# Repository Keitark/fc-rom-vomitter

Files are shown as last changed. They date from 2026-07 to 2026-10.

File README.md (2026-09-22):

# FC ROM Vomitter

[日本語](README_JA.md) · [Schematic PDF](docs/nescart-fc-schematic.pdf) · [Manufacturing release](manufacturing/rev-a-fc/)








**Upload an NROM homebrew ROM from a phone, load it into SRAM, and run it on a Japanese Famicom.** No EPROM programmer, cartridge swapping, or battery-backed memory.

The native 60-pin Famicom Rev A-FC is the primary design. A frozen 72-pin NES-001 predecessor is preserved under [`experimental/nes/`](experimental/nes/) for comparison and further development; it is not part of the FC manufacturing release. A separately isolated [ESP32-S3 two-bank Mapper-3 experiment](experimental/mapper3-esp32/) records the post-release bodge wiring, firmware, tests, and limited bench evidence without changing the stable NROM release.

## Actual board views

| Component / parts side | Artwork side |
|---|---|
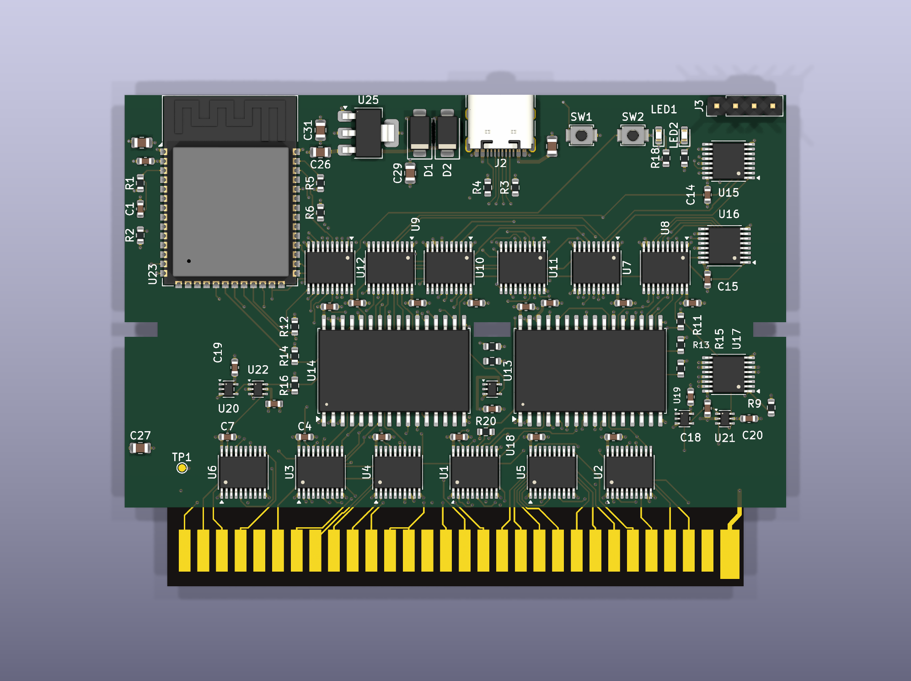
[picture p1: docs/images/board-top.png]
Actual KiCad component-side render of Rev A-FC
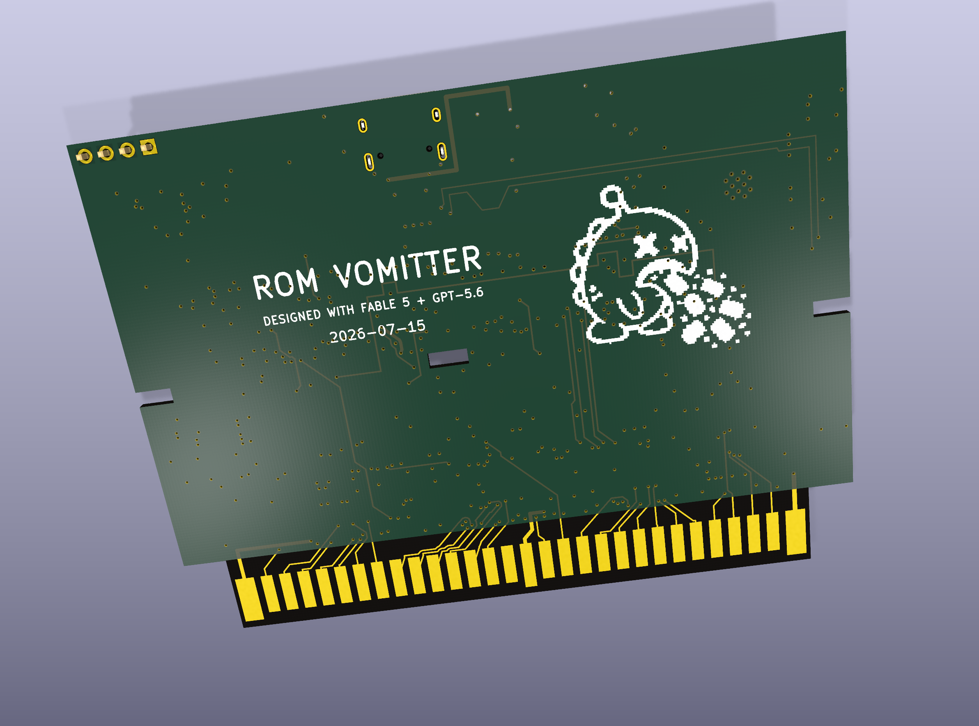
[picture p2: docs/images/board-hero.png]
Actual KiCad artwork-side render of Rev A-FC
|  |  |

> [!WARNING]
> Rev A-FC has a fabrication-complete design and build-tested firmware, but the assembled hardware has not completed bench validation. Do not insert an untested board into a Famicom. The 10 mm taller PCB also needs a custom shell; original cartridge-shell compatibility is not claimed.

## What it does

1. The ESP32-S3 creates a Wi-Fi access point and browser upload page.
2. An uploaded mapper-0 `.nes` image is CRC-checked and committed to one of two flash slots.
3. At power-up, the ESP32 isolates the console bus, copies PRG and CHR data into SRAM, and verifies every byte.
4. The bus changes to RUN ownership and the blue LED becomes solid.
5. Press the **Famicom console's red RESET button** to start the game.

For bench and unattended workflows, the firmware also supports [USB-C direct
upload and optional HTTPS cloud polling](docs/rom-delivery.md). All delivery
modes use the same validated atomic flash and SRAM-loading path.

Unlike the front-loader NES, the Famicom has no CIC lockout circuit. The cartridge therefore cannot automatically hold and release console reset; the explicit RESET press is part of the Rev A-FC user flow.

```mermaid
flowchart LR
    phone["Phone / laptop"] -->|"Wi-Fi upload"| esp["ESP32-S3"]
    esp --> flash["Two atomic flash slots"]
    flash -->|"CRC-verified copy"| sram["PRG + CHR SRAM"]
    esp -->|"LOAD / RUN ownership"| buffers["74LVC bus isolation"]
    sram --> buffers --> edge["60-pin Famicom edge"]
    edge --> console["Famicom CPU + PPU"]
    reset["Press console RESET"] -.-> console
```

## Hardware at a glance

| Area | Rev A-FC |
|---|---|
| Console | Japanese Famicom 60-pin cartridge slot |
| Supported image | iNES mapper 0 / NROM, 16 or 32 KiB PRG, 8 KiB CHR |
| Loader | ESP32-S3-WROOM-1-N8, SoftAP + browser upload |
| Game storage | Two atomic slots in ESP32 flash |
| Console memory | Two CY62128 128K × 8 SRAMs |
| Bus safety | 74LVC245 isolation with fail-safe LOAD/RUN defaults |
| PCB | 6 layers, 90.0 × 66.8 mm envelope, 1.2 mm, 60 gold fingers |
| Audio | Famicom sound loop through fitted 0 Ω R20 |
| Power/debug | Console 5 V plus USB-C bench power and native USB flashing |

The board keeps the standard-width tongue, connector datum, notches, centre slot, and 1.2 mm mating thickness. Only the edge opposite the fingers is extended by 10 mm for routing space.

## Project status

| Gate | Status | Evidence |
|---|---|---|
| Schematic ERC | **PASS** — 0 errors, 8 reviewed warnings | [`erc.json`](manufacturing/rev-a-fc/evidence/erc.json) |
| PCB connectivity | **PASS** — 0 raw opens | [`drc-classified.json`](manufacturing/rev-a-fc/evidence/drc-classified.json) |
| Classified DRC | **PASS** — 0 real errors | [`drc-classified.json`](manufacturing/rev-a-fc/evidence/drc-classified.json) |
| Layout policy | **PASS** — 0 failures | [`layout-check.txt`](manufacturing/rev-a-fc/evidence/layout-check.txt) |
| CPL registration | **PASS** — 79 fitted references, 0 unresolved | [`cpl-audit.txt`](manufacturing/rev-a-fc/evidence/cpl-audit.txt) |
| Firmware host tests/build | **PASS in preparation; continuously checked by CI** | [workflow](.github/workflows/validate.yml) |
| Electrical/mechanical bench validation | **PENDING** | [bring-up checklist](docs/bring-up.md) |

“0 opens” is not treated as completion by itself. The release also requires classified DRC, power continuity, reference-plane checks, silkscreen review, CPL registration, and visual inspection.

## Quick start for developers

### Firmware

Install [PlatformIO](https://platformio.org/), then:

```powershell
cd firmware
pio run -e esp32-s3
```

Host-test the iNES parser, CRC, and atomic-slot selection:

```powershell
cmake -S host_tests -B host_tests/build
cmake --build host_tests/build --config Release
ctest --test-dir host_tests/build -C Release --output-on-failure
```

The default development access-point password is `vomit-roms`. Change it through menuconfig before using the cartridge in a shared or public environment.

### Hardware

Open [`hardware/nescart-fc.kicad_pro`](hardware/nescart-fc.kicad_pro) in KiCad 10. The checked-in PCB is the exact revision used to create the public manufacturing package.

The schematic is generator-backed:

```powershell
python hardware/tools/gen_sch.py
```

Edit the netlist tables in `gen_sch.py`; do not hand-edit generated connectivity in the `.kicad_sch` files. See [hardware/README.md](hardware/README.md) before regenerating anything.

## Manufacturing release

[`manufacturing/rev-a-fc/`](manufacturing/rev-a-fc/) contains:

- revision-locked Gerber + drill ZIP;
- engineering and JLCPCB-format BOM/CPL files;
- CPL registration audit and assembly drawing;
- DRC/ERC/layout/silkscreen evidence;
- top and bottom manufacturing views and paste-stencil preview;
- a SHA-256 manifest checked in CI.

These files are published for review and reproducibility, **not as a recommendation to order an unvalidated board unchanged**. Read [manufacturing notes](docs/manufacturing.md) and the [bench bring-up gate](docs/bring-up.md) first.

## Experimental NES variant

[`experimental/nes/`](experimental/nes/) preserves the earlier 72-pin front-loader NES-001 design. It uses an ATtiny CIC clone to hold the console in reset while the ESP32 loads SRAM, which is materially different from the manual-reset FC flow. The snapshot passed its recorded schematic and PCB checks, but its assembly-placement gate and hardware validation are incomplete, so it is intentionally **not fabrication-ready**.

## Experimental Mapper 3 modification

[`experimental/mapper3-esp32/`](experimental/mapper3-esp32/) documents an
ESP32-S3-only, two-bank CNROM modification applied to one assembled Rev A-FC
board. It adds no new processor: a core-1 IRAM polling loop observes CPU D0 and
the existing decoded control signals, then drives CHR SRAM A13 through GPIO36.

Host tests, the ESP32 build, Mapper-0 regression, and one two-bank Mapper-3
target passed their recorded checks. Electrical margin, worst-case timing,
long-run Wi-Fi stress, and multi-board repeatability remain `USER_REVIEW`.
This is a reproducible experiment, not a revised manufacturing release.

## Repository map

```text
hardware/                 KiCad 10 release source, libraries, models and core generators
firmware/                 ESP-IDF / PlatformIO loader firmware and host tests
manufacturing/rev-a-fc/   sanitized Gerber, BOM, CPL, evidence and hashes
experimental/nes/          frozen 72-pin NES-001 design snapshot (not released)
experimental/mapper3-esp32/ post-release two-bank CNROM bodge and firmware
docs/                     architecture, bring-up, manufacturing and licensing notes
scripts/                  repository and release-integrity checks
```

## Documentation

- [Architecture and safety invariants](docs/architecture.md)
- [First-board bring-up](docs/bring-up.md)
- [Browser, USB-C and cloud ROM delivery](docs/rom-delivery.md)
- [Manufacturing and release interpretation](docs/manufacturing.md)
- [FC60 pin map](hardware/docs/pinout-fc.md)
- [Layout and electrical guidance](hardware/docs/layout-electrical-guidance.md)
- [Licensing and attribution](docs/licensing.md)
- [Japanese README / 日本語](README_JA.md)
- [Experimental ESP32-S3 Mapper 3 modification](experimental/mapper3-esp32/)

## License and credits

This is a dual-licensed repository. Software and original general documentation are MIT. KiCad hardware design files, manufacturing artifacts, and designated visual/model assets are CC BY-SA 4.0; see [the exact scope and attributions](docs/licensing.md).

Connector behavior and dimensional research reference the community-maintained [NESdev Wiki](https://www.nesdev.org/wiki/Cartridge_connector) and the [NES/Famicom cartridge dimensions project](https://github.com/Gumball2415/NES-Famicom-Cartridge-Dimensions). The SRAM STEP model is from KiCad Packages3D and retains its upstream license and exception.

Famicom and Nintendo are trademarks of Nintendo. This independent project is not affiliated with or endorsed by Nintendo. Use homebrew software you have the right to run.

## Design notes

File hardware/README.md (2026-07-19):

# Hardware source

`nescart-fc.kicad_pro` is the KiCad 10 entry point. The checked-in PCB and
schematic match the SHA-256 values recorded in
`../manufacturing/rev-a-fc/release-manifest.json`.

## Sources of truth

- Electrical connectivity: `tools/gen_sch.py` and its generated hierarchical sheets.
- FC60 edge geometry: `tools/fc_geometry.py` and `tools/gen_edge_footprint.py`.
- Released routing/placement: `nescart-fc.kicad_pcb` (revision-locked snapshot).
- Fabrication constraints: `docs/DESIGN-CONSTRAINTS.md`.
- Part and placement mapping: `docs/sourcing-lock.csv` and `docs/cpl-overrides.csv`.

Do not hand-edit generated schematic connectivity. Regenerate it from the
tables in `gen_sch.py`, then compare the resulting pin/net map and run ERC.

## Required release gates

1. ERC has zero errors; expected warnings must be reviewed.
2. Raw unconnected items are zero.
3. Classified DRC has zero real errors and zero power disconnects.
4. `layout_check.py` reports `0 FAIL`.
5. Both sides are rendered and visually inspected.
6. Every fitted CPL reference is reconciled and visually checked after vendor import.
7. Gerber, drill, BOM, CPL and evidence files come from the same PCB revision.

KiCad's bundled Python is required for scripts importing `pcbnew`.

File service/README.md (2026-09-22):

# Cloudflare exhibition service

This Worker implements the planned anonymous ROM queue in
[`docs/expo-cloud-service.md`](../docs/expo-cloud-service.md). It stores queue
metadata in D1 and validated iNES payloads in a private R2 bucket. No ROM is
included in this repository or its tests; the integration test synthesizes a
minimal byte-pattern fixture.

## Visitor page

The public page is **Famicom Game Drop**. It defaults to Japanese, has an
English switch and explains the three-step upload flow. It translates upload
errors and job states while keeping
the existing `/api/public/jobs` protocol. A status URL can be saved and
reopened; the token stays in the URL fragment.

Visitor form uploads appear in the public gallery by default. The uploader
can instead check **Keep this game private**; raw API uploads remain private.
An optional comment is displayed only for public games. Names are visible to
staff only unless the uploader separately opts to publish one. The gallery
does not expose ROM download URLs. Existing one-hour expiry is unchanged.

The page explicitly says that physical cartridge pickup is unverified. A
successful upload proves validation and queue admission, not that the game
has changed on a physical Famicom.

## Operator-controlled dispatch

Open `/operator` and enter the operator token. The page is Japanese-first with
an English switch. The token is submitted once and never saved in browser
storage. A 12-hour, HttpOnly, same-site session cookie keeps this browser signed
in across reloads; use **Sign out** on a shared machine. A valid visitor upload
remains queued but **unreleased**. The operator presses **Send next game** to
release exactly one waiting item. A second item cannot be released while one
is queued for the cartridge, claimed, downloading, or deferred. The cartridge
polls `/api/device/v2/next` and claims only released work. Staff may pause the
queue or cancel a waiting item. A powered-on console may be interrupted only
when the cartridge advertises that its locally tested configuration permits
it; staff must then press the Famicom RESET button after the new image is
verified. This last step is not yet physically validated.

The operator can also withdraw a public-gallery listing without cancelling
the source ROM submission or already queued plays. Names and comments in the
operator queue require the operator token and are cleared when the source job
expires or is cancelled.

## Local verification

```powershell
cd service
npm install
npm run check
npm test
```

The integration test starts `wrangler dev` with local D1/R2 emulation and
exercises upload, validation, duplicate rejection, HMAC authentication, replay
rejection, operator release, duplicate-release prevention, powered-console
policy, job lease, private download, idempotent result, public status,
default-public/private upload options, name privacy, gallery withdrawal, and
operator pause/resume, one-time browser login, session expiry/revocation, and
same-origin checks for cookie-authenticated actions.

## Local interactive service

Create an ignored `service/.dev.vars`:

```dotenv
DEVICE_HMAC_SECRET=replace-with-at-least-32-random-characters
OPERATOR_TOKEN=replace-with-a-separate-random-token
RATE_LIMIT_SALT=replace-with-a-third-random-value
```

Then run:

```powershell
npm run db:local
npm run dev
```

Open `http://127.0.0.1:8787`. Do not use real credentials or copyrighted ROM
images in repository tests.

## Staging deployment

Provision one D1 database and one private R2 bucket, put the D1 identifier in
`wrangler.toml`, apply all migrations remotely, set all three secrets with
`wrangler secret put`, then deploy. The `workers.dev` hostname is the staging
endpoint; attaching a custom domain is a separate, reviewed step.

After deployment, verify the real D1/R2/HMAC path using a generated mapper-0
fixture. Supply secrets only through the process environment; the script does
not print them or use a copyrighted ROM:

```powershell
$env:SERVICE_URL = "https://your-staging-worker.workers.dev"
$env:DEVICE_HMAC_SECRET = "..."
$env:OPERATOR_TOKEN = "..."
npm run test:remote
```

The device signs every request using the canonical string defined in
`src/auth.ts`. Secrets are per-device deployment configuration and must not be
compiled into public firmware artifacts.

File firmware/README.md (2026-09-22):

# ROM Vomitter FC firmware

ESP-IDF firmware for the released `hardware-fc` ESP32-S3-WROOM-1-N8 board.
The new exhibition queue client builds, but remains **hardware-unvalidated**:
building it does not mean it has been flashed to, or tested on, the cartridge.

## Current verification status

- **PASS:** host tests for iNES normalization, CRC32, and atomic slot selection.
- **PASS:** ESP32-S3-N8 target build with PlatformIO and ESP-IDF 5.5.0.
- **PENDING HARDWARE:** native-USB flashing, GPIO timing/polarity, SRAM walking-bit
  tests, current/thermal measurements, Wi-Fi operation, and Famicom boot.

A successful build proves that the firmware compiles and fits. It does not prove
the released PCB's electrical behavior, so the first-board gate below remains
mandatory.

## Implemented preparation

- Released FC GPIO map from `hardware-fc/tools/gen_sch.py`.
- Safe LOAD/RUN sequencing with MCU and console data buffers disabled before
  ownership changes.
- Strict mapper-0 iNES validation: 16/32 KiB PRG, 8 KiB CHR, horizontal or
  vertical mirroring, optional trainer stripping, NROM-128 PRG mirroring.
- Two 64 KiB flash slots. Payload is written and CRC-verified before the commit
  metadata is written, so power loss cannot erase the previous valid image.
- PRG and CHR SRAM write plus byte-for-byte readback verification.
- Wi-Fi SoftAP and browser upload page at `http://192.168.4.1`.
- FC-specific UX: solid blue means READY; then press the **console's red RESET
  button**. Slow blink means no image; fast blink means transfer/load.
- Conservative 11 dBm Wi-Fi TX cap until rail and regulator measurements exist.
- Optional exhibition mode: signed polling of the Cloudflare queue. A visitor
  upload waits until an operator presses **Send next game**; the cartridge then
  fetches one released ROM, independently verifies its bytes and hashes, and
  uses the same flash/SRAM installation path. The original fixed-URL pull mode
  remains selectable.

The default SoftAP password is `vomit-roms`; change it in menuconfig for any
public or shared deployment.

## Exhibition queue configuration (not yet tested on hardware)

In `menuconfig`, enable cloud pull and its **operator-dispatched queue** mode.
Set the venue Wi-Fi SSID/password, the service origin (for example,
`https://fc-rom-vomitter-expo-staging.keitark.workers.dev`), a unique device ID,
and a 32–256 character device HMAC secret matching the Worker's private secret.
Enable **allow console reload** only for a supervised bench test after proving
bus isolation and reset behavior with an oscilloscope. When enabled, an
operator dispatch can interrupt a powered-on game; after READY, press the
Famicom's RESET button. Otherwise the cartridge waits for a safe power state.

The device credentials are compile-time settings. Never commit a generated
`sdkconfig` containing them or distribute a credential-bearing binary. The
`esp32-s3-cloud-ci` build uses dummy credentials solely to check compilation.
The SoftAP upload remains the local recovery path; the public Worker cannot
directly push bytes to a cartridge that is offline or not running this mode.

The queue client here is built from the mapper-0 firmware. The separately
patched Mapper 3/CNROM cartridge runs a timing-critical bank-switch task and
**must not be flashed with this binary**: its mapper support is not integrated
into this target. Before an exhibition deployment, merge the queue client into
that firmware, keep HTTP on core 0 and the bank-switch loop on core 1, then
measure bank-switch correctness and 3.3 V rail behavior during idle polling,
download, and powered-console reload. Wi-Fi/polling must not be called
``no impact'' merely because this target compiles.

## Build without a board

```powershell
cd firmware
pio run -e esp32-s3
```

Host-test the parser, CRC and atomic-slot selection:

```powershell
cmake -S host_tests -B host_tests/build -G "Visual Studio 16 2019" -A x64
cmake --build host_tests/build --config Release
ctest --test-dir host_tests/build -C Release --output-on-failure
```

## First-board bring-up gate

Do not insert an untested board into a Famicom. Use current-limited USB bench
power first:

```powershell
cd firmware
pio run -e esp32-s3 -t upload --upload-port COMx
pio device monitor --port COMx --baud 115200
```

Replace `COMx` with the native-USB port. If automatic download mode does not
start, hold **BOOT**, tap **ESP RST**, release **BOOT**, and retry the upload.

1. Inspect 5 V and 3.3 V rails, regulator temperature, and idle current.
2. Flash over native USB using BOOT + ESP RST; confirm UART/USB logs.
3. With no console attached, verify the blue LED patterns and SoftAP upload.
4. Probe `LOAD_MODE`, both MCU enable lines, `/WE`, and `/OE`; confirm no
   simultaneous MCU/console ownership.
5. Run walking-bit and address tests on both SRAMs before loading a ROM.
6. Confirm flash-slot power-loss recovery by interrupting an upload.
7. Only then insert with console power off, wait for solid READY, and press the
   console RESET button to run the test ROM.

The loader deliberately remains in isolated LOAD topology when only USB power
is present. A console-power rising event reloads/verifies SRAM before RUN.

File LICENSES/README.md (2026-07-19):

# License map

- `../LICENSE`: MIT for software and original general documentation.
- `CC-BY-SA-4.0.txt`: Creative Commons Attribution-ShareAlike 4.0 International for hardware design and designated assets.
- Per-file headers and `../docs/licensing.md` take precedence for third-party material.

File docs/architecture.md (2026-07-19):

# Architecture and safety invariants

## Operating model

The Famicom starts much faster than the ESP32-S3. Rev A-FC therefore does not
promise an automatic clean boot. During loader startup, hardware defaults keep
the MCU and console from driving the SRAM buses simultaneously. Once a valid
image is loaded and verified, the user starts execution with the console RESET
button.

```mermaid
sequenceDiagram
    participant FC as Famicom
    participant Gate as Buffer ownership logic
    participant ESP as ESP32-S3
    participant Flash as Atomic flash slots
    participant SRAM as PRG/CHR SRAM

    FC->>Gate: Console power rises
    Gate->>FC: Console bus isolated from SRAM
    ESP->>Flash: Select last valid committed image
    ESP->>SRAM: Copy PRG + CHR in LOAD mode
    ESP->>SRAM: Byte-for-byte readback + CRC
    ESP->>Gate: Change ownership only while MCU/console are isolated
    Gate->>FC: RUN mode; SRAM visible to console
    ESP-->>FC: Solid blue READY indication
    Note over FC: User presses console RESET
    FC->>SRAM: Fetch reset vector and execute ROM
```

## Non-negotiable invariants

- Console-side buffers and MCU-side drivers must never be enabled together.
- Bus ownership changes only through the isolated transition state.
- All ESP32 bus GPIOs remain Hi-Z or at defined safe levels until firmware takes control.
- SRAM contents are disposable; the committed ESP32 flash slot is authoritative.
- SRAM readback must pass before RUN mode.
- USB-only bench power must not backfeed the console edge.
- The Famicom audio path must return through fitted R20 (0 Ω), or the console may be silent.
- The console-facing tongue, notches, centre slot, J1 datum and 1.2 mm thickness are mechanical constraints, not layout suggestions.

## Supported ROM model

Rev A-FC deliberately implements mapper 0 only:

- iNES input;
- 16 KiB or 32 KiB PRG ROM;
- 8 KiB CHR ROM;
- horizontal or vertical nametable mirroring;
- optional trainer stripping;
- NROM-128 PRG mirroring.

Other mappers, save RAM, expansion audio mixing and instant-on stub ROMs are future work.

## Power

The board can be powered from the console or USB-C for isolated bench work.
The current release uses an AMS1117-class 3.3 V regulator and must pass current,
dropout and thermal measurement before console use. A successful firmware build
or DRC result is not evidence of a safe power budget.

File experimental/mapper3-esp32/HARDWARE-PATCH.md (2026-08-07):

# ESP32-only two-bank CNROM hardware patch

## Scope and warning

This rework exposes three mapper-observation inputs to the onboard ESP32-S3
and lets GPIO36 drive CHR SRAM A13. It is for an already-built Rev A-FC board.
It is not a fabrication-ready schematic or PCB revision.

Disconnect USB and remove the cartridge from the console before continuity or
soldering work. Confirm every point by KiCad net name and continuity on the
actual board; reference designators alone are insufficient.

## Preferred signal wiring

| ESP32 signal | Source / destination | Preferred implementation |
|---|---|---|
| GPIO36 output | U14 pin 28, CHR A13 | Lift U14 pin 28 from its GND pad; wire TP1 to the isolated lead |
| GPIO42 input | CPU D0 | Lift the unused U2 pin 9 from GND, wire CPU D0 to that lead, then wire U2 pin 11 to U23 pad 35 / GPIO42 |
| GPIO43 input | `ROMSEL_inv` | U19 pin 4 to J3 pin 2 |
| GPIO44 input | `PRG_EN_n` | U21 pin 4 to J3 pin 3 |

U2 is the preferred CPU-D0 path because its spare channel performs the
5 V-to-3.3 V interface on the released board. Do not connect raw CPU D0
directly to an ESP32-S3 GPIO.

GPIO43 and GPIO44 reuse J3 UART pins. Do not attach a UART adapter while the
mapper firmware is running.

## Tested rescue path after U2 lead damage

On the single bench board, U2 pin 9 was lost during rework. The temporary
repair connected CPU D0 through 4.7 kΩ to the GPIO42 node, with 10 kΩ from
that node to GND. U2 pin 11 was disconnected from GPIO42.

```text
CPU D0 ---- 4.7 kΩ ----+---- GPIO42
                       |
                      10 kΩ
                       |
                      GND
```

This topology is recorded because it was the path used for the bench result.
It is **not the recommended reproducible modification**: nominal divider
voltage is close to the upper end of 3.3 V logic, resistor tolerance and the
real console high level matter, and the edge is weaker than with a buffer.
Measure the powered node with the intended console before use. A future PCB
revision should use a specified 5 V-tolerant translator or latch instead.

## Why the qualifier works

U21 combines `ROMSEL_inv`, CPU R/W, and RUN. During RUN, a selected read makes
`PRG_EN_n` low; a selected write keeps it high. The firmware therefore treats
`ROMSEL_inv=1` and `PRG_EN_n=1` as the write candidate and confirms it with an
immediate second GPIO snapshot before committing CPU D0 to GPIO36.

The second sample is important because the beginning of a read can briefly
look like a write while U21 propagates, while a long multi-sample filter was
observed to miss real short writes.

## Rework procedure

1. Remove all power and verify the board is outside the console.
2. Lift U14 pin 28 from GND. Verify the lead is open to GND and not shorted to
   pins 27 or 29.
3. Wire TP1/GPIO36 to the isolated U14 pin 28 lead.
4. Implement the preferred U2 CPU-D0 path above. Use the divider only as a
   documented repair when the buffered path is unavailable and its voltage
   has been measured.
5. Wire U19 pin 4 to J3 pin 2/GPIO43.
6. Wire U21 pin 4 to J3 pin 3/GPIO44.
7. Keep wires short, secure them mechanically, and keep them outside the
   Famicom contact tongue and ESP32 antenna keepout.

## Mandatory checks

1. With power off, confirm the lifted U14 lead is isolated from GND and its
   neighbors.
2. Confirm GPIO42 is not directly connected to the 5 V CPU bus.
3. Confirm all three input points and GPIO36 by continuity to their named
   nets, including correct J3 pin order.
4. Power from a current-limited USB source first; stop for abnormal current or
   heating.
5. Measure GPIO42/43/44 powered levels against ESP32-S3 limits.
6. Verify both U14 8 KiB regions in LOAD mode.
7. Run Mapper 0 and confirm no display or audio regression.
8. Exercise repeated bank 0/1 writes and inspect `/api/status` counters.
9. Save and inspect `/api/mapper-trace` around any remaining mismatch.
10. Treat multi-board timing and long-run Wi-Fi stress as open qualification
    work; a hardware latch remains the robust fallback.

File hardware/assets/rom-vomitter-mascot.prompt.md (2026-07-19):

# ROM Vomitter mascot source

- Model: `gpt-image-2`
- Generated: 2026-07-15
- Purpose: source artwork for the Famicom PCB bottom silkscreen

Prompt:

> Create an original funny retro electronic mascot for a PCB silkscreen: a
> round creature with two large, unmistakable X-shaped eyes, leaning forward
> and vomiting rectangular ROM integrated circuits and small pixel/data
> blocks. Pure black line art on a white background, thick connected strokes,
> minimal shapes, high contrast, vector/stencil friendly, readable when
> reduced to about 22 mm wide. No text, no gray, no gradients, no shadows, no
> watermark, and no resemblance to an existing copyrighted character.

`gen_rom_vomitter_logo.py` converts the raster source into a reproducible,
manufacturable KiCad silkscreen footprint. The generated PNG itself is not
sent directly to fabrication.

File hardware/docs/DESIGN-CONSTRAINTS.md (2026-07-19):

# nescart-fc Rev A-FC manufacturing constraints

These constraints accompany every fabrication and assembly quote. Browser or
vendor-side edits may not override them without a new reviewed release.

## PCB

- Quantity: 5 PCBs; assemble 3.
- Copper layers: 6.
- Finished thickness: 1.2 mm.
- Outline: irregular 90.0 mm x 66.8 mm maximum envelope with the released
  notches, centre slot, 78.4 mm tongue, and 10 mm custom-shell extension.
- Solder mask: green.
- Gold fingers: yes, wear-capable finish on the 60-pin Famicom edge.
- Edge bevel: 45 degrees on the insertion edge.
- Preserve the exact Edge.Cuts and J1 datum. No vendor outline normalization,
  rounding, panel tab, tooling-hole, or rail change may enter the finished PCB.
- Standard routed vias: 0.50/0.30 mm through vias. Flag every drill below
  0.30 mm and every quote option that triggers a premium process.
- No paid controlled-impedance option is required for this cost-controlled
  revision. Preserve the released USB differential routing and continuous GND
  reference; do not change trace geometry in the order interface.
- The 10 mm top extension is owner-approved for a custom 3D-printed shell.
  Compatibility with an original Famicom shell is not claimed.

## Assembly

- Assembly side: top only.
- DNP: J1 edge connector, J3 debug header, TP1 test pad, and LOGO1 artwork.
- Use the exact released BOM and calibrated CPL hashes.
- Design-critical parts requiring explicit substitution approval:
  `ESP32-S3-WROOM-1-N8`, `CY62128EV30LL-45SXIT`, and `SN74LVC245APWR`.
- CPL import must pass complete reference reconciliation and visual pin-1,
  polarity, terminal, tab, connector, and body-alignment review before user
  placement approval.

## Physical stencil

- Order together with the PCB as a custom-size frameless, top-only stencil.
- Outer size: 130 x 110 mm for the 90.0 x 66.8 mm PCB envelope. This leaves
  roughly 20 mm working margin around the design; do not cut the stencil to the
  exact PCB outline.
- Thickness: 0.12 mm.
- Source: released F.Paste Gerber only.
- Fiducials: none unless a later release adds matching fiducials.
- Remark: `Follow the top solder-paste layer only. Keep the PCB artwork centered in the 130 x 110 mm custom frameless stencil.`

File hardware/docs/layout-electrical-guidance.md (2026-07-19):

# Rev A-FC layout and electrical guidance

The annotations below are design inputs for layout review, not a substitute
for measured hardware validation.

## Layers and return paths

- [TARGET] First closure uses six copper layers.
- [TARGET] In1.Cu is an uninterrupted GND reference plane.
- [TARGET] In4.Cu is a +3V3 plane; do not route signals on either dedicated
  plane layer.
- [TARGET] Route signals on F.Cu, In2.Cu, In3.Cu, and B.Cu.
- [TARGET] A later four-layer cost experiment may use F.Cu / In1 GND /
  In2 signal / B.Cu.  Do not consume both inner layers as dedicated planes.
- [SPEC] No copper, vias, or traces in the ESP32 antenna keepout, Famicom
  tongue keepout, side notches, or centre boss slot.

The six-layer baseline is driven by measured routing density: the frozen NES
route used all four signal layers, while the FC board retains roughly the same
net count and single-sided functional corridors. The 10 mm top extension adds
placement/routing area but does not itself prove a four-layer route. The layer
choice is not justified merely by the nominal bus clock.

## Geometry and fabrication cost

- [TARGET] Keep the Famicom insertion geometry fixed: 90.0 mm body width,
  78.4 mm tongue width, existing notches/slot, and unchanged J1 datum.
- [TARGET] Use the user-approved 10.0 mm extension only at the board edge
  opposite the gold fingers; do not widen or move the connector tongue.
- [SPEC] The owner approved a custom 3D-printed shell for the taller outline
  on 2026-07-15. Preserve the standard tongue, notches, centre slot, J1 datum,
  and 1.2 mm console-mating thickness; do not claim original-shell fit.
- [TARGET] Standard through via: 0.5/0.3 mm or 0.6/0.3 mm diameter/drill.
- [SPEC] Do not use 0.3/0.15 mm fine vias without a separately approved cost
  and manufacturability experiment.
- [TARGET] 0.20 mm general signal width; increase power paths from calculated
  current and temperature-rise requirements.
- [SPEC] Board thickness is 1.2 mm for cartridge fit.
- [SPEC] The edge contacts require a wear-capable hard-gold/gold-finger
  process; ordinary ENIG on the rest of the board is not a substitute.

## Buses and control signals

- [TARGET] CPU/PRG group operates near 1.79 MHz; group length spread <=25 mm.
- [TARGET] PPU/CHR group operates near 5.37 MHz; group length spread <=15 mm.
- [TARGET] ESP32 load bus firmware target <=10 MHz; group spread <=25 mm.
- [TARGET] USB Full-Speed D+/D- differential impedance 90 ohm +/-10%, pair
  skew <=1 mm, no stubs, and minimize vias.
- [TARGET] Preserve edge -> console buffer -> SRAM and ESP -> MCU buffer ->
  SRAM placement order.  Keep `/OE`, `/WE`, and `/CE` direct.
- [TARGET] Prefer short, monotonic routes; do not add trombone tuning merely
  to make low-frequency buses numerically equal.

Fast 74LVC edge rates, not only clock frequency, make continuous return paths
and short stubs important.

## Power and thermal signoff

- [TARGET] Size +5V and +3V3 source trunks for at least 0.8 A peak.
- [TARGET] Reserve at least 0.5 A transient capability for the ESP32 branch.
- [TARGET] Budget <=60 mA for each SRAM and 0.1 A for logic/LED overhead until
  measured values replace these provisional allocations.
- [TBD-MEASURE] Measure console supply capability, all rail currents, ESP32
  upload transients, and regulator temperature before fabrication signoff.
- [TBD-MEASURE] AMS1117 dissipation at the worst accepted input/current point
  requires thermal proof; 0.8 A with a 1.7 V drop would be about 1.36 W.
- [TARGET] Each IC has a local 100 nF capacitor in the VCC escape path and a
  short independent GND-via return.  Place bulk capacitance at each source
  entry and at the ESP32 branch.

## Release gates

Release requires all of the following, independently:

1. Zero unexplained raw opens and zero real power disconnects.
2. Zero real DRC errors after classified review; zero-open alone is invalid.
3. Visual inspection of routing, planes, notches, slot, tongue, USB contact
   row, ESP antenna region, silkscreen, and 3D mechanical fit.
4. CPL registration and orientation inspection for every fitted component.
5. Separate user approvals for substitutions, placement, final price, and
   payment.

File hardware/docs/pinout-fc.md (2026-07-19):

# Famicom 60-pin interface and mechanical baseline

This is the implementation record for `nescart-fc` Rev A-FC.  The frozen
NES-001 design under `hardware/` remains unchanged.

## Mechanical baseline

- [SPEC] Standard Japanese Famicom cartridge PCB body: 90.0 mm wide.
- [TARGET] Rev A-FC keeps that 90.0 mm width and extends only the edge
  opposite the gold fingers by 10.0 mm to create routing and component area.
  The connector tongue, side notches, centre slot, and J1 datum do not move.
- [SPEC] Connector tongue: 78.4 mm wide, 10.7 mm long.
- [SPEC] PCB thickness: 1.2 mm.
- [SPEC] Contact pitch: 2.54 mm.
- [SPEC] The body side notches and the 5 x 2 mm centre boss slot are board
  voids: pads, copper, vias, and component bodies may not cross them.
- [SPEC] Board-label side is KiCad B.Cu; component side is F.Cu.
- [SPEC] The owner approved the 10 mm top extension for a custom 3D-printed
  shell on 2026-07-15. Compatibility with an original Famicom cartridge shell
  is intentionally not claimed. The standard-width tongue, J1 datum, notches,
  centre slot, and 1.2 mm mating thickness remain fixed for the console.

The tongue, width, side notches, centre slot, and connector datum were
reconstructed from the published HVC-TGROM dimensional reference rather than
copied from an upstream KiCad file. The 10 mm top extension is a project-specific
user-approved custom-shell target and is not present in that reference. Sources:

- <https://www.nesdev.org/wiki/Famicom_cartridge_dimensions>
- <https://github.com/Gumball2415/NES-Famicom-Cartridge-Dimensions>

## Electrical pin map

| Pin | nescart-fc net | Function |
|---:|---|---|
| 1 | GND | Ground |
| 2-13 | `CPU_A11` ... `CPU_A0` | CPU address |
| 14 | `CPU_RW` | CPU read/write |
| 15 | NC | `/IRQ`, unused in Rev A-FC |
| 16 | GND | Ground |
| 17 | `PPU_RD_n` | PPU read strobe |
| 18 | `CIRAM_A10` | Nametable mirroring select |
| 19-25 | `PPU_A6` ... `PPU_A0` | PPU address |
| 26-29 | `PPU_D0` ... `PPU_D3` | PPU data |
| 30 | `NES_5V` | Console +5 V, before the OR-ing diode |
| 31 | `NES_5V` | Cartridge-present/+5 V bridge to pin 30 |
| 32 | NC | M2, unused in Rev A-FC |
| 33-35 | `CPU_A12` ... `CPU_A14` | CPU address |
| 36-43 | `CPU_D7` ... `CPU_D0` | CPU data |
| 44 | `ROMSEL_n` | PRG ROM select |
| 45 | `FC_AUDIO_FROM_CONSOLE` | Audio from console/2A03 |
| 46 | `FC_AUDIO_TO_CONSOLE` | Audio returned toward RF/AV path |
| 47 | NC | PPU write, unused in NROM Rev A-FC |
| 48 | `PPU_A13_n` | CIRAM `/CE` |
| 49 | `PPU_A13_n` | Inverted PPU A13 |
| 50-55 | `PPU_A7` ... `PPU_A12` | PPU address |
| 56 | NC | Non-inverted PPU A13, unused |
| 57-60 | `PPU_D7` ... `PPU_D4` | PPU data |

Authoritative connector reference:
<https://www.nesdev.org/wiki/Cartridge_connector>.

## Design-specific decisions

- [SPEC] Pins 30 and 31 are tied together on `NES_5V`.  The tie is before D2,
  so USB power cannot backfeed the console through this bridge.
- [SPEC] R20, 0 ohm, is the only connection from pin 45 to pin 46.  Fit R20
  unless a future audio mixer replaces it.
- [SPEC] No CIC circuit is fitted on the native Famicom variant.
- [SPEC] U23 GPIO36 is a spare signal exposed only at TP1.
- [SPEC] R9 pulls `MIRROR_SEL` low at startup.
- [SPEC] SW1 is ESP reset (`ESP RST`), not console reset.

## Regeneration checks

Before accepting a regenerated board, assert all of the following:

1. J1 has exactly 60 physical pads.
2. Pins 1/16 are GND; 30/31 are `NES_5V`.
3. Pins 45/46 terminate only through R20.
4. Pins 48/49 share `PPU_A13_n`; pin 56 is unconnected.
5. Pin 60 is `PPU_D4`, never GND.
6. All four outline voids remain free of physical pads and copper.

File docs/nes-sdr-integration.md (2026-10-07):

# NES-SDR integration branch

This branch adds an experimental, no-hardware-modification NES-SDR path to
FC ROM Vomitter.

## Current integration status

Implemented:

- partial CHR SRAM write + readback verification;
- controller-locked CHR refresh API;
- NES-SDR renderer/SPC1/live component compiled inside the ESP-IDF project;
- manual synthetic spectrum endpoint:
  `POST /api/nes-sdr/demo-frame`;
- browser button for one synthetic graph refresh.

The RF task targets **5 Hz** (200 ms/frame) with a 50 ms capture window.
The GPL ESP-SDR backend is supplied by the separate `Keitark/nes-sdr`
combined-build workflow and is not vendored in this branch. Firmware built
from this branch alone reports the RF backend as unavailable.

The RF task holds the controller lock from capture through CHR readback, so
uploads and console power callbacks cannot change SRAM ownership mid-frame.
Each attempt logs capture, estimated render, refresh, total, and frame period in
microseconds. The SRAM log records CHR write, verify, and console blackout
times; a frame over 200 ms is flagged. These logs are instrumentation, not
hardware timing evidence.

SDR startup is serviced by the resident USB loader task (or `app_main` when USB
is disabled). The HTTP handler only marks the request as starting. After a
500 ms response grace period, the service stops HTTP and setup Wi-Fi before
allocating the 8 KiB RF task stack. This avoids requiring an additional large
contiguous block while setup resources are still allocated. If teardown or task
allocation fails, startup returns to the setup AP/HTTP page with RF state
`error`, allowing another attempt. Status includes `heap_free` and
`heap_largest`; serial logs show both before and after teardown.

Wi-Fi API failures inside the RF task before its first capture also schedule
setup recovery. The failed task exits first, and the resident service yields
500 ms to give the idle task time to reclaim its stack before rebuilding AP/HTTP.
Promiscuous mode is explicitly disabled during recovery. RF reports `error`
while recovery is pending; a new start is rejected until recovery finishes.
After capture has begun, the backend may have modified PHY registers; a fatal
console/image gate failure requires an ESP reset to return to setup and blocks
another RF start until reset.
Native fault-injection tests cover Wi-Fi start, power-save configuration,
promiscuous enable and channel setup failures. They simulate SDK errors and
task lifecycle; they do not emulate radio reception or WPA negotiation.

## First hardware test

1. Build/flash this branch.
2. Upload the NES-SDR NROM from `Keitark/nes-sdr`.
3. Press the Famicom RESET button once so the ROM initializes the PPU and parks
   the 2A03 at `$0200` internal RAM.
4. Open the ROM Vomitter web UI.
5. Press **NES-SDR demo frame**.
6. The spectrum bars should change without another Famicom RESET.

Each click advances the synthetic peaks by three FFT bins; a visible column
change may take several clicks.

## Read-only USB status

With a firmware containing the serial diagnostic command, send `RVST\n` over
USB or run `python firmware/tools/serial_status.py --port COM3`. The tool keeps
DTR/RTS low and does not reset the board. Close other serial monitors first.

Three lines report:

- `RVST`: RF state, completed RF attempts, successful RF refreshes, last result
  (`0` means success, `-1` means no completed RF cycle), most recent period in
  microseconds, and CRC of the last successfully written graph.
- `RVAP`: current Wi-Fi mode and associated AP station count. `null` means no
  AP. `clients=-1` plus an error means the query failed, not zero clients.
  `protocol=3` means 802.11b/g; `7` adds 802.11n. `bandwidth_mhz` is the actual
  configured AP bandwidth. `dhcp=started` confirms the DHCP server is running;
  it does not by itself establish that a client received an address. Failed
  radio/DHCP queries report their separate errors and unknown values.
- `RVROM`: installed-image, detected console-power and bus-exposure flags,
  image identity, free heap and largest block.

Only increasing `frames_ok` establishes continued successful RF capture,
render and verified CHR writes. Demo clicks do not increment these counters.
Around `period_us=200000` is the 5 Hz target. This still does not establish that
the Famicom TV is reading/displaying the graph correctly. Counters are atomic
individual readings, not a single locked transaction. The command works while
the setup AP is offline and never changes radio mode or SRAM ownership.

### Repeat page loads while monitoring USB

With the PC connected to the AP and holding a valid `192.168.4.x/24` address:

```text
python firmware/tools/web_stability.py --port COM3 --output ../web-stability-results
```

This downloads `/` and `/api/status` 30 times at five-second intervals, then
20 times at one-second intervals, using an HTTP session. Concurrent read-only
USB queries record RF/AP/heap status every three seconds. Requests have bounded
timeouts; CSV/JSON record response failures, times and heap ranges. Python
`requests` and `pyserial` are required. This tests HTTP delivery and status
responses; it does not execute browser JavaScript or validate rendering.

Keep raw serial output local: Wi-Fi driver logs can contain client identifiers.
If DHCP fails, resolve that network condition before interpreting HTTP timeouts
as web-server failures. A temporary static Wi-Fi address requires administrator
rights on Windows; record and restore the prior adapter configuration afterward.

### Setup AP compatibility

The setup AP explicitly uses 802.11b/g at 20 MHz by default. This avoids HT
negotiation/block-ack interoperability on older clients when the combined
memory profile disables AMPDU buffering. The observed BUFFALO baseline joined
as 802.11n/40 MHz and repeatedly tore down block-ack sessions while Windows
remained link-local; the Wi-Fi cause must be validated by automatic DHCP and
page tests after applying the correction.

`CONFIG_NESCART_AP_HT_ENABLE=y` optionally enables 802.11n, still at 20 MHz,
for qualified clients. Apply the same policy before AP start and recovery.
The STA interface, WPA2 password, channel and TX-power limit are preserved.
The RF task continues to stop the setup AP before local RF captures.

DHCP uses broadcast replies (`CONFIG_LWIP_DHCPS_STATIC_ENTRIES=n`). On the
observed Windows/BUFFALO client, Discover packets allowed unicast responses
but no Offer reached the client with the SDK's unicast/static-ARP mode enabled.
For existing local sdkconfig files, disable that option explicitly; defaults
only initialize settings absent from an existing configuration. Validate a
full Discover/Offer/Request/ACK exchange and automatic client address before
claiming this compatibility correction works on a given adapter.

Read-only USB status also emits `RVDHCP rx=... discover=... request=...
offer_prepared=... ack_prepared=...`. These cumulative counters observe IPv4
DHCP packets arriving on the AP interface and the SDK's reply-options hook.
The reply hook runs before allocating/transmitting the response: a prepared
Offer or ACK does **not** prove delivery. Compare counter changes during one
connection attempt with a client packet capture and its assigned IPv4 address.
The observer consumes no packets, appends no options, and creates no task or
heap allocation. Counters reset at ESP restart.

Normal HTTP uses three sessions with LRU purging, one-second receive timeouts
and two-second send timeouts. Raw ROM uploads have a shared 30-second receive
budget and close the session on rejection/failure, avoiding unread-body drains
on the single HTTP task. The browser pauses polling and disables duplicate
actions during a POST, and reports network/timeouts explicitly. Uploads still
serialize on the HTTP task while installing/verifying the image.
See [the source audit](esp32-wifi-source-audit.md#normal-ap-operation-before-sdr)
for the reproduced failure cases, memory limits and virtual-test boundaries.

`RVRX` counts AP frames and IPv4 frames passed from the driver to esp-netif,
and input errors returned by esp-netif. `CONFIG_ESP_NETIF_RECEIVE_REPORT_ERRORS=y`
enables those error results. A linker observer forwards the original buffer,
length, ownership token, and return value unchanged. Global heap failure counts
and the last requested allocation size help identify buffer pressure; they
are not restricted to the Wi-Fi subsystem. The failure callback allocates and
logs nothing. It is registered once before application startup and the AP
handle is bound before Wi-Fi starts.
`registered` and `registration_error` report the SDK AP RX callback binding
result, observed without replacing the callback or changing its arguments.

## ROM signature gate

The NES-SDR NROM embeds the fixed eight-byte signature `NES-SDR1` at CPU
address `$FFF0` (normalized PRG offset `0x7FF0`).

The demo endpoint verifies that signature before touching CHR SRAM. A normal
game or an older unsigned NES-SDR build is rejected with HTTP 409.

This is still an experimental live-write path, but accidental use on unrelated
ROMs is now blocked.

## Refresh target

The first live RF target is **5 Hz**:

```text
200 ms frame budget
  ~50 ms   RF capture / FFT
  remainder CHR render + write + verify + margin
```

If full 3072-byte write+verify does not fit comfortably, optimize the existing SRAM path or add dirty-tile updates before increasing the rate. The baseline must preserve bus-safety and readback verification.

## Expected behavior

During each refresh the existing LOAD/RUN logic temporarily removes CHR from
the PPU. A brief visual disturbance is expected.

After RUN is restored:

- the nametable should remain intact;
- the static NES-SDR font and red axis should remain intact;
- only graph tiles 0-191 should change;
- the CPU should remain parked in internal RAM;
- no RESET should be required.

## Scope / logic analyzer

For first hardware validation capture:

- `LOAD_MODE`
- `CHR_WE_n`
- `CHR_OE_n`
- one PPU-side CHR data bit

The released board's core invariant remains mandatory: console-side and
MCU-side SRAM bus drivers must never be enabled simultaneously.

## Licensing boundary

This branch contains an integration copy of the NES-SDR component with its
source/provenance documented under `firmware/components/nes_sdr/README.md`.

ESP-SDR source has **not** been copied into this branch. ESP-SDR is
GPL-3.0-or-later; the eventual combined RF build must preserve that license
boundary explicitly.

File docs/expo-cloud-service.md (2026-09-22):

# Operator-dispatched Expo cloud service

> **Status:** the Cloudflare service and a compile-checked ESP32 queue client
> are implemented. This queue client is **not yet validated on the physical
> cartridge**. The older fixed-URL pull and local SoftAP upload remain separate
> modes. Do not interpret a successful web upload as a physical game change.

This v2 service lets a visitor upload a compatible homebrew ROM from a public
web page without a ChatGPT account. The service validates and queues the ROM;
the cartridge then negotiates a compatible job, downloads it over HTTPS,
verifies it, installs it only in a safe hardware state, and reports the result.

The initial public implementation is intended for one supervised cartridge at
an exhibition, not as an unrestricted ROM-hosting service. Only ROMs that the
uploader is authorized to use may be submitted.

## Roles and trust boundary

| Role | Responsibility | Must not do |
|---|---|---|
| Anonymous visitor | Upload one ROM and retain the returned status URL | Address the cartridge directly or bypass validation |
| Public web service | Validate, deduplicate, queue, expire, and display status | Expose private object URLs or device credentials |
| Cartridge | Advertise capabilities, claim a compatible job, verify bytes, install safely, acknowledge result | Trust browser-supplied metadata or install while the console bus is unsafe |
| Operator | Release the next valid upload at a suitable point, pause/cancel the queue, and supervise console RESET | Release a second job before the first is resolved |

The visitor is anonymous to ChatGPT, but not unbounded: the service issues a
random, HttpOnly session cookie and a non-guessable status token. Device API
requests use a separate per-device secret and HMAC authentication.

## Visitor flow

1. Open the public Site and upload a `.nes` file.
2. The server parses the iNES header and validates the complete payload.
3. A valid, supported image is admitted to the FIFO queue, but not released
   to the cartridge yet.
4. At a play boundary, the operator presses **Send next game** on `/operator`.
   The cartridge's next signed poll claims that one released item.
5. The page receives a non-guessable status URL and polls for progress.
6. Status advances through `queued`, `claimed`, `downloaded`, `installed`, or
   a terminal `rejected`, `failed`, `expired`, or `duplicate` state.

No ChatGPT sign-in is required for this visitor flow. Operator controls and
deployment administration remain authenticated separately.

### HTTP surface

| Method and path | Caller | Result |
|---|---|---|
| `POST /api/public/jobs` | Visitor browser | Validate upload and return `202` with a status token, or a bounded `4xx` rejection |
| `GET /api/public/jobs/{status_token}` | Visitor browser | Return public job state without exposing the ROM or device identity |
| `POST /api/device/v2/next` | Authenticated cartridge | Report capabilities/state and receive `204` or one leased manifest |
| `GET /api/device/v2/jobs/{job_id}/rom` | Authenticated cartridge | Download bytes only for the device holding the active lease |
| `POST /api/device/v2/jobs/{job_id}/result` | Authenticated cartridge | Idempotently acknowledge `installed`, `unchanged`, `deferred`, or `failed` |
| `GET /api/operator/status` | Authenticated operator | Inspect queue counts, pause state, and last device state |
| `GET /api/operator/queue` | Authenticated operator | List active metadata without ROM bytes or uploader identity |
| `POST /api/operator/advance` | Authenticated operator | Release exactly one waiting job; reject while one is active |
| `POST /api/operator/pause` | Authenticated operator | Pause or resume device claims |
| `POST /api/operator/jobs/{job_id}/cancel` | Authenticated operator | Cancel a queued item |
| `POST /api/operator/clear-next` | Authenticated operator | Cancel and delete the oldest queued item |
| `POST /api/operator/clear-all` | Authenticated operator | Cancel and delete all queued items, bounded per request |

The public status token and the internal job ID are different values. A leaked
status URL must not authorize download, cancellation, or device operations.

## Admission gate

Automatic admission means automatic **validation**, not accepting arbitrary bytes
or authorizing an immediate change on the cartridge.
Before writing to private object storage, the service must verify:

- exact upload size limit and complete iNES header;
- supported mapper and PRG/CHR geometry reported by the cartridge capability
  profile;
- no trainer or NES 2.0 features unless that exact format is supported;
- SHA-256 and CRC32 computed by the service, never trusted from the browser;
- duplicate suppression against queued and active images;
- per-session/IP cooldown and a bounded queue (initial target: 20 jobs);
- content expiry and deletion (initial target: one hour after completion or
  expiry).

Rejected uploads must never receive a downloadable private-object URL.

## Device negotiation

The cartridge polls every 2–3 seconds in the exhibition profile. Each request
reports the state that affects compatibility and safe installation:

```json
{
  "device_id": "demo-cart-01",
  "firmware": "2.0.0-dev",
  "protocol": 2,
  "mappers": [0],
  "max_rom_bytes": 41488,
  "active_sha256": "...",
  "console_power": false,
  "console_exposed": false,
  "can_interrupt_console": false
}
```

The service returns `204 No Content` when no compatible work exists, or a
short-lived manifest:

```json
{
  "job_id": "01J...",
  "download_url": "https://service.example/api/device/v2/jobs/{job_id}/rom",
  "bytes": 40976,
  "sha256": "...",
  "crc32": "d98313b2",
  "ines": { "mapper": 0, "prg_kib": 32, "chr_kib": 8 },
  "expires_at": "2026-09-22T12:34:56Z"
}
```

The download endpoint is private and available only to the device holding the
short lease; it is not a public R2 object URL. The device must verify TLS,
byte count, SHA-256, CRC32, and parsed iNES fields.
It then passes the image through the existing inactive-slot commit, flash CRC,
SRAM readback, and console-isolation gates. If the cartridge has not explicitly
enabled supervised powered-console reload, the service leaves the job waiting
while console power is present. A claimed job can be `deferred` if power state
changes during the transfer. With powered reload enabled, gameplay freezes
during installation; staff must press Famicom RESET once the cartridge reports
READY. This configuration requires physical bus-safety testing before use.

After processing, the cartridge posts one idempotent result:

- `installed` — verified and made active;
- `unchanged` — already active with the same hash;
- `deferred` — valid but waiting for a safe console-power state;
- `failed` — rejected locally, with a bounded machine-readable error code.

Claims and acknowledgements need leases and idempotency keys so a reset or
lost response cannot install one queue item twice or strand it permanently.

## Cloudflare staging storage layout

The staging implementation uses a Cloudflare Worker, D1 for metadata and queue
state, and private R2 objects for ROM bytes. The API remains hosting-neutral;
the visitor UI can later be presented through ChatGPT Sites without moving the
device control plane.

| Store | Data |
|---|---|
| D1 | sessions, jobs, hashes, validation result, lease, device status, acknowledgement, expiry |
| R2 private bucket | validated ROM payload keyed by job ID/hash |

The public browser never receives permanent R2 credentials. The cartridge
receives only a short-lived download URL after an authenticated claim.

## Operational controls

- Staff-only release-next, pause/resume, and cancel controls. Clear-next and
  clear-all API endpoints are retained for recovery; a dedicated emergency-stop
  control is future work.
- Health view for last device poll, firmware/capabilities, active hash, queue
  depth, last error, and whether installation is deferred.
- Strict request/body limits, rate limiting, origin checks, structured audit
  events, and no storage of account, payment, Wi-Fi, or device secrets in logs.
- SoftAP browser upload remains the local recovery path if the cloud service or
  venue network is unavailable.

See [`service/README.md`](../service/README.md) for local verification and
staging deployment instructions.

## Implementation acceptance gates

This v2 design is ready to demonstrate only when:

1. invalid, oversized, unsupported, duplicate, and rate-limited uploads have
   automated negative tests;
2. device HMAC, expiry, replay, lease recovery, and idempotent acknowledgement
   tests pass;
3. power-on-console cases defer by default; a supervised interrupting profile
   has passed real-board isolation, SRAM, and RESET tests before use;
4. a queued job survives browser refresh and displays the final device result;
5. private ROM bytes cannot be listed or fetched anonymously;
6. operator release, pause, and powered-console behavior are tested on the real
   cartridge; and
7. the fixed-URL v1 mode and SoftAP fallback remain usable.

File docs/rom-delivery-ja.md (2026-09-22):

# ROM転送モード

FC ROM Vomitterは3種類の経路でROMを受け取れます。どの経路も同じ制御APIを
使用し、iNES検査、非アクティブFlashスロットへの保存、CRC照合、SRAM照合、
ファミコン側バス分離を省略しません。

| モード | 初期状態 | 用途 |
|---|---|---|
| SoftAPブラウザ | 有効 | スマホから`http://192.168.4.1`へアップロード |
| USB-C直接転送 | 有効 | PCからWi-Fiなしで転送 |
| HTTPSクラウド取得 | 無効 | USB給電中の自動取得 |

## USB-C直接転送

```powershell
py -m pip install pyserial
py scripts/upload_rom_usb.py COM10 path\to\game.nes
```

USB Serial/JTAGへ長さとCRC32を含むフレームを送り、カートリッジは`RVOK`または
`RVER`で応答します。破損、不完全、サイズ超過、非iNESデータはFlashへ保存する
前に拒否されます。ファーム書き込み時はアップローダーを終了してください。

## HTTPSクラウド取得

> 以下は、設定した1つのURLを取得する現在の実装です。匿名アップロードキュー、
> 端末能力ネゴシエーション、導入完了通知は、
> [展示向け匿名クラウドサービス案](expo-cloud-service-ja.md)で定義する計画中のv2です。

公開リポジトリへ認証情報を入れないため、初期状態では無効です。

```powershell
pio run -d firmware -e esp32-s3 -t menuconfig
```

**ROM Vomitter FC**でクラウド取得を有効にし、Wi-Fi SSID、パスワード、生の
`.nes`を返すHTTPS URL、必要ならBearerトークンを設定します。HTTPS証明書は
ESP-IDFの証明書バンドルで検証します。最初のTLS通信前に`pool.ntp.org`から
時刻を同期し、証明書の有効期間も正しく確認します。SoftAPは復旧用として
同時に残ります。

初期設定では、ファミコン本体から電源が来ている間はクラウド更新を保留します。
USB単独給電時に取得・保存してから本体へ挿す運用が安全です。同一ROMは再保存
しないため、定期ポーリングでFlashスロットや書換回数を無駄にしません。

SSID、パスワード、トークンはローカルの`sdkconfig.*`と書込み済みバイナリに
含まれます。Gitへ追加せず、公開バイナリにも使用しないでください。

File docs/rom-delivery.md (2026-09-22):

# ROM delivery modes

FC ROM Vomitter accepts a ROM through three independent transports. Every
transport calls the same controller API, so iNES validation, inactive-slot
commit, flash CRC verification, SRAM readback, and console isolation remain
mandatory.

| Mode | Direction | Default | Intended use |
|---|---|---|---|
| SoftAP browser | phone/PC → cartridge | Enabled | Normal local use at `http://192.168.4.1` |
| USB-C framed upload | PC → cartridge | Enabled | Fast bench transfer without Wi-Fi |
| HTTPS cloud pull | cloud → cartridge | Disabled | Unattended retrieval while USB-powered |

## USB-C direct upload

Install [pyserial](https://pyserial.readthedocs.io/) and run:

```powershell
py -m pip install pyserial
py scripts/upload_rom_usb.py COM10 path\to\game.nes
```

On Linux, the port normally resembles `/dev/ttyACM0`. The uploader sends a
16-byte little-endian header followed by the original iNES bytes:

```text
offset  size  field
0       4     ASCII RVUP
4       1     protocol version = 1
5       1     flags = 0
6       2     header size = 16
8       4     payload length
12      4     CRC32 of the original iNES payload
```

The device replies with one line beginning `RVOK` or `RVER`. Bad magic,
unsupported versions, oversized/truncated payloads, CRC errors, and invalid
iNES files are rejected before flash commit. Close the uploader's serial port
before using PlatformIO to flash firmware.

## HTTPS cloud pull

> The implemented mode below polls one configured URL. The anonymous upload
> queue, device capability negotiation, and installation acknowledgement are a
> planned v2 described in [Planned anonymous Expo cloud service](expo-cloud-service.md).

Cloud mode is compile-time opt-in so public source never contains credentials.
Create the local ignored `firmware/sdkconfig.esp32-s3` through menuconfig:

```powershell
pio run -d firmware -e esp32-s3 -t menuconfig
```

Under **ROM Vomitter FC**, enable **HTTPS cloud ROM polling** and set:

- station Wi-Fi SSID and password;
- an HTTPS URL returning the raw `.nes` bytes with HTTP status 200;
- an optional bearer token;
- polling interval and request timeout.

The ESP-IDF certificate bundle validates HTTPS. After joining the station,
the cartridge obtains trusted time from `pool.ntp.org` before its first TLS
request so certificate validity dates are checked correctly. Plain HTTP is
rejected unless the explicitly unsafe development switch is enabled. The
original SoftAP remains active in AP+station mode as a recovery path.

By default, a cloud image is installed only while console power is absent.
This allows a USB-powered cartridge to update without freezing a running
Famicom. Enabling live-console reload is an explicit opt-in. A normalized
image identical to the active image is ignored, so polling does not consume
flash-slot sequence numbers or cause repeated SRAM reloads.

Credentials and bearer tokens are compiled into the local firmware image.
Do not commit `sdkconfig.*`, share the resulting binary publicly, or use a
high-value long-lived token. Prefer a narrowly scoped, revocable read token.

## Status

`GET /api/status` reports `usb_upload`, `cloud_pull`, and `cloud_status` in
addition to the existing image and console fields.

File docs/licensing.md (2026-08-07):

# Licensing and attribution

This repository is intentionally dual-licensed.

## MIT

The root [MIT license](../LICENSE) applies to:

- `firmware/`;
- firmware and general README material under `experimental/mapper3-esp32/`;
- `scripts/`;
- Python/PowerShell source under `hardware/tools/`, except where a file states otherwise;
- README files and original general documentation under `docs/`, except designated hardware-derived images and manufacturing views.

## CC BY-SA 4.0

[CC BY-SA 4.0](../LICENSES/CC-BY-SA-4.0.txt) applies to:

- KiCad design and library files under `hardware/`;
- hardware-specific documentation under `hardware/docs/`;
- `manufacturing/` artifacts;
- experimental KiCad hardware and hardware-derived evidence under `experimental/nes/`;
- `experimental/mapper3-esp32/HARDWARE-PATCH.md`, as hardware-specific
  modification documentation;
- PCB renders and hardware artwork under `docs/images/` and `hardware/assets/`.

Attribution: **Keitark, FC ROM Vomitter / nescart-fc Rev A-FC**,
<https://github.com/Keitark/fc-rom-vomitter>.

## Third-party material and references

- Famicom connector behavior and pinout research: [NESdev Wiki cartridge connector](https://www.nesdev.org/wiki/Cartridge_connector).
- Mechanical dimension research: [NESdev Famicom cartridge dimensions](https://www.nesdev.org/wiki/Famicom_cartridge_dimensions) and [Gumball2415/NES-Famicom-Cartridge-Dimensions](https://github.com/Gumball2415/NES-Famicom-Cartridge-Dimensions). The FC outline was reconstructed from published dimensions rather than copied from an upstream KiCad file.
- `hardware/nescart-fc.3dshapes/SSOP-32_11.305x20.495mm_P1.27mm.step`: KiCad Packages3D 8.0.5, copyright 2018 KiCad StepUp, CC BY-SA 4.0 with the KiCad library exception. See the adjacent README and STEP header.
- The experimental NES cartridge edge footprint and board geometry derive from [emeargt/nes-cnrom](https://github.com/emeargt/nes-cnrom), licensed CC BY-SA 4.0.
- The ROM Vomitter mascot is original generated artwork; its source prompt is preserved next to the asset.

Facts such as connector pin assignments are cited for traceability. References
do not imply endorsement by NESdev, KiCad, Nintendo or other contributors.

Famicom and Nintendo are trademarks of Nintendo. This project is not affiliated
with or endorsed by Nintendo.

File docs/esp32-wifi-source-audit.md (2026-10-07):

# ESP32 Wi-Fi source and virtual checks

Checked on 2026-10-08 for NES-SDR issue 1.

## Reproduced error and correction

The RF startup service shuts down setup HTTP and the AP before allocating the
RF task. In the previous code, errors inside that task at Wi-Fi start,
power-save setup, promiscuous enable or channel setup deleted the task and
left setup offline. The error state also allowed a new RF start immediately.

Native fault injection reproduced all four cases against the production
`nes_sdr_platform.c`. The correction queues recovery through the resident
service after the failed RF task exits. Recovery disables promiscuous mode,
restarts the setup AP and HTTP, and rejects another start while pending.
The resident task yields 500 ms to give the idle task an opportunity to reclaim
the deleted 8 KiB RF stack before allocating setup resources.

A fatal console/image gate failure after capture has begun requires reset.
That path rejects another start and does not attempt AP recovery: capture may
have changed raw PHY registers whose restoration has not been validated.

## Initial AP source review

- AP configuration is zero-initialized, explicitly configured as WPA2, and
  applied before Wi-Fi starts. Local ESP-IDF 5.5 documentation says WPA2
  selects CCMP; the initially zero pairwise-cipher field is not a demonstrated
  cipher error. PMF is not required by the current configuration.
- Embedded RF availability checks have no radio side effects. The standalone
  ESP-SDR entry point is excluded, and RF hardware preparation is reached
  through capture only after SDR startup.
- Receive diagnostics forward the original buffer, length, ownership token
  and result. DHCP hooks consume no packets and add no reply options.
- The SDK AP client list reports associated stations. It contains no
  authorization/key-completion flag, so one client does not prove completion
  of the WPA handshake. Two observed EAPOL frames do not identify its completed
  stage either.

The earlier idle-AP failure with zero netif/IP/DHCP arrivals remains unresolved.
The startup correction addresses the separately reproduced error path.
Actual authentication-completion and key-install results are useful next
ESP32 observations; credentials and station identifiers need not be logged.

## Local validation

```text
cmake -S firmware/host_tests -B build/host-tests
cmake --build build/host-tests --config Release
ctest --test-dir build/host-tests -C Release --output-on-failure
```

The first source check passed all 11 native tests, including four startup API faults, deferred recovery,
retry gating, and a fatal post-capture gate. Existing tests also cover AP
protocol setup, receive forwarding and errors, chained/malformed DHCP packet
observation, serial status and ROM transport/storage logic.

These tests run the application C source with SDK/task substitutes. They do
not emulate the Wi-Fi PHY, closed radio driver, WPA handshake or over-air
packet delivery. No hardware test or firmware flash is part of this check.

## Normal AP operation before SDR

The normal HTTP path had additional responsiveness defects. ESP-IDF runs
ordinary URI handlers on one server task. The old upload reader retried three
five-second socket timeouts, occupying that task for about 15 seconds before
rollback and response. Browser status requests aborted after four seconds,
so a page could report interruption while Wi-Fi stayed associated.

Failed or rejected uploads returned `ESP_OK` after sending their error page.
The SDK then drained the unread body on the same server task, adding another
receive wait for a stopped sender. Positive reads also reset the timeout
counter, allowing a slow upload to occupy the worker for a long time.

The normal AP correction:

- receives uploads with a shared 30-second deadline across header, trainer,
  PRG and CHR reads, checked before and after each socket receive;
- uses a one-second receive timeout and rejects three consecutive timeouts;
- sends upload errors with `Connection: close` through the SDK error helper,
  then returns failure so the session closes without draining unread data;
- limits HTTP sessions to three with LRU purging, and bounds socket sends to
  two seconds;
- pauses browser status polls during actions, prevents duplicate button
  requests, and handles POST failures/timeouts instead of leaving them uncaught;
- bounds upload POSTs to 45 seconds and demo/SDR POSTs to 15 seconds, while
  preserving accepted SDR's intentional AP shutdown.

The 30-second limit covers body reception. Controller serialization, rollback,
flash commit and SRAM verification can add time. Successful uploads still use
the single HTTP task; concurrent pages can wait while installation completes.
Shorter socket timeouts are a client compatibility tradeoff that needs later
hardware qualification. Closing an unread request can cause a client network
error instead of delivery of its error body; the browser handles both outcomes.

Last recorded combined-firmware measurements on 2026-10-04 were 13,532 bytes
free internal heap and a 7,680-byte largest block with one client. The RF ring
reserves 192 KiB at boot, before SDR starts. The ROM image, HTTP/USB stacks and
Wi-Fi allocations consume the remaining memory. Streaming uploads reuse the
image buffer, and the audit found no application leak in ordinary page/status
GETs. The session cap mitigates traffic pressure; it does not establish the
cause of the earlier zero-RX failure, which also occurred in an ample-heap
comparison build.

Twelve additional native upload cases cover valid 16/32 KiB/trainer images,
malformed/oversized requests, disconnects, timeout recovery, controller errors,
and deadline expiry despite positive progress. Eight cases failed against the
old handler; all pass after correction. The complete native suite has 23 tests.
Seven Node VM tests exercise the actual embedded JavaScript with substituted
browser APIs:

```text
node --test firmware/host_tests/test_web_actions.js
```

These checks establish application behavior under simulated reads, time and
browser events. They do not establish AP association, DHCP delivery, physical
radio stability, or the timing of real flash/SRAM work.

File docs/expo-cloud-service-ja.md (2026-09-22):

# 展示向け匿名クラウドサービス案

> **状態:** Cloudflareサービスとプロトコル互換テストは
> [`service/`](../service/) に実装済みです。現在のカートリッジファームウェアに
> 実装済みなのは、ビルド時に指定した1つのHTTPS URLからの取得です。ここで説明する
> キュー、端末ネゴシエーション、完了通知はファームウェア側にはまだ実装されていません。

このv2サービスでは、来場者がChatGPTアカウントなしで公開Webページから対応
homebrew ROMを送信できます。サービス側で検査してキューへ登録し、カートリッジが
対応可能なジョブを取得します。HTTPSでダウンロード後、内容を再検査し、安全な
ハードウェア状態でのみ導入して、結果をサーバーへ返します。

最初の公開版は、展示会場で1台のカートリッジをスタッフが監督して使うためのもの
です。無制限なROM配布サービスではありません。送信者が利用権を持つROMだけを
対象にします。

## 役割と信頼境界

| 役割 | 責務 | 禁止事項 |
|---|---|---|
| 匿名の来場者 | ROMを1件送信し、発行された状態確認URLを保持 | カートリッジへの直接アクセス、検査の迂回 |
| 公開Webサービス | 検査、重複排除、キュー、期限切れ、状態表示 | 非公開オブジェクトURLや端末秘密鍵の公開 |
| カートリッジ | 能力通知、互換ジョブ取得、再検査、安全な導入、結果通知 | ブラウザ由来メタデータの信用、危険なバス状態での導入 |
| 運営者 | キュー停止・消去、デモの緊急停止 | 通常の自動運転中に有効なROMを1件ずつ手承認 |

来場者はChatGPTへサインインしませんが、無制限でもありません。サービスはランダムな
HttpOnlyセッションCookieと推測困難な状態確認トークンを発行します。端末APIは別の
端末固有秘密鍵によるHMAC認証を使います。

## 来場者フロー

1. 公開Siteを開き、`.nes`をアップロードする。
2. サーバーがiNESヘッダーと全ペイロードを検査する。
3. 有効で対応可能なイメージだけを自動承認してFIFOキューへ入れる。
4. 推測困難な状態確認URLを返し、ページから進行状況を確認する。
5. `queued`、`claimed`、`downloaded`、`installed`、または終端状態の
   `rejected`、`failed`、`expired`、`duplicate`へ遷移する。

この来場者フローにChatGPTログインは不要です。運営者操作とデプロイ管理は別途認証
します。

### HTTP API

| methodとpath | 呼出元 | 結果 |
|---|---|---|
| `POST /api/public/jobs` | 来場者browser | uploadを検査し、状態token付き`202`、または範囲を限定した`4xx`拒否を返す |
| `GET /api/public/jobs/{status_token}` | 来場者browser | ROMや端末identityを出さずに公開可能なjob状態を返す |
| `POST /api/device/v2/next` | 認証済みcart | 能力/状態を通知し、`204`またはlease付きmanifest 1件を受け取る |
| `GET /api/device/v2/jobs/{job_id}/rom` | 認証済みcart | 有効なleaseを持つ端末だけにROM byte列を返す |
| `POST /api/device/v2/jobs/{job_id}/result` | 認証済みcart | `installed`、`unchanged`、`deferred`、`failed`を冪等に通知する |
| `GET /api/operator/status` | 認証済み運営者 | queue件数、停止状態、最後の端末状態を確認する |
| `POST /api/operator/pause` | 認証済み運営者 | 端末によるclaimを停止または再開する |
| `POST /api/operator/clear-next` | 認証済み運営者 | 最古の待機jobを取消し、payloadを削除する |
| `POST /api/operator/clear-all` | 認証済み運営者 | 待機jobを1 requestの上限内ですべて取消・削除する |

公開用status tokenと内部job IDは別の値にします。状態確認URLが漏れても、ROM取得、
取消、端末操作を認可してはいけません。

## 自動承認ゲート

自動承認とは、任意のデータを無条件で受け入れることではなく、**自動検査に合格した
ものだけを受け入れる**ことです。非公開オブジェクトストレージへ保存する前に、以下を
確認します。

- アップロード上限と完全なiNESヘッダー
- カートリッジの能力プロファイルに合うmapperとPRG/CHR構成
- 明示対応するまでtrainerやNES 2.0固有機能を拒否
- ブラウザ値を信用せず、サーバー側でSHA-256とCRC32を計算
- 待機中・実行中イメージとの重複排除
- セッション/IP単位のクールダウンと有限キュー（初期値20件）
- 完了または期限切れ後の自動削除（初期値1時間）

拒否されたデータには、非公開オブジェクトのダウンロードURLを発行しません。

## 端末ネゴシエーション

展示プロファイルでは2〜3秒ごとにポーリングします。互換性と安全な導入に必要な状態を
毎回通知します。

```json
{
  "device_id": "demo-cart-01",
  "firmware": "2.0.0-dev",
  "protocol": 2,
  "mappers": [0],
  "max_rom_bytes": 41488,
  "active_sha256": "...",
  "console_power": false,
  "console_exposed": false
}
```

互換ジョブがなければ`204 No Content`、あれば短時間だけ有効なmanifestを返します。

```json
{
  "job_id": "01J...",
  "download_url": "https://.../short-lived-object-url",
  "bytes": 40976,
  "sha256": "...",
  "crc32": "d98313b2",
    "ines": { "mapper": 0, "prg_kib": 32, "chr_kib": 8 },
  "expires_at": "2026-09-22T12:34:56Z"
}
```

端末はTLS、バイト数、SHA-256、CRC32、再解析したiNES項目を検査します。その後、既存の
非アクティブFlashスロット、Flash CRC、SRAM読戻し、ファミコン側バス分離の各ゲートを
通します。導入が危険な状態でもダウンロードまでは可能ですが、結果は`deferred`として、
安全になるまで本体側へ公開しません。

処理後は、次のいずれかを冪等に通知します。

- `installed`: 検査を完了して有効化
- `unchanged`: 同じハッシュがすでに有効
- `deferred`: 有効だが安全な本体電源状態を待機中
- `failed`: 端末側で拒否。有限の機械可読エラーコードを添付

リセットや応答消失で二重導入やジョブの永久停止が起きないよう、claimとackにはleaseと
冪等キーを使います。

## Cloudflareステージングの保存構成

ステージング版ではCloudflare Worker、メタデータとキュー状態にD1、ROM本体に非公開
R2を使います。API自体はhosting非依存です。端末control planeを移さずに、来場者UIだけを
後からChatGPT Sitesで見せることもできます。

| 保存先 | 内容 |
|---|---|
| D1 | セッション、ジョブ、ハッシュ、検査結果、lease、端末状態、ack、期限 |
| R2非公開bucket | ジョブID/ハッシュをキーにした検査済みROM |

公開ブラウザへ永続的なR2認証情報を渡しません。認証済みclaim後のカートリッジにだけ、
短時間のダウンロードURLを渡します。

## 運用保護

- スタッフ専用のpause/resume、次件削除、全件削除、緊急停止
- 最終端末poll、ファーム/能力、有効hash、queue数、最終error、導入保留状態の表示
- 厳格なbody上限、rate limit、origin検査、構造化監査イベント
- account、payment、Wi-Fi、端末秘密鍵をlogへ保存しない
- クラウドや会場ネットワーク障害時もSoftAPブラウザをローカル復旧経路として残す

ローカル検証とステージングdeploy手順は
[`service/README.md`](../service/README.md)を参照してください。

## 実装完了の判定

次を満たすまでv2デモを完成扱いにしません。

1. 不正、過大、未対応、重複、rate limit対象uploadのnegative testがある
2. 端末HMAC、期限、replay、lease回復、冪等ackのtestが通る
3. 本体給電中または危険なbus ownershipでは導入を保留する
4. browser再読込後もqueue状態が残り、最終端末結果まで表示できる
5. 非公開ROMを匿名で列挙・取得できない
6. 実機で運営者pauseと緊急停止を試験する
7. 固定URLのv1モードとSoftAP復旧経路が引き続き使える

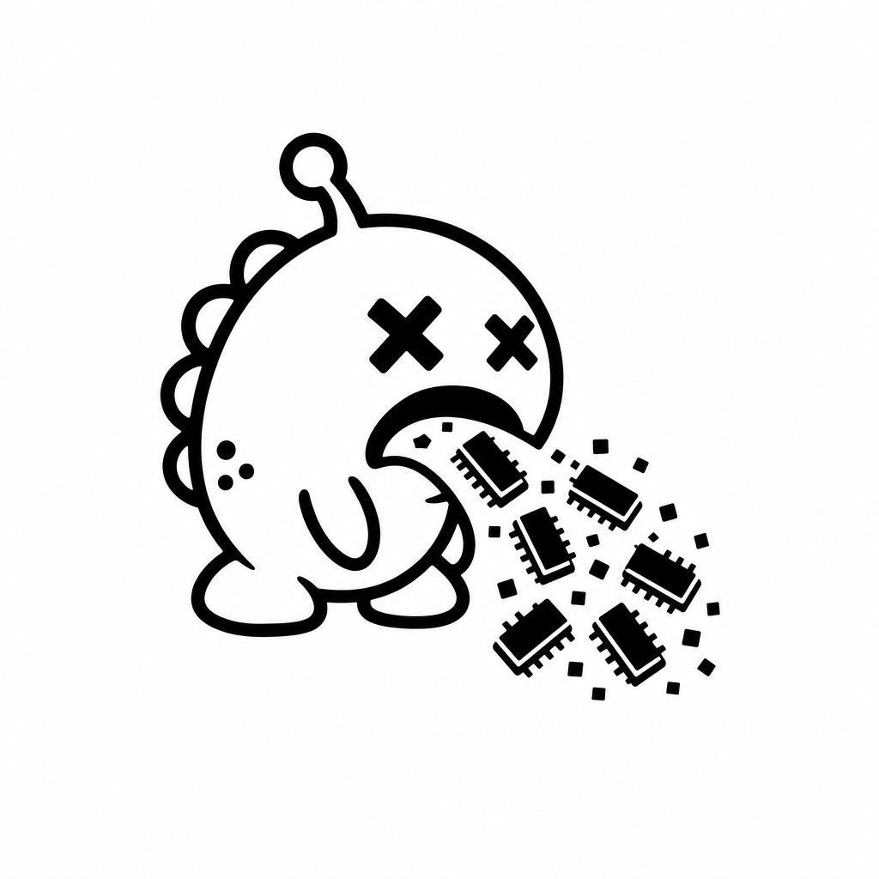
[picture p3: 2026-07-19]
hardware/assets/rom-vomitter-mascot.png

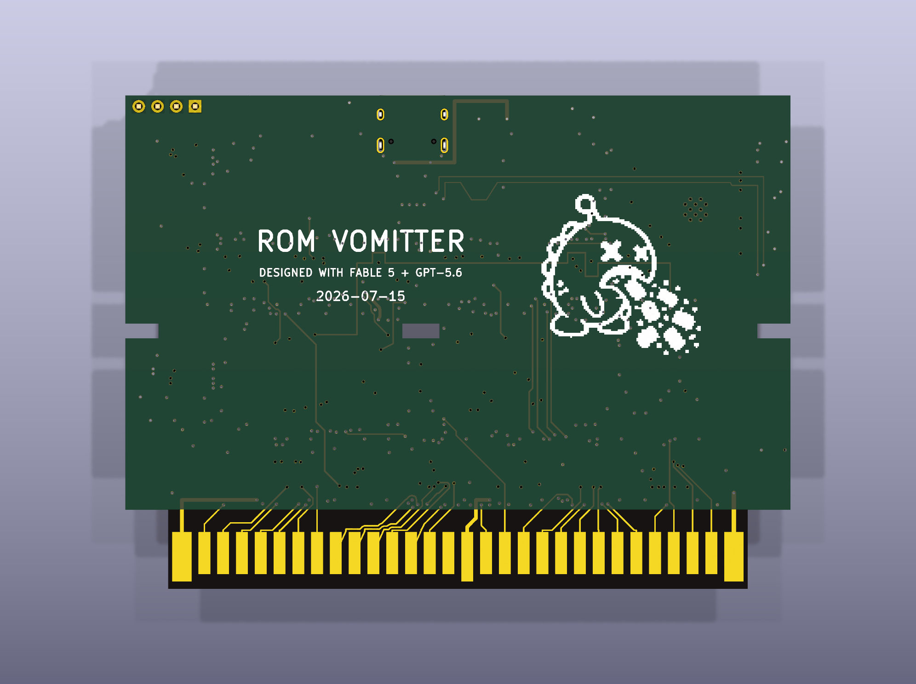
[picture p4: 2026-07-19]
docs/images/board-bottom.png

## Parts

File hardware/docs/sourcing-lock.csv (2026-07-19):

Comment | Designator | Footprint | LCSC Part # | Status | Evidence
0603B105K250CT | C1 | Capacitor_SMD:C_0603_1608Metric | C388002 | RECHECK_AT_QUOTE | Inherited exact match from NES release 2026-07-12
CC0603KRX7R9BB104 | C2,C3,C4,C5,C6,C7,C8,C9,C10,C11,C12,C13,C14,C15,C16,C17,C18,C19,C20,C21,C22,C23,C24 | Capacitor_SMD:C_0603_1608Metric | C14663 | RECHECK_AT_QUOTE | Inherited exact match from NES release 2026-07-12
CL21A106KAYNNNE | C26,C27,C28,C29,C30 | Capacitor_SMD:C_0805_2012Metric | C15850 | RECHECK_AT_QUOTE | Inherited exact match from NES release 2026-07-12
CL21A226MAQNNNE | C31 | Capacitor_SMD:C_0805_2012Metric | C45783 | RECHECK_AT_QUOTE | Inherited exact match from NES release 2026-07-12
SS34 | D1,D2 | Diode_SMD:D_SMA | C8678 | RECHECK_AT_QUOTE | Inherited exact match from NES release 2026-07-12
TYPE-C-31-M-12 | J2 | Connector_USB:USB_C_Receptacle_HRO_TYPE-C-31-M-12 | C165948 | RECHECK_AT_QUOTE | Inherited exact match from NES release 2026-07-12
NCD0603B4 | LED1 | LED_SMD:LED_0603_1608Metric | C89814 | RECHECK_AT_QUOTE | Inherited exact match from NES release 2026-07-12
NCD0603G2 | LED2 | LED_SMD:LED_0603_1608Metric | C87326 | RECHECK_AT_QUOTE | Inherited exact match from NES release 2026-07-12
RCT0310KFLF | R1,R2,R9,R10,R11,R12,R13,R14,R15,R16,R17 | Resistor_SMD:R_0603_1608Metric | C177644 | RECHECK_AT_QUOTE | Inherited exact match from NES release 2026-07-12
RMC06035.1K1%N | R3,R4 | Resistor_SMD:R_0603_1608Metric | C269716 | RECHECK_AT_QUOTE | Inherited exact match from NES release 2026-07-12
0603WAF1003T5E | R5,R6 | Resistor_SMD:R_0603_1608Metric | C25803 | RECHECK_AT_QUOTE | Inherited exact match from NES release 2026-07-12
0603WAF1001T5E | R18,R19 | Resistor_SMD:R_0603_1608Metric | C21190 | RECHECK_AT_QUOTE | Inherited exact match from NES release 2026-07-12
CR-03JL7----0R | R20 | Resistor_SMD:R_0603_1608Metric | C217278 | RECHECK_AT_QUOTE | LCSC official listing checked 2026-07-15; 0603 0 ohm 100 mW
B3U-1000P | SW1,SW2 | Button_Switch_SMD:SW_SPST_B3U-1000P | C231329 | RECHECK_AT_QUOTE | Inherited exact match from NES release 2026-07-12
SN74LVC245APWR | U1,U2,U3,U4,U5,U6,U7,U8,U9,U10,U11,U12 | Package_SO:TSSOP-20_4.4x6.5mm_P0.65mm | C7848 | DESIGN_CRITICAL | Inherited exact match from NES release 2026-07-12
CY62128EV30LL-45SXIT | U13,U14 | Package_SO:SOP-32_11.305x20.495mm_P1.27mm | C2840304 | DESIGN_CRITICAL | Exact SRAM and package required
SN74HC595PWR | U15,U16 | Package_SO:TSSOP-16_4.4x5mm_P0.65mm | C273642 | RECHECK_AT_QUOTE | Inherited exact match from NES release 2026-07-12
SN74LVC157APWR | U17 | Package_SO:TSSOP-16_4.4x5mm_P0.65mm | C406871 | RECHECK_AT_QUOTE | Inherited exact match from NES release 2026-07-12
SN74LVC1G04DCKR | U18,U19,U20 | Package_TO_SOT_SMD:SOT-353_SC-70-5 | C2983744 | RECHECK_AT_QUOTE | Inherited exact match from NES release 2026-07-12
SN74LVC1G10DCKR | U21,U22 | Package_TO_SOT_SMD:SOT-363_SC-70-6 | C485078 | RECHECK_AT_QUOTE | Inherited exact match from NES release 2026-07-12
ESP32-S3-WROOM-1-N8 | U23 | RF_Module:ESP32-S3-WROOM-1 | C2913198 | DESIGN_CRITICAL | Exact module flash size and package required
AMS1117-3.3 | U25 | Package_TO_SOT_SMD:SOT-223-3_TabPin2 | C6186 | RECHECK_AT_QUOTE | Inherited exact match from NES release 2026-07-12

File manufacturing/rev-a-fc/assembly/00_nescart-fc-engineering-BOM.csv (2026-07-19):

Reference | Value | Footprint | MPN | LCSC | Quantity | DNP
C1 | 1u | Capacitor_SMD:C_0603_1608Metric | 1u X7R |  | 1
C2-C24 | 100n | Capacitor_SMD:C_0603_1608Metric | 100n X7R |  | 23
C26-C30 | 10u | Capacitor_SMD:C_0805_2012Metric | 10u X7R |  | 5
C31 | 22u | Capacitor_SMD:C_0805_2012Metric | 22u X7R |  | 1
D1,D2 | SS34 | Diode_SMD:D_SMA | SS34 |  | 2
J1 | Famicom_Cart_Edge | nescart-fc:cartridge_edge_60 |  |  | 1
J2 | USB-C_16P | Connector_USB:USB_C_Receptacle_HRO_TYPE-C-31-M-12 | HRO TYPE-C-31-M-12 |  | 1
J3 | DBG_UART | Connector_PinHeader_2.54mm:PinHeader_1x04_P2.54mm_Vertical | PinHeader 1x4 |  | 1
LED1 | STATUS_BLUE | LED_SMD:LED_0603_1608Metric | 0603 LED |  | 1
LED2 | PWR_GREEN | LED_SMD:LED_0603_1608Metric | 0603 LED |  | 1
R1,R2,R9-R17 | 10k | Resistor_SMD:R_0603_1608Metric | 0603 10k 1% |  | 11
R3,R4 | 5.1k | Resistor_SMD:R_0603_1608Metric | 0603 5.1k 1% |  | 2
R5,R6 | 100k | Resistor_SMD:R_0603_1608Metric | 0603 100k 1% |  | 2
R18,R19 | 1k | Resistor_SMD:R_0603_1608Metric | 0603 1k 1% |  | 2
R20 | 0R | Resistor_SMD:R_0603_1608Metric | 0603 0R 1% |  | 1
SW1 | ESP RST | Button_Switch_SMD:SW_SPST_B3U-1000P | B3U-1000P |  | 1
SW2 | BOOT | Button_Switch_SMD:SW_SPST_B3U-1000P | B3U-1000P |  | 1
TP1 | IO36 | TestPoint:TestPoint_Pad_D1.0mm |  |  | 1
U1-U12 | SN74LVC245APW | Package_SO:TSSOP-20_4.4x6.5mm_P0.65mm | SN74LVC245APWR |  | 12
U13,U14 | CY62128EV30 | Package_SO:SOP-32_11.305x20.495mm_P1.27mm | CY62128EV30LL-45SXIT | C2840304 | 2
U15,U16 | 74HC595PW | Package_SO:TSSOP-16_4.4x5mm_P0.65mm | SN74HC595PWR |  | 2
U17 | SN74LVC157APW | Package_SO:TSSOP-16_4.4x5mm_P0.65mm | SN74LVC157APWR |  | 1
U18-U20 | 74LVC1G04 | Package_TO_SOT_SMD:SOT-353_SC-70-5 | SN74LVC1G04DCKR |  | 3
U21,U22 | 74LVC1G10 | Package_TO_SOT_SMD:SOT-363_SC-70-6 | SN74LVC1G10DCKR |  | 2
U23 | ESP32-S3-WROOM-1-N8 | RF_Module:ESP32-S3-WROOM-1 | ESP32-S3-WROOM-1-N8 |  | 1
U25 | AMS1117-3.3 | Package_TO_SOT_SMD:SOT-223-3_TabPin2 | AMS1117-3.3 |  | 1

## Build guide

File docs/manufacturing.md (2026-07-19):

# Manufacturing release notes

## Rev A-FC configuration

- 6 copper layers;
- 1.2 mm finished thickness;
- 90.0 × 66.8 mm maximum envelope;
- green solder mask;
- 60 wear-capable gold fingers with 45-degree insertion-edge bevel;
- no paid controlled-impedance option;
- top-side PCBA;
- 0.50/0.30 mm standard through vias;
- custom frameless top stencil derived from F.Paste.

The 10 mm extension at the edge opposite the fingers is intentional and needs
a custom shell. The standard tongue, side notches, centre slot and J1 datum may
not be normalized by a fabricator.

## Release evidence

The included release records:

| Gate | Result |
|---|---:|
| ERC | 0 errors; 8 reviewed warnings |
| Raw unconnected items | 0 |
| Classified real DRC errors | 0 |
| Layout-check failures | 0 |
| Unresolved CPL registrations | 0 |
| Unwaived silk overlap / over-copper | 0 / 0 |

Two reported silk-edge findings are the intentional USB connector mouth at the
board boundary. Gold-finger mask openings produce design-specific raw DRC items
that are classified separately; they are not silently deleted.

## Files

- `gerbers-drill.zip`: uploadable fabrication package.
- `assembly/02_nescart-fc-BOM-jlcpcb.csv`: JLCPCB-format BOM.
- `assembly/03_nescart-fc-CPL-jlcpcb-calibrated.csv`: calibrated placement file.
- `assembly/04_cpl-registration-audit.csv`: per-reference registration evidence.
- `evidence/`: board statistics, ERC/DRC/layout reports, renders and manufacturing views.
- `release-manifest.json`: SHA-256 hashes for source and every public release artifact.

Vendor placement preview is still a separate gate. Import-time visual checks
must cover every fitted reference, pin 1, polarity, body centering, rotation,
mirroring and X/Y translation. A browser-only correction is diagnostic; fix the
source mapping, regenerate, re-hash and re-upload.

The public package intentionally omits account details, order numbers, payment,
coupons, addresses and browser screenshots.

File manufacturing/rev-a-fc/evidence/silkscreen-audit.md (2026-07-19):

# Silkscreen audit

Board: `hardware/nescart-fc.kicad_pcb`

| Finding | Count |
|---|---:|
| `silk_edge_clearance` | 2 |
| `silk_over_copper` | 0 |
| `silk_overlap` | 0 |

Total: **2**

## Items

1. `silk_edge_clearance` — セグメント (Edge.Cuts 上) [4d0dea12-8dc2-4678-a895-b715a727320f]; セグメント of J2 、F.Silkscreen 上 [70b659e8-2f34-4ee3-8068-cfd2c03fa010]
2. `silk_edge_clearance` — セグメント (Edge.Cuts 上) [4d0dea12-8dc2-4678-a895-b715a727320f]; セグメント of J2 、F.Silkscreen 上 [908d6914-ba53-4bea-b8a2-01d87157e942]

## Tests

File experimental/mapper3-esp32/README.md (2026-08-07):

# ESP32-S3 two-bank Mapper-3 experiment

[日本語](README_JA.md) · [Hardware patch](HARDWARE-PATCH.md) · [Validation record](validation.json)

This is a post-release experiment for the existing FC ROM Vomitter Rev A-FC
board. It observes Mapper-3 CPU writes with the onboard ESP32-S3 and drives
CHR SRAM A13, allowing two 8 KiB CHR banks without adding another MCU or a
dedicated latch.

> [!CAUTION]
> This is a bodge-wire experiment, not a revised fabrication release. Do not
> order or modify hardware from this directory without reviewing the rework,
> measuring the input levels, and accepting the risk of lifted pins.

The immutable NROM release remains in the repository root. The checked-in
`hardware/` schematic and PCB match the Rev A-FC manufacturing source; this
experiment does not edit either one.

## Compatibility boundary

| Mode | Supported by this experiment |
|---|---|
| Mapper 0 / NROM | 16 or 32 KiB PRG, one 8 KiB CHR bank |
| Mapper 3 / CNROM | 16 or 32 KiB PRG, exactly two 8 KiB CHR banks, bank selected by CPU D0 |
| CHR-RAM, four-bank CNROM, UNROM, MMC1/MMC3, expansion audio | Not supported |

Mapper-0 CHR is copied to both physical CHR regions. Mapper 3 uses GPIO36 to
select U14 A13 at runtime.

## Signal paths

| Function | ESP32-S3 | Board signal / point |
|---|---:|---|
| CHR bank output | GPIO36 | TP1 to isolated U14 pin 28 (A13) |
| Mapper data bit | GPIO42 | CPU D0 through the preferred U2 spare channel |
| Cartridge selection | GPIO43 | U19 pin 4, `ROMSEL_inv`, via J3 pin 2 |
| Read rejection | GPIO44 | U21 pin 4, `PRG_EN_n`, via J3 pin 3 |

See [HARDWARE-PATCH.md](HARDWARE-PATCH.md) before soldering. It separates the
preferred buffered path from the resistor-divider repair used after damage to
one physical U2 input lead. The divider is recorded as evidence, not presented
as the production recommendation.

## Runtime design

- ESP32-S3 core 1 runs a 240 MHz interrupt-disabled polling loop from IRAM.
- CPU D0, `ROMSEL_inv`, and `PRG_EN_n` are read together from one GPIO input
  register.
- A selected write is confirmed by a second immediate snapshot before D0 is
  written to GPIO36.
- Mapper polling starts before LOAD-to-RUN handoff and is gated during SRAM
  loading.
- Wi-Fi, lwIP, and HTTP tasks remain on core 0.
- `/api/status` reports the selected bank and accepted bank-write counters.
- `/api/mapper-trace` returns saved raw bus windows. Pressing BOOT stops the
  mapper loop and saves the trace to NVS; reset is required to resume play.

## Build and test

```powershell
cmake -S host_tests -B host_tests/build
cmake --build host_tests/build --config Release
ctest --test-dir host_tests/build -C Release --output-on-failure

pio run -e esp32-s3 -j 1
```

The single-job PlatformIO form is intentional on Windows systems where a
parallel ESP-IDF build may exhaust local resources.

The host tests cover iNES normalization, the atomic ROM slots, mapper truth
tables, short selected writes, delayed D0, read-start hazards, repeated bank
writes, and interruption by LOAD mode.

## Evidence status

As of 2026-08-07:

- host tests: **PASS**;
- ESP32-S3 / ESP-IDF 5.5 build: **PASS**;
- hot loop in `.iram0.text`, direct GPIO access, no function calls: **PASS**;
- one modified Rev A-FC board: Mapper 0 regression passed;
- one two-bank Mapper-3 homebrew target: final behavior was near the emulator
  reference after the shortened polling path;
- powered input margin, worst-case console timing, long-run Wi-Fi stress, and
  multiple-board reproducibility: **USER_REVIEW / not qualified**.

This supports continued experimentation. It does not justify relabeling the
main Rev A-FC release as Mapper-3 capable.

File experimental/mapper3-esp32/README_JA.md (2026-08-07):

# ESP32-S3による2バンクMapper 3実験

[English](README.md) · [改造配線](HARDWARE-PATCH.md) · [検証記録](validation.json)

これはFC ROM Vomitter Rev A-FC実機に対する、製造後の実験です。搭載済み
ESP32-S3でMapper 3のCPU書き込みを観測し、CHR SRAMのA13を切り替えます。
追加MCUや外付けラッチなしで、8 KiBのCHRを2バンク扱うことを狙っています。

> [!CAUTION]
> これはジャンパ線とピン浮かしを伴う実験で、改版済み製造データでは
> ありません。安定版の`hardware/`と製造リリースは変更していません。

## 対応範囲

- Mapper 0: PRG 16/32 KiB、CHR 8 KiB
- Mapper 3: PRG 16/32 KiB、CHR 8 KiB × 2、CPU D0でバンク選択
- 非対応: CHR-RAM、4バンクCNROM、UNROM、MMC1/MMC3、拡張音源

GPIO36がU14のA13を駆動し、GPIO42/43/44でCPU D0、`ROMSEL_inv`、
`PRG_EN_n`を観測します。具体的な半田付け箇所と安全確認は
[HARDWARE-PATCH.md](HARDWARE-PATCH.md)を参照してください。

## 現在の評価

2026-08-07時点で、ホストテスト、ESP32-S3ビルド、IRAM上の直接GPIO処理は
PASSです。改造した1枚ではMapper 0の退行がなく、2バンクMapper 3の
自作ROMも最終版ではエミュレータに近い挙動になりました。

ただし、入力電圧余裕、最悪条件のタイミング、長時間Wi-Fi負荷、複数基板での
再現性は未認定です。したがって状態は**限定的な実機実験 / USER_REVIEW**で、
Rev A-FC安定版が正式にMapper 3対応になったわけではありません。

## ビルド

```powershell
cmake -S host_tests -B host_tests/build
cmake --build host_tests/build --config Release
ctest --test-dir host_tests/build -C Release --output-on-failure
pio run -e esp32-s3 -j 1
```

`/api/status`でバンクと書き込み回数を確認できます。BOOTボタンで観測記録を
NVSへ保存し、再起動後に`/api/mapper-trace`から取得できます。

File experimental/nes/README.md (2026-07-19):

# Experimental 72-pin NES-001 variant

[日本語](#日本語) · [Schematic PDF](docs/nescart-schematic.pdf)

This directory preserves the earlier front-loader NES-001 design as an experimental snapshot. It is included to make the architectural differences and design history reviewable; it is **not part of the Rev A-FC manufacturing release**.

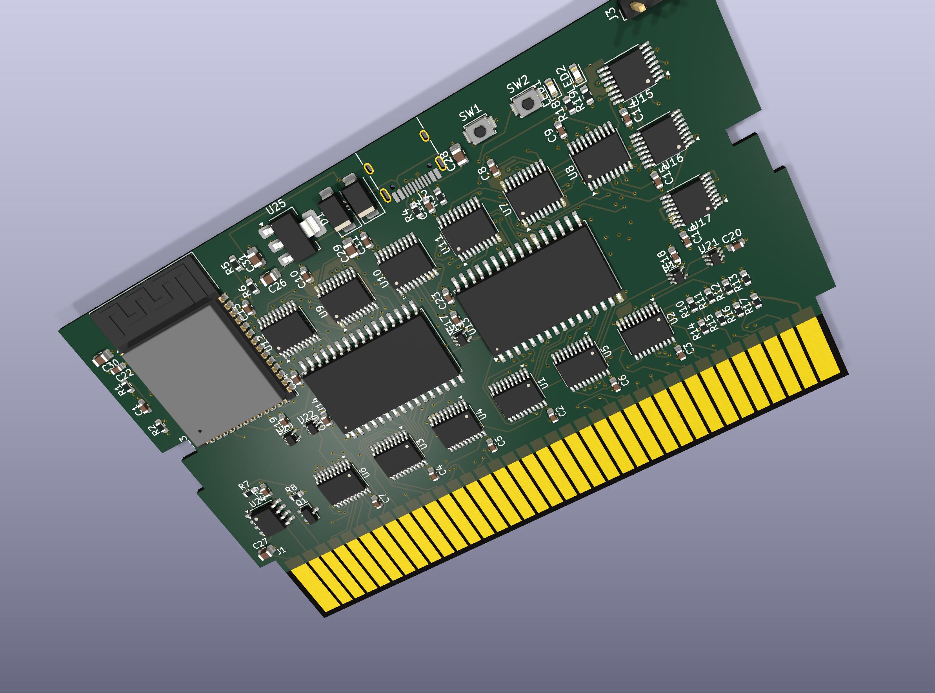
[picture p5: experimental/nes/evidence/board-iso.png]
Actual KiCad 3D render of the experimental NES board


## Why it differs from the Famicom board

The NES-001 contains a CIC lockout circuit. An ATtiny13A running a CIC-clone firmware keeps the console in reset while the ESP32-S3 owns the cartridge SRAM bus, then permits boot only after the ROM image has been copied and verified.

```mermaid
flowchart LR
    phone["Phone / laptop"] -->|"Wi-Fi upload"| esp["ESP32-S3"]
    esp -->|"load + verify"| sram["PRG + CHR SRAM"]
    cic["ATtiny13A CIC clone"] -->|"hold console reset"| nes["NES-001"]
    esp -->|"LOAD / RUN"| buffers["Bus isolation"]
    sram --> buffers --> edge["72-pin edge"] --> nes
```

## Frozen snapshot status

| Item | Recorded state |
|---|---|
| Target | Front-loader NES-001, 72-pin, NROM |
| PCB | 6 layers, 1.2 mm, CY62128 SRAM variant |
| ERC | 0 errors, 8 reviewed warnings |
| Raw disconnects | 0 |
| Classified DRC | 0 real errors |
| Layout policy | 0 failures |
| Assembly placement | **Incomplete** — browser-only placement edits existed and a clean regenerated CPL review was still required |
| Bench validation | **Not completed** |

The snapshot also records accepted prototype USB risks: 2.63 mm D+/D− length skew, one-via asymmetry, and no connector-side ESD device. Re-audit those choices before deriving hardware from this version.

The exact source hashes are recorded in [`evidence/snapshot.json`](evidence/snapshot.json). No Gerber/BOM/CPL manufacturing bundle is published for this experimental variant.

## License and attribution

The KiCad source, renders, and evidence in this directory are CC BY-SA 4.0. The cartridge edge footprint and board geometry derive from [emeargt/nes-cnrom](https://github.com/emeargt/nes-cnrom). See the repository [licensing details](../../docs/licensing.md).

## 日本語

ここにはフロントローダーNES-001用72ピン版の設計スナップショットを、実験資料として保存しています。ATtiny13AのCICクローンで本体をリセット状態に保ち、その間にESP32-S3がSRAMへROMを書き込む構成です。

回路図・未接続・分類済みDRC・レイアウト検査は記録上PASSですが、JLCPCB上の部品位置確認でブラウザ内だけの補正が残っており、元CPLへ反映して再生成・再アップロードする最終ゲートが未完了でした。実機検証も未完了です。このため、FC版とは分離し、**そのまま製造するためのリリースではありません**。

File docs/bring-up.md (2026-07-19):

# First-board bring-up

> Do not insert an untested board into a Famicom.

## Equipment

- current-limited USB supply or bench supply;
- multimeter;
- oscilloscope or logic analyzer;
- thermal camera or contact thermometer if available;
- inexpensive mapper-0 homebrew test ROM whose rights permit use.

## Bench sequence

1. Inspect the assembled board under magnification for bridges, reversed parts, connector damage and debris.
2. Check resistance from 5 V and 3.3 V to GND before applying power.
3. Power from USB with a conservative current limit and no console attached.
4. Confirm 5 V/3.3 V rails, idle current and regulator temperature.
5. Flash the firmware through native USB. If automatic download mode fails, hold **BOOT**, tap **ESP RST**, release **BOOT**, and retry.
6. Confirm LED patterns and the Wi-Fi upload page at `http://192.168.4.1`.
7. Probe `LOAD_MODE`, MCU buffer enables, console buffer enables, `/WE` and `/OE`. Prove that both bus owners are never active together.
8. Run walking-bit and address tests on both SRAMs, followed by byte-for-byte image readback.
9. Interrupt an upload and confirm that the previous committed flash slot still boots.
10. Verify USB power cannot appear on the console 5 V fingers.
11. Measure current transients and regulator temperature during Wi-Fi upload and SRAM load.

## First console test

Only after the bench sequence passes:

1. Power everything off.
2. Insert the board using a mechanically checked custom shell/support.
3. Power the Famicom.
4. Wait for solid blue READY.
5. Press the **console's red RESET button**.
6. Check video, controls, audio continuity through R20, mirroring and repeatable cold boots.

Record board revision, firmware commit, supply voltage/current, temperatures,
waveforms and the ROM hash. A single successful game boot is not full validation.

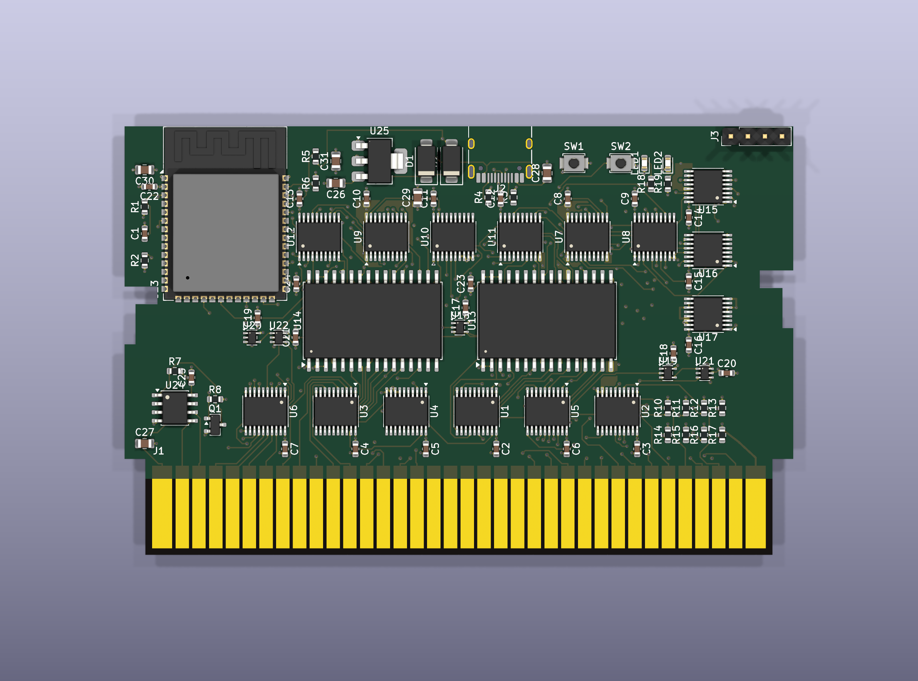
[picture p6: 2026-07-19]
experimental/nes/evidence/board-top.png

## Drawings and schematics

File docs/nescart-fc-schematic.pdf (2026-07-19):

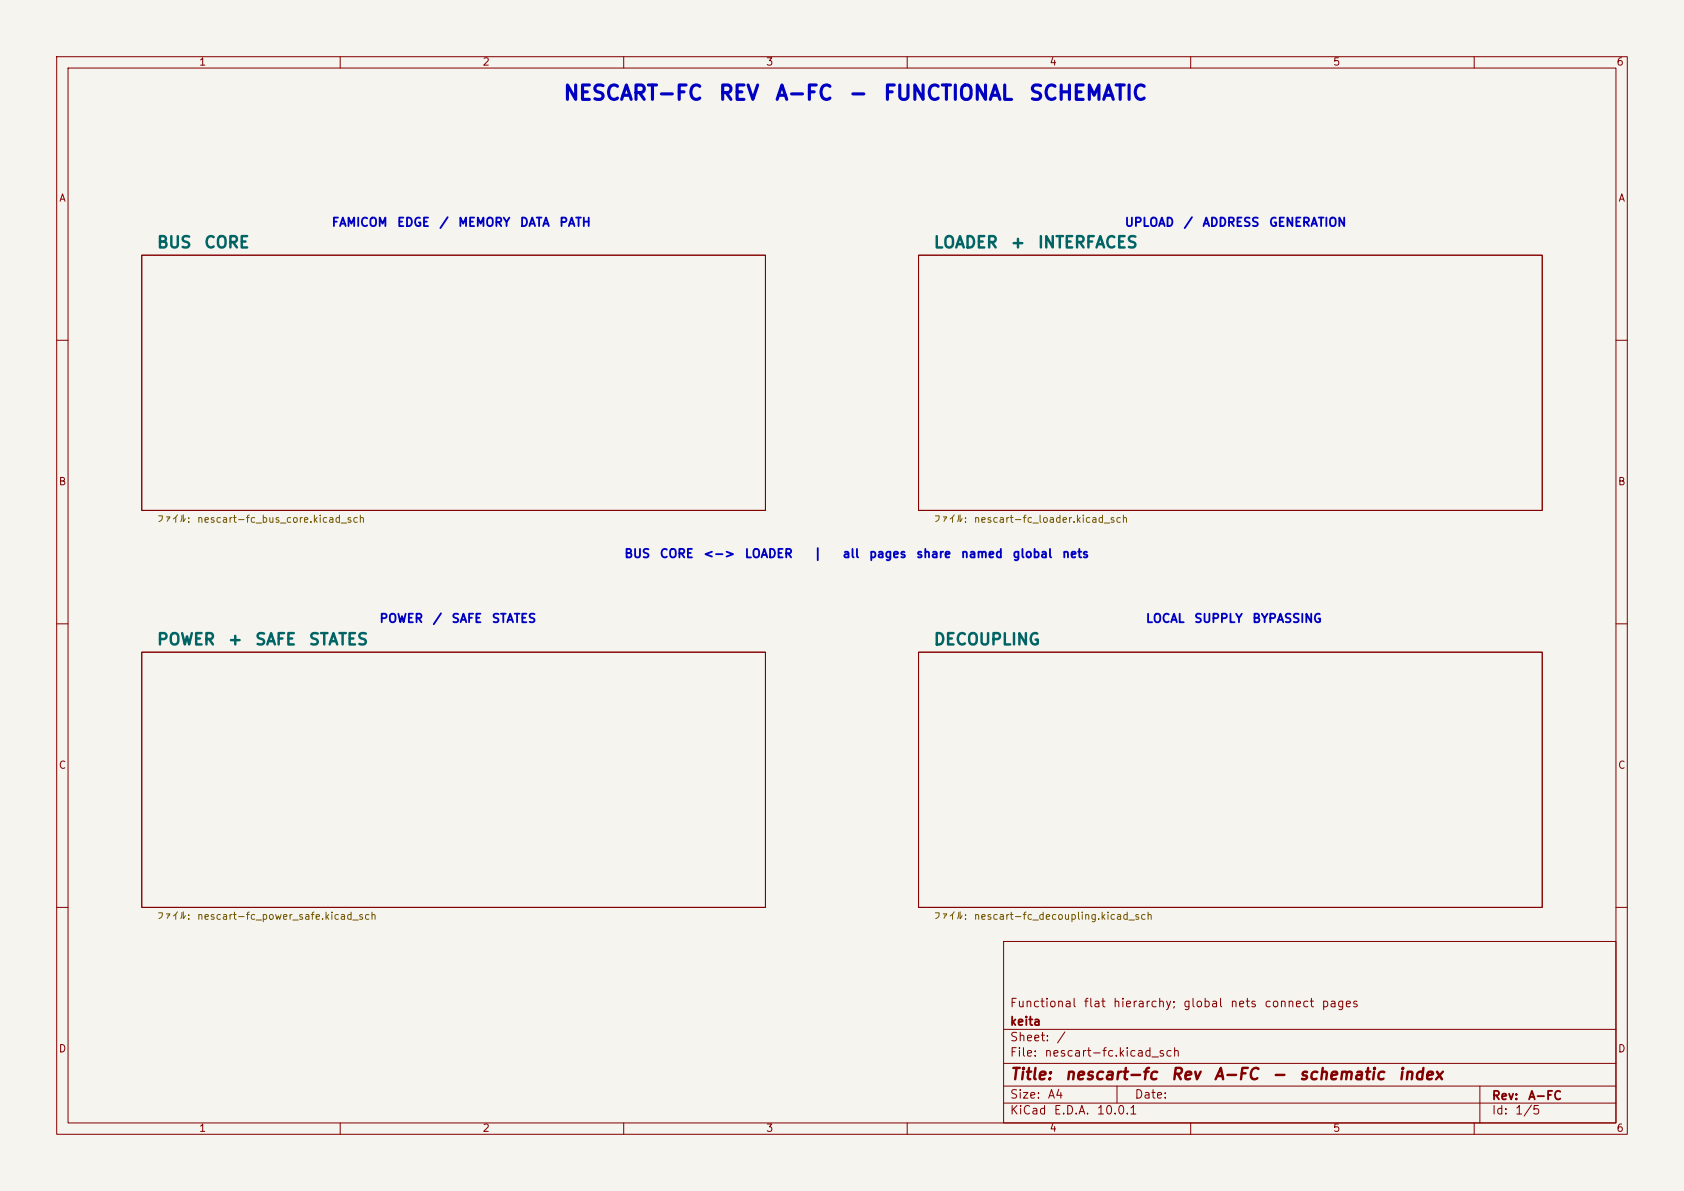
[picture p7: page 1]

NESCART-FC REV A-FC - FUNCTIONAL SCHEMATIC

FAMICOM EDGE / MEMORY DATA PATH

ファイル: nescart-fc_bus_core.kicad_sch POWER + SAFE STATES

Functional flat hierarchy; global nets connect pages
keita
Sheet: /
File: nescart-fc.kicad_sch
Title: nescart-fc Rev A-FC - schematic index

Size: A4 | Rev: A-FC
KiCad E.D.A. 10.0.1 | Id: 1/5

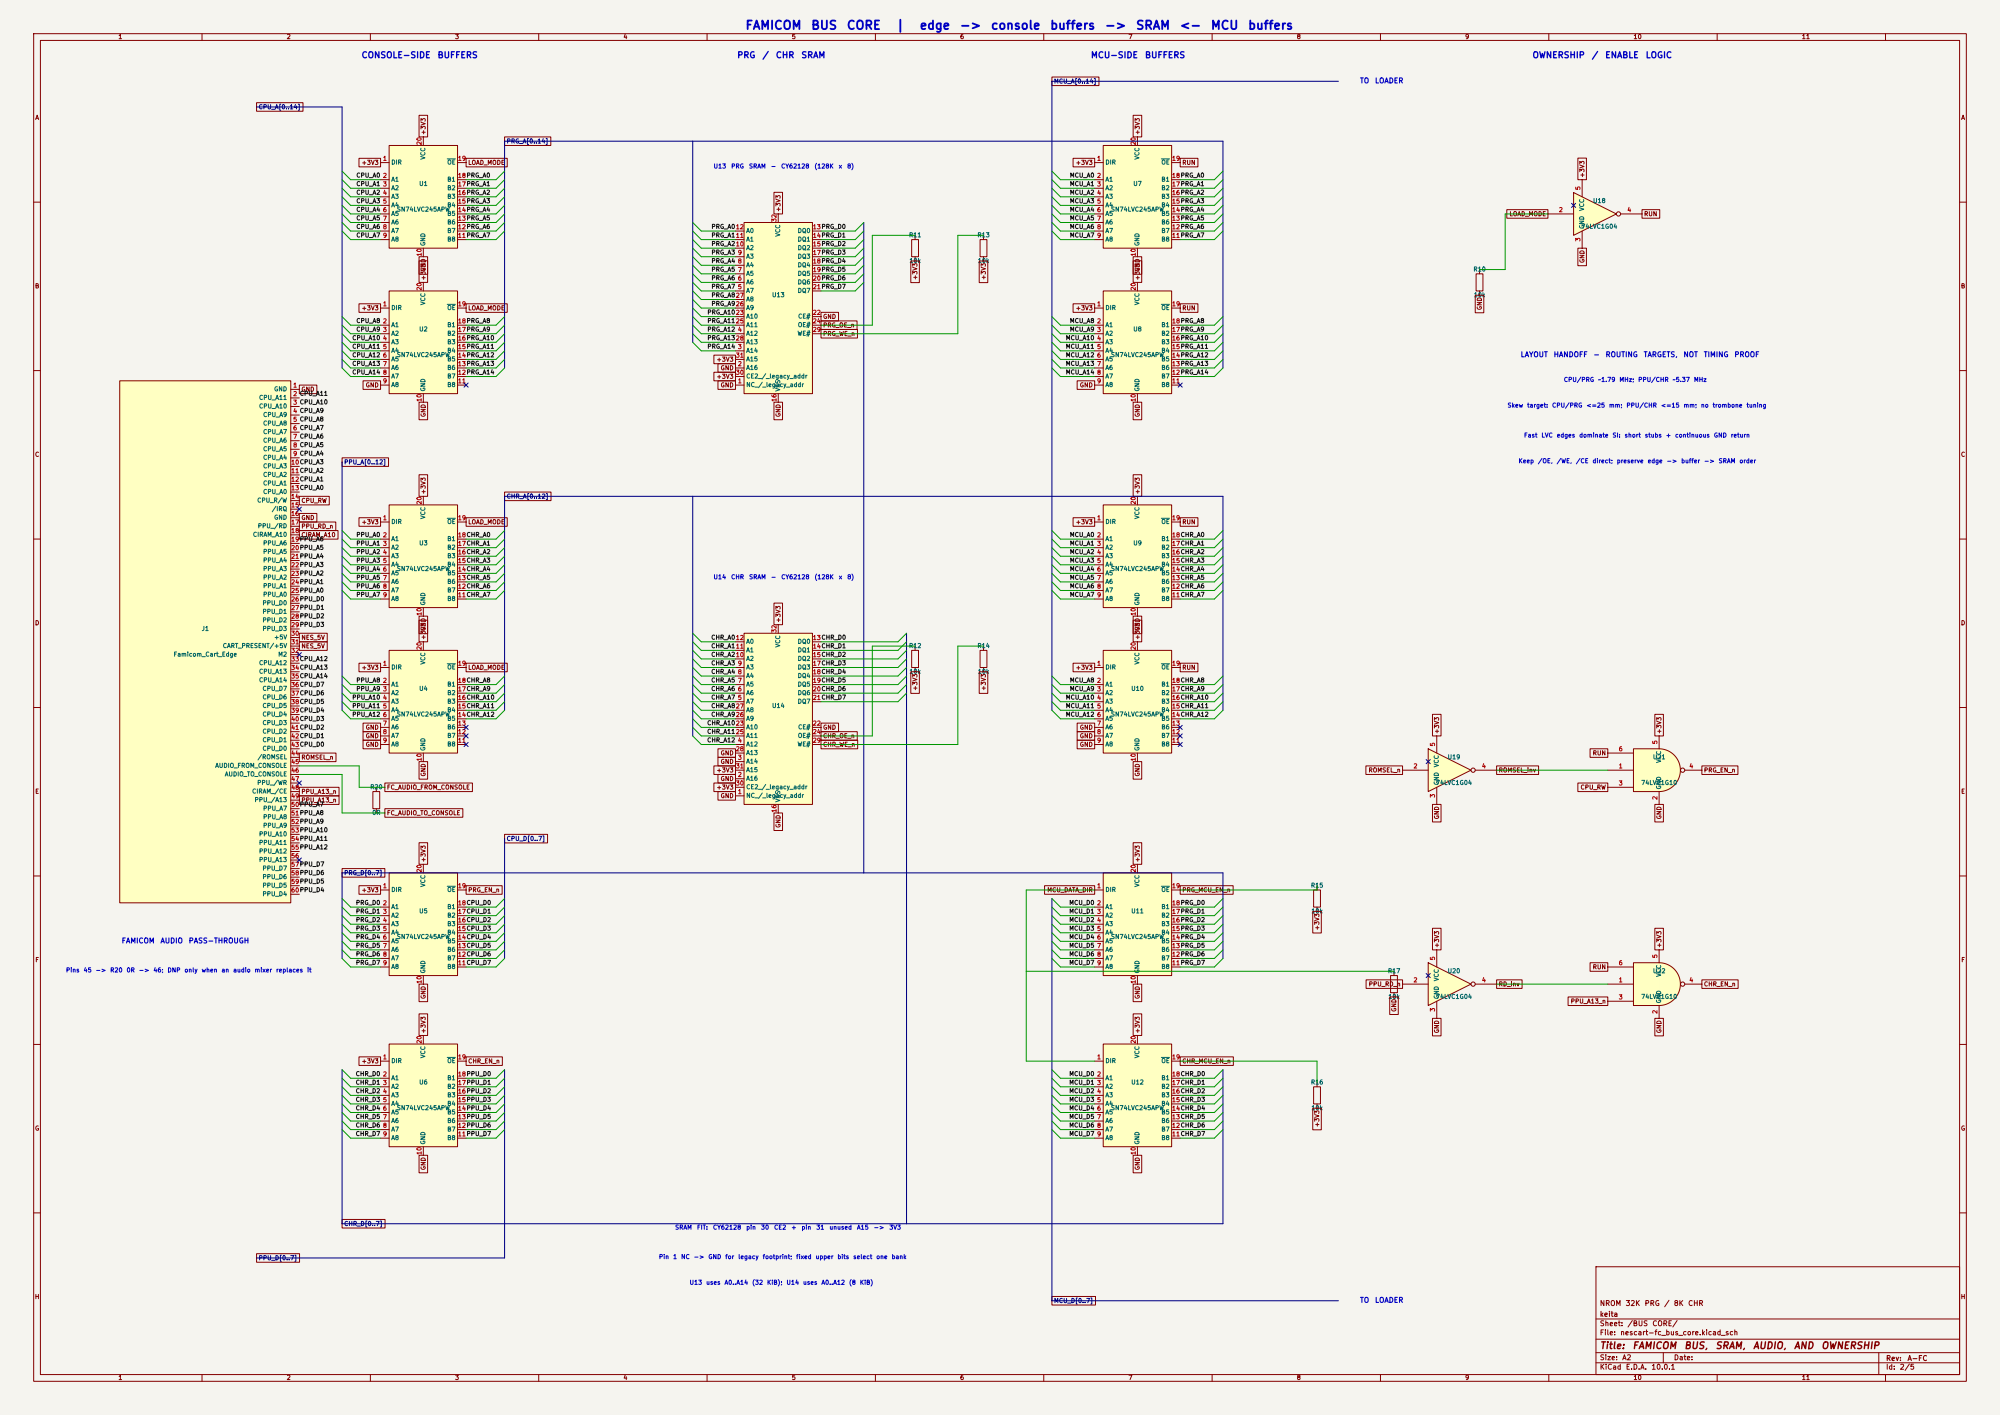
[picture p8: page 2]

FAMICOM BUS CORE | edge -> console buffers -> SRAM <- MCU buffers

Keep /OE, /WE, /CE direct; preserve edge -> buffer -> SRAM order CONSOLE-SIDE BUFFERS

Fast LVC edges dominate SI: short stubs + continuous GND return Skew target: CPU/PRG <=25 mm; PPU/CHR <=15 mm; no trombone tuning

FAMICOM AUDIO PASS-THROUGH

Pins 45 -> R20 0R -> 46; DNP only when an audio mixer replaces it

SRAM FIT: CY62128 pin 30 CE2 + pin 31 unused A15 -> 3V3

Pin 1 NC -> GND for legacy footprint; fixed upper bits select one bank

U13 uses A0..A14 (32 KiB); U14 uses A0..A12 (8 KiB)

NROM 32K PRG / 8K CHR
keita
Sheet: /BUS CORE/
File: nescart-fc_bus_core.kicad_sch
Title: FAMICOM BUS, SRAM, AUDIO, AND OWNERSHIP

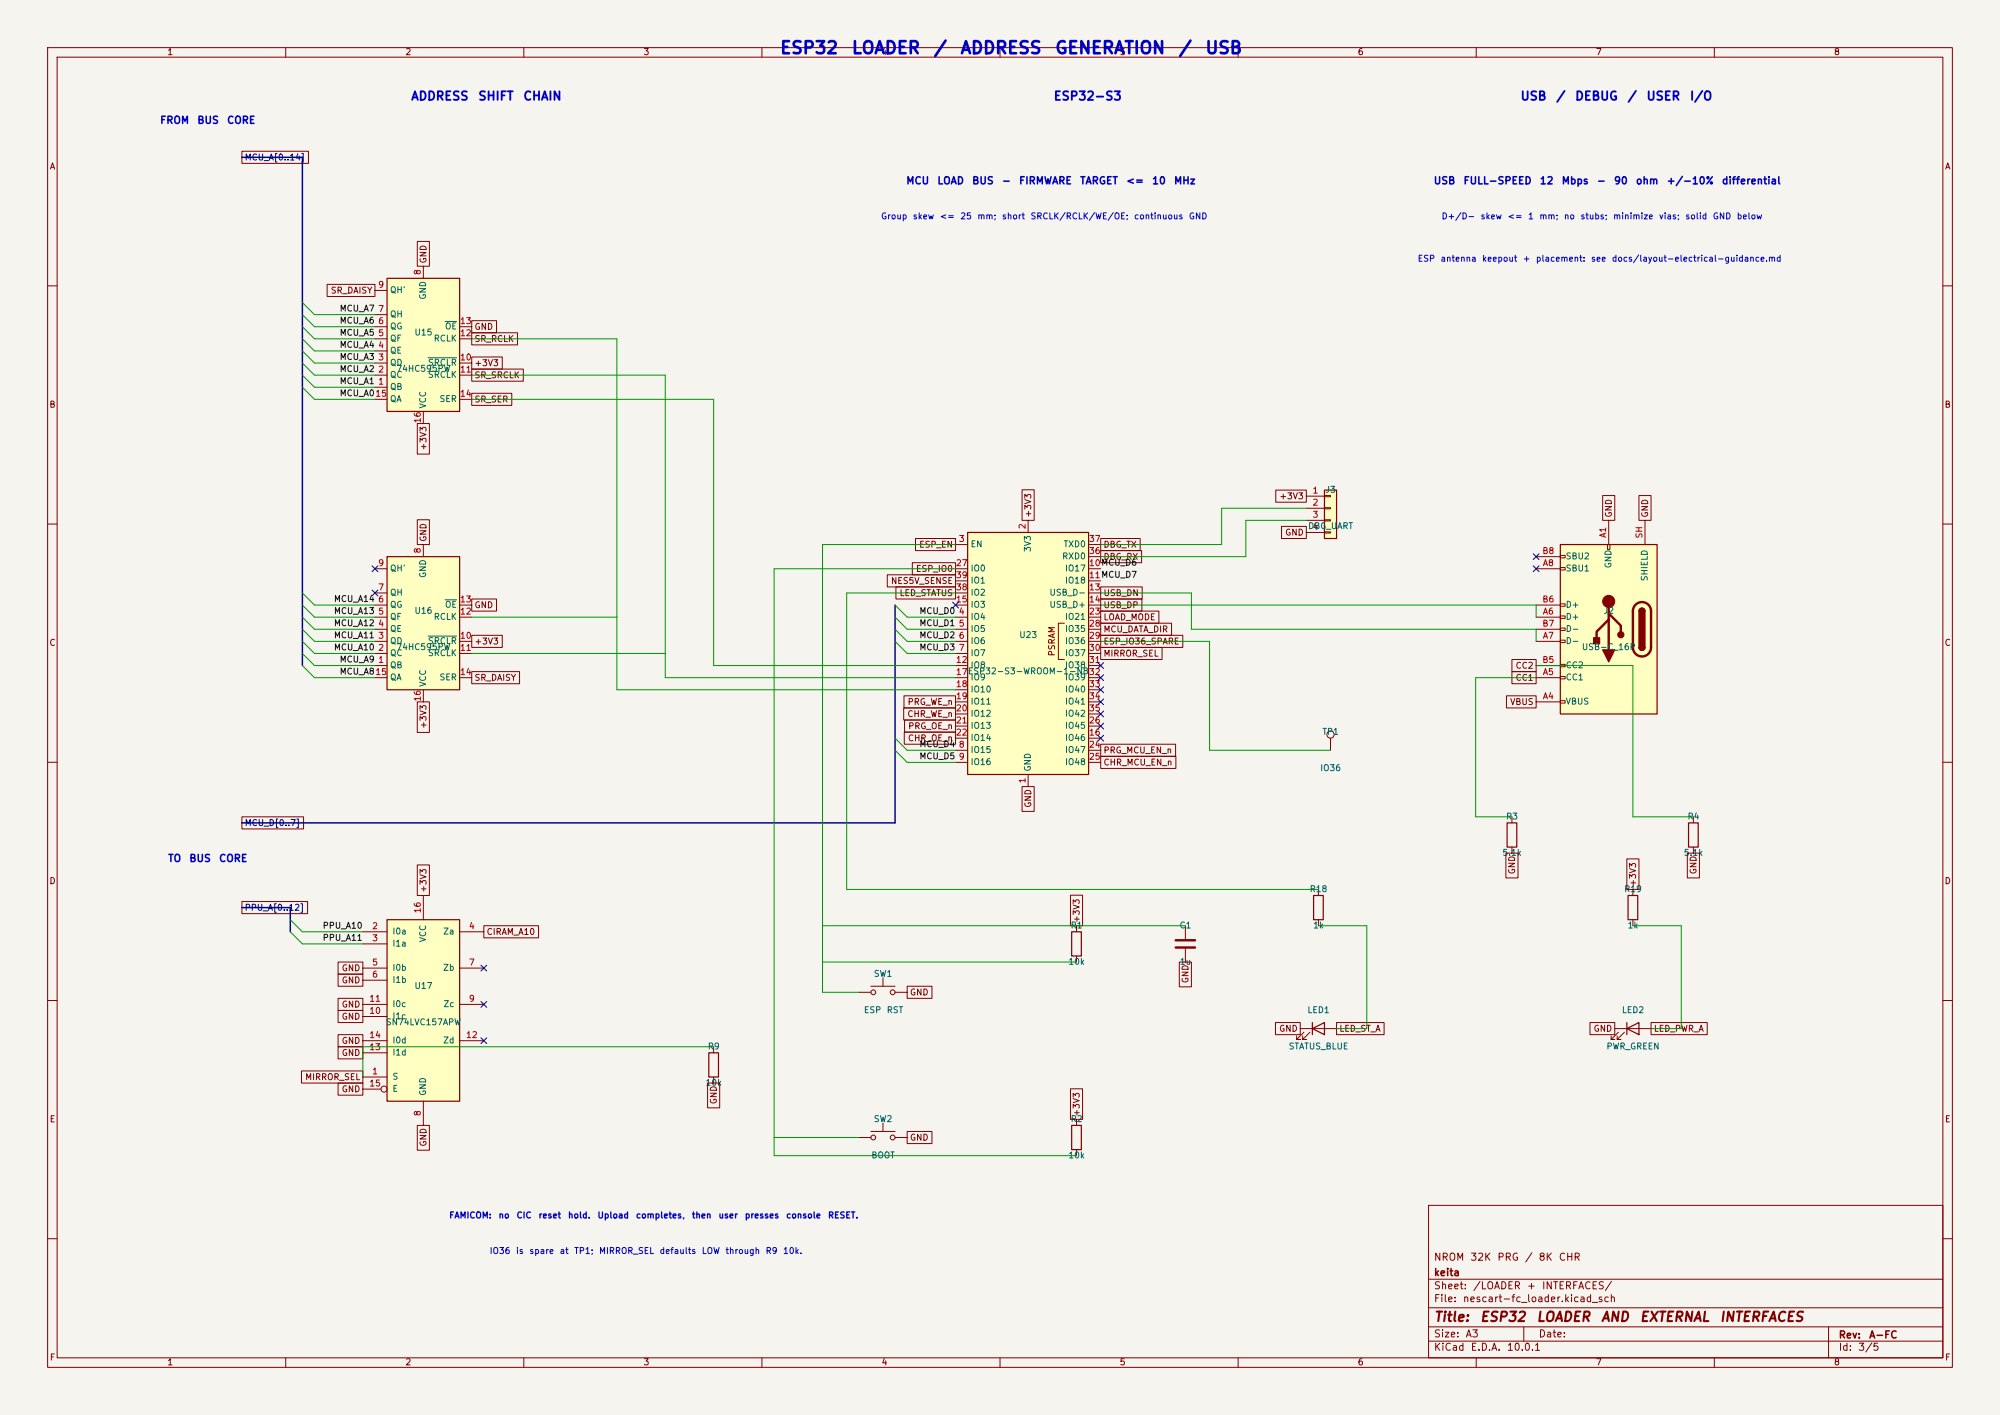
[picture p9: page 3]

ESP32 LOADER / ADDRESS GENERATION / USB

MCU LOAD BUS - FIRMWARE TARGET <= 10 MHz

D+/D- skew <= 1 mm; no stubs; minimize vias; solid GND below

ESP antenna keepout + placement: see docs/layout-electrical-guidance.md

IO9 17
IO10 18
IO11 19 IO12 20 IO13 21 IO14 22 IO15 8 IO16 9

IO36 is spare at TP1; MIRROR_SEL defaults LOW through R9 10k.

NROM 32K PRG / 8K CHR
keita
Sheet: /LOADER + INTERFACES/
File: nescart-fc_loader.kicad_sch
Title: ESP32 LOADER AND EXTERNAL INTERFACES

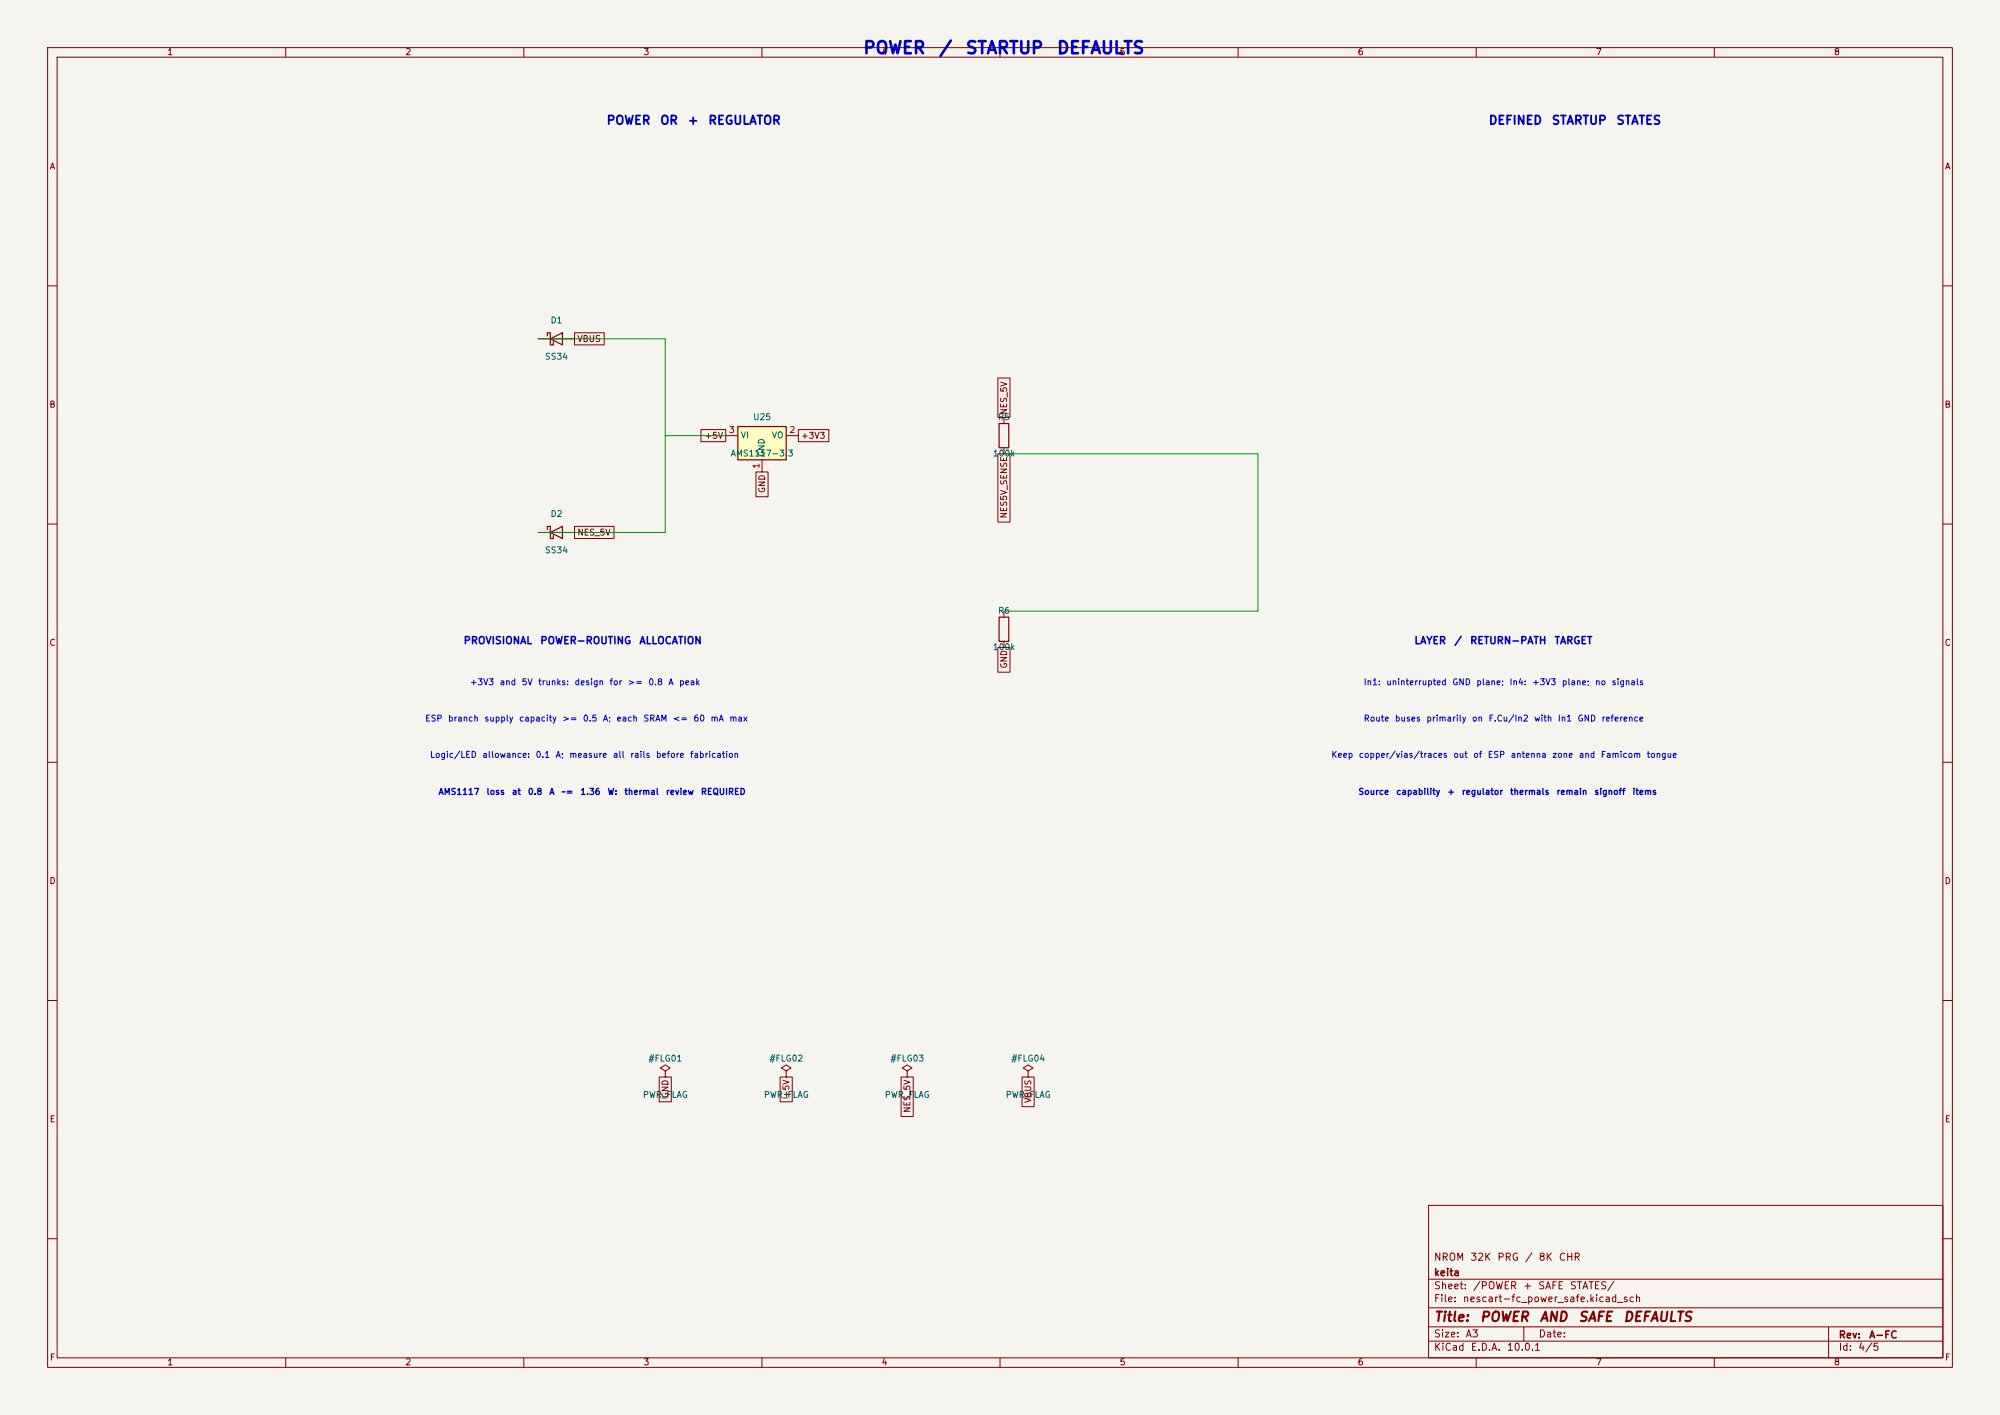
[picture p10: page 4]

Source capability + regulator thermals remain signoff items POWER / STARTUP DEFAULTS

NROM 32K PRG / 8K CHR GND

PROVISIONAL POWER-ROUTING ALLOCATION

LAYER / RETURN-PATH TARGET

ESP branch supply capacity >= 0.5 A; each SRAM <= 60 mA max +3V3 and 5V trunks: design for >= 0.8 A peak

In1: uninterrupted GND plane; In4: +3V3 plane; no signals

Keep copper/vias/traces out of ESP antenna zone and Famicom tongue Route buses primarily on F.Cu/In2 with In1 GND reference

Logic/LED allowance: 0.1 A; measure all rails before fabrication

AMS1117 loss at 0.8 A ~= 1.36 W: thermal review REQUIRED

keita
Sheet: /POWER + SAFE STATES/
File: nescart-fc_power_safe.kicad_sch
Title: POWER AND SAFE DEFAULTS

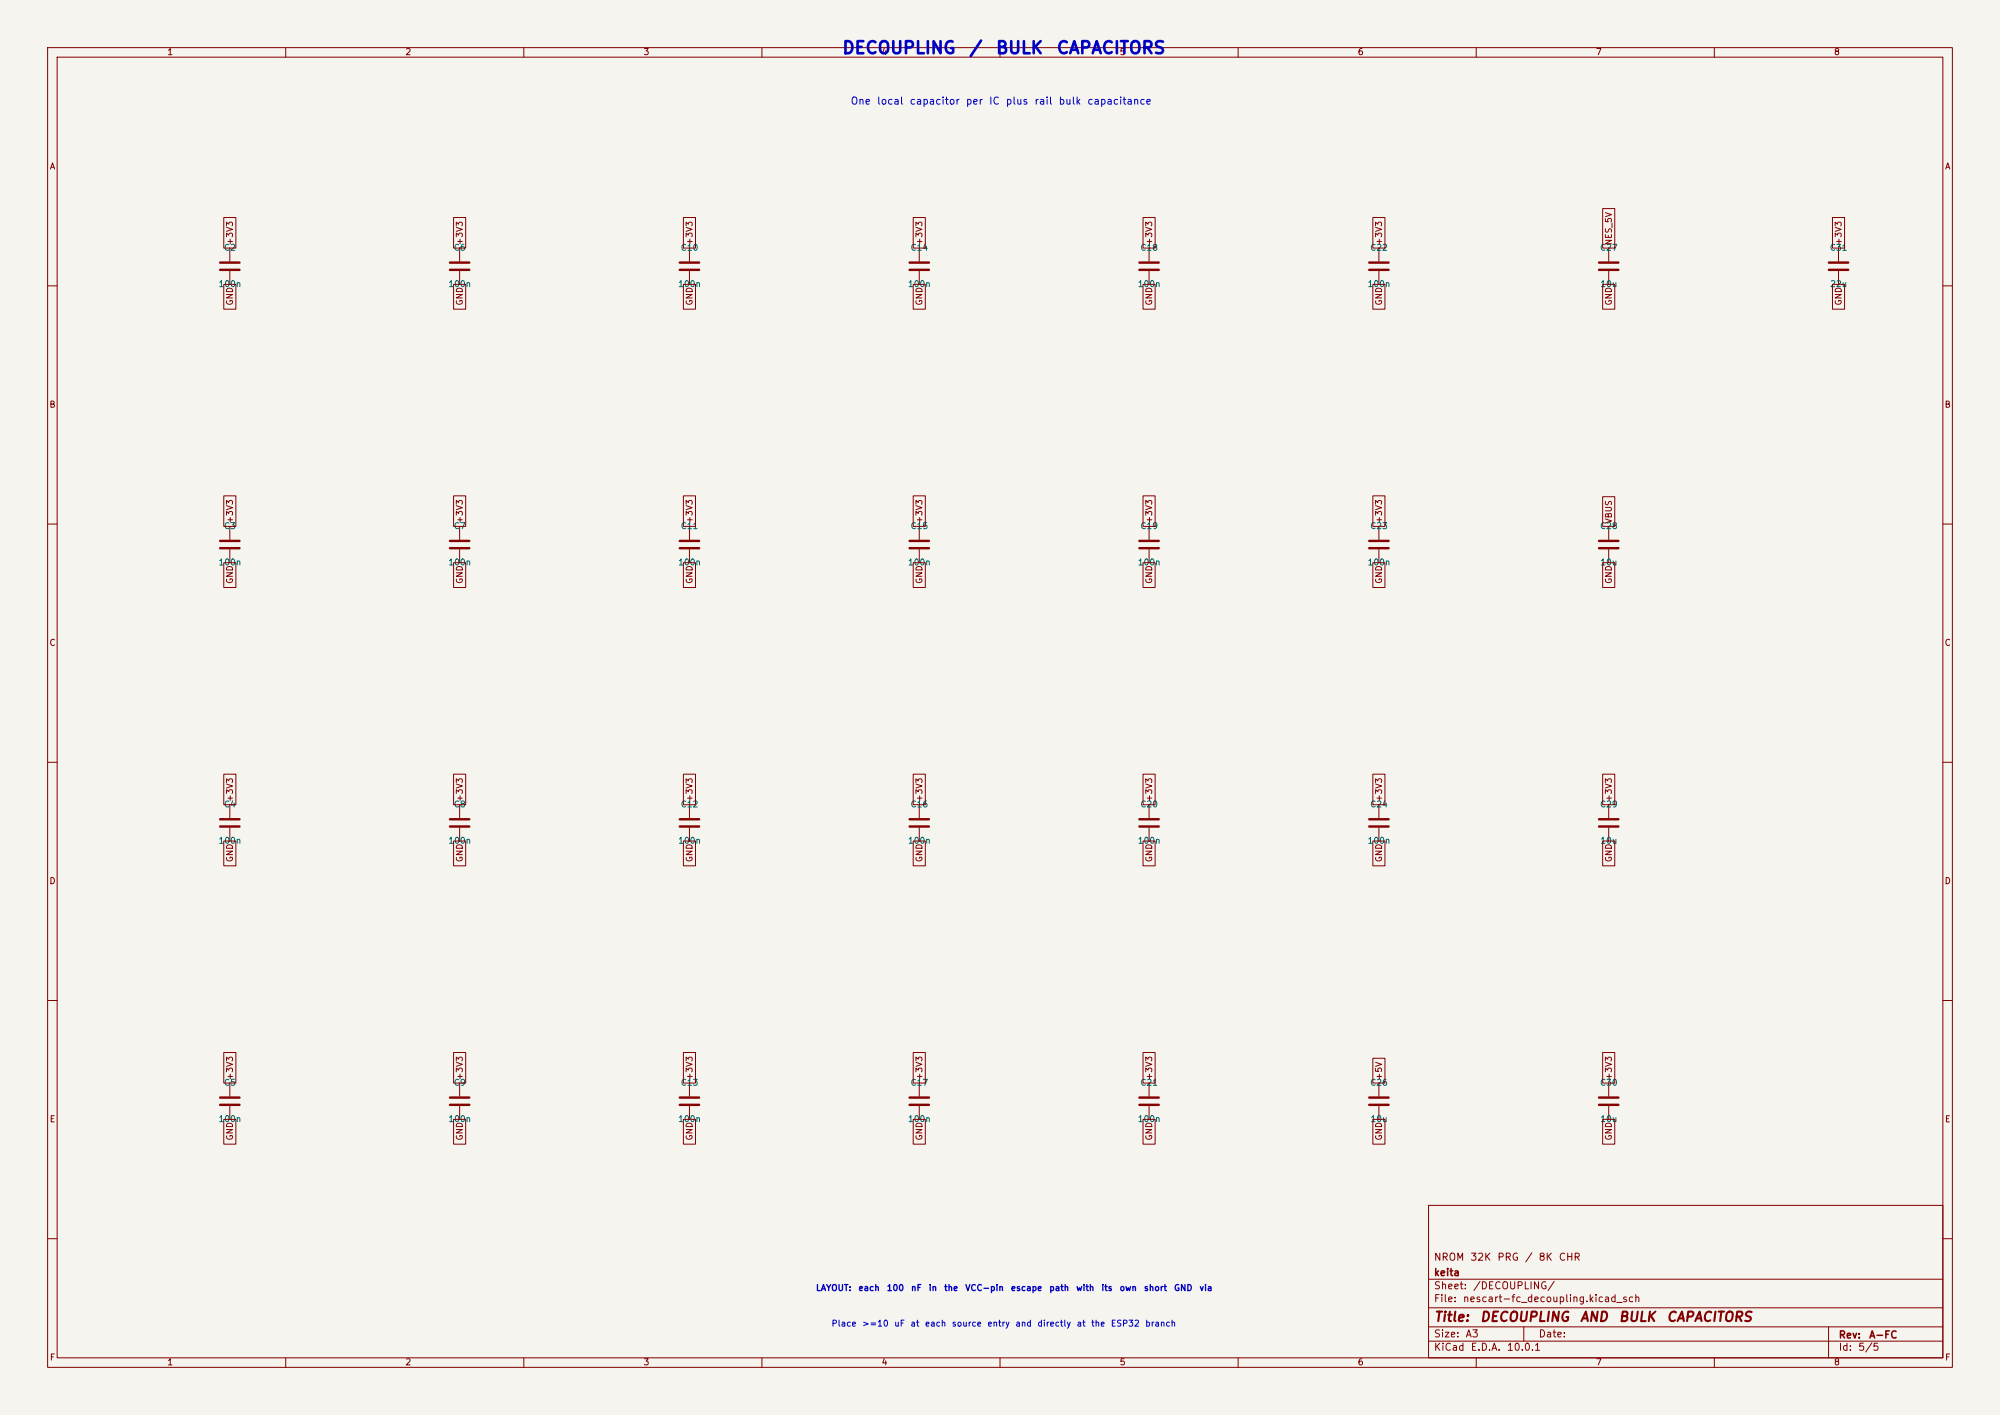
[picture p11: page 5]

One local capacitor per IC plus rail bulk capacitance

NROM 32K PRG / 8K CHR
keita
Sheet: /DECOUPLING/
File: nescart-fc_decoupling.kicad_sch
Title: DECOUPLING AND BULK CAPACITORS

LAYOUT: each 100 nF in the VCC-pin escape path with its own short GND via

Place >=10 uF at each source entry and directly at the ESP32 branch

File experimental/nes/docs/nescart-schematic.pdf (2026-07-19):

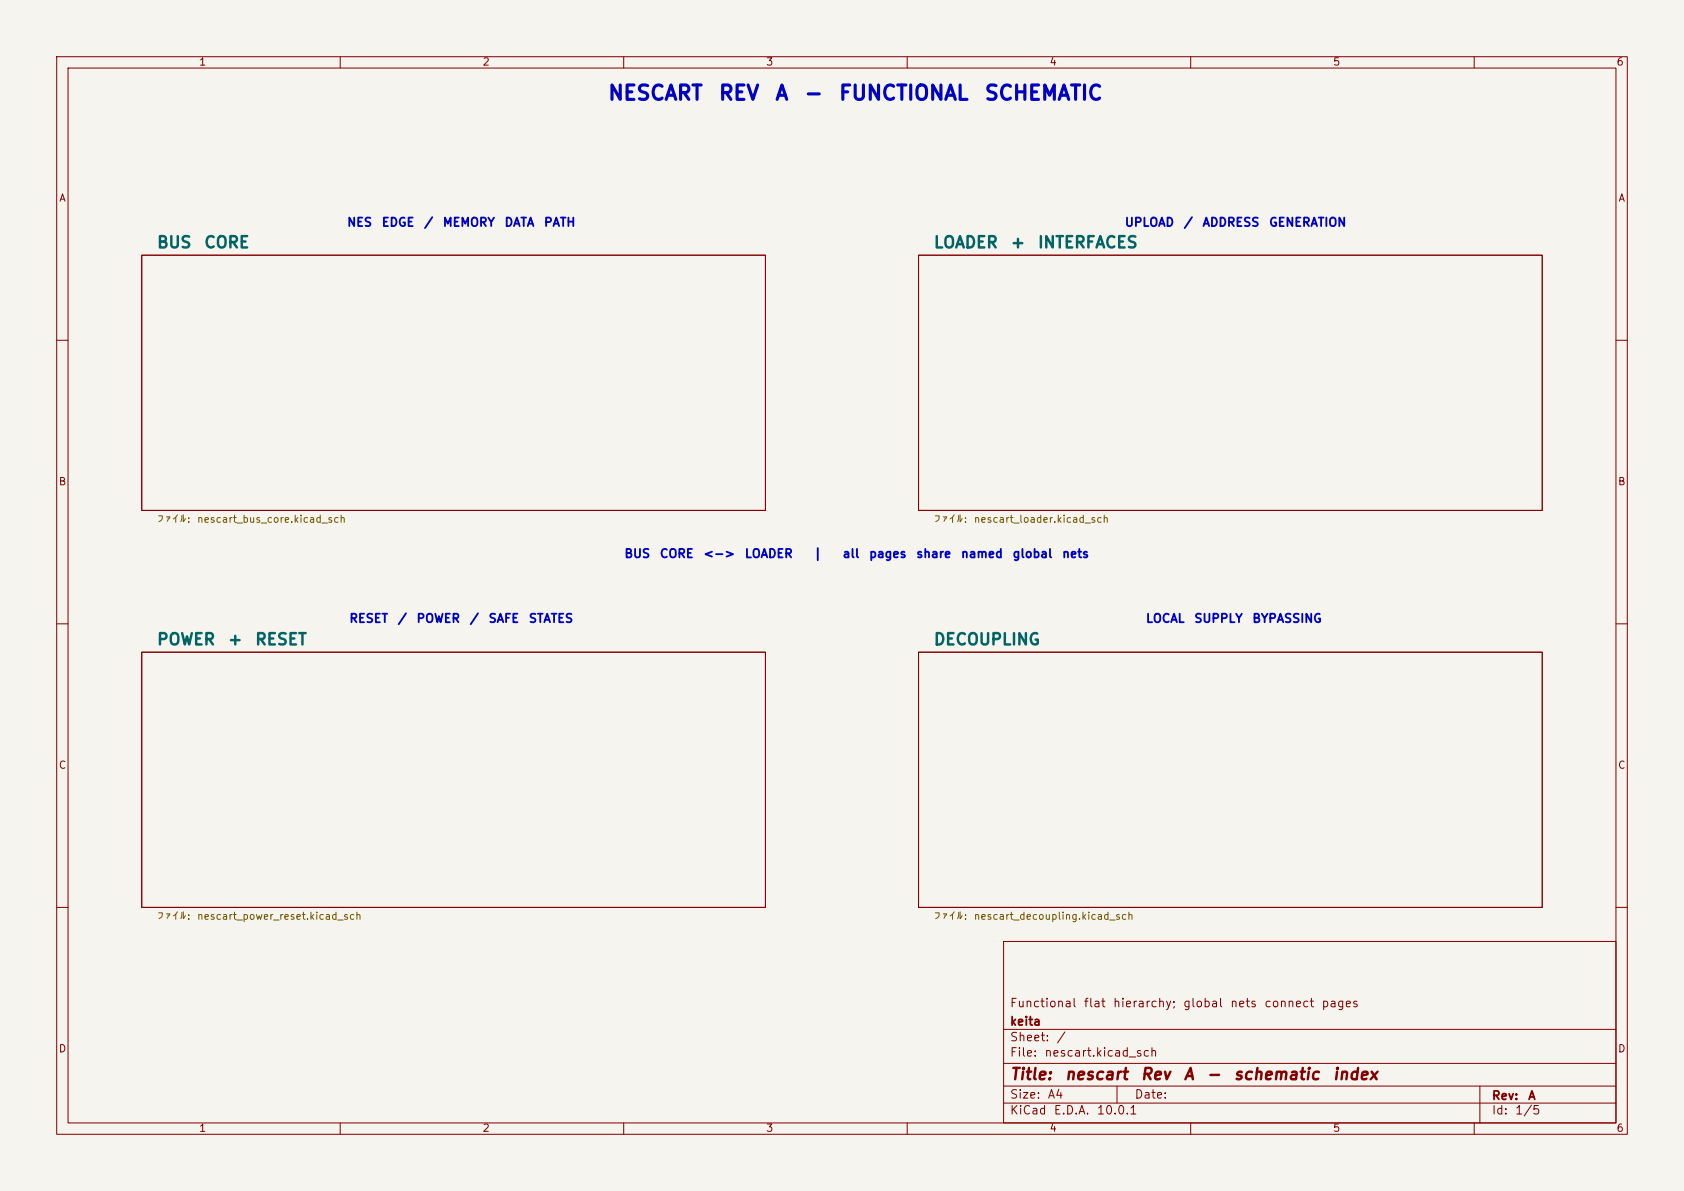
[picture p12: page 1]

NESCART REV A - FUNCTIONAL SCHEMATIC

NES EDGE / MEMORY DATA PATH

RESET / POWER / SAFE STATES

Functional flat hierarchy; global nets connect pages
keita
Sheet: /
File: nescart.kicad_sch
Title: nescart Rev A - schematic index

Size: A4 | Rev: A
KiCad E.D.A. 10.0.1 | Id: 1/5

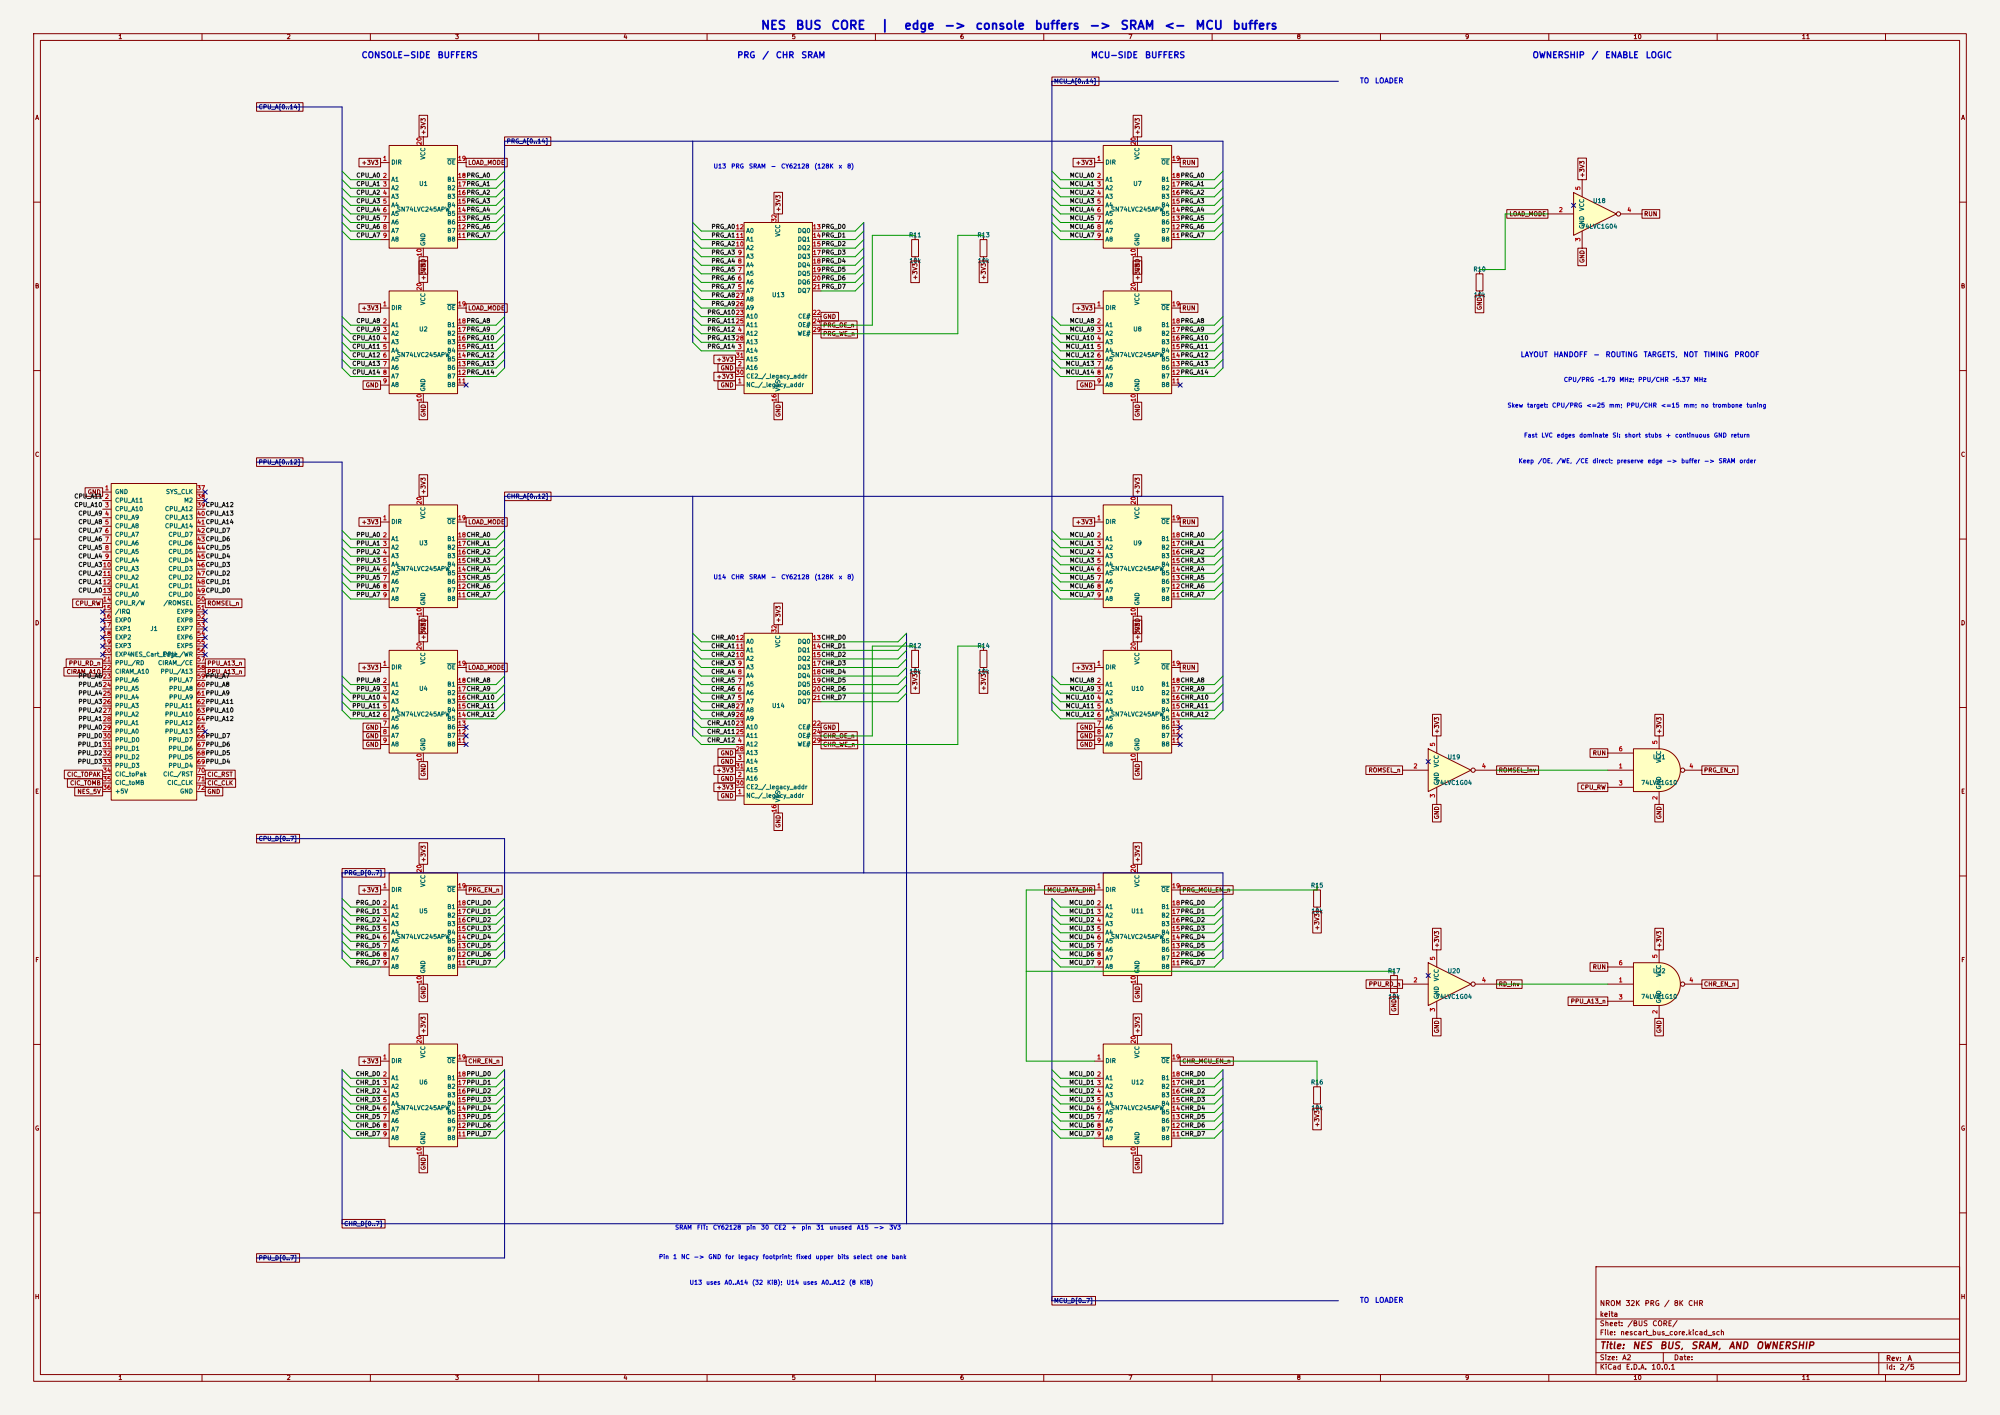
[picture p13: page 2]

NES BUS CORE | edge -> console buffers -> SRAM <- MCU buffers

Fast LVC edges dominate SI: short stubs + continuous GND return MCU-SIDE BUFFERS

CPU/PRG ~1.79 MHz; PPU/CHR ~5.37 MHz LAYOUT HANDOFF - ROUTING TARGETS, NOT TIMING PROOF

Skew target: CPU/PRG <=25 mm; PPU/CHR <=15 mm; no trombone tuning

Keep /OE, /WE, /CE direct; preserve edge -> buffer -> SRAM order

A8 9 GND 10 B8 11 B7 12 B6 13 B5 14 B4 15 B3 16 B2 17 B1 18 OE VCC DIR 1 A1 2 A2 3 A3 4 A4 5 A5 6 SN74LVC245APW A6 7 A7 8 | 19 20 U5 | GND 10 B8 11 B7 12 B6 13 B5 14 B4 15 B3 16 B2 17 B1 18 OE VCC DIR 1 SN74LVC245APW | 19 20 U11

SRAM FIT: CY62128 pin 30 CE2 + pin 31 unused A15 -> 3V3 Pin 1 NC -> GND for legacy footprint; fixed upper bits select one bank U13 uses A0..A14 (32 KiB); U14 uses A0..A12 (8 KiB)

NROM 32K PRG / 8K CHR
keita
Sheet: /BUS CORE/
File: nescart_bus_core.kicad_sch
Title: NES BUS, SRAM, AND OWNERSHIP

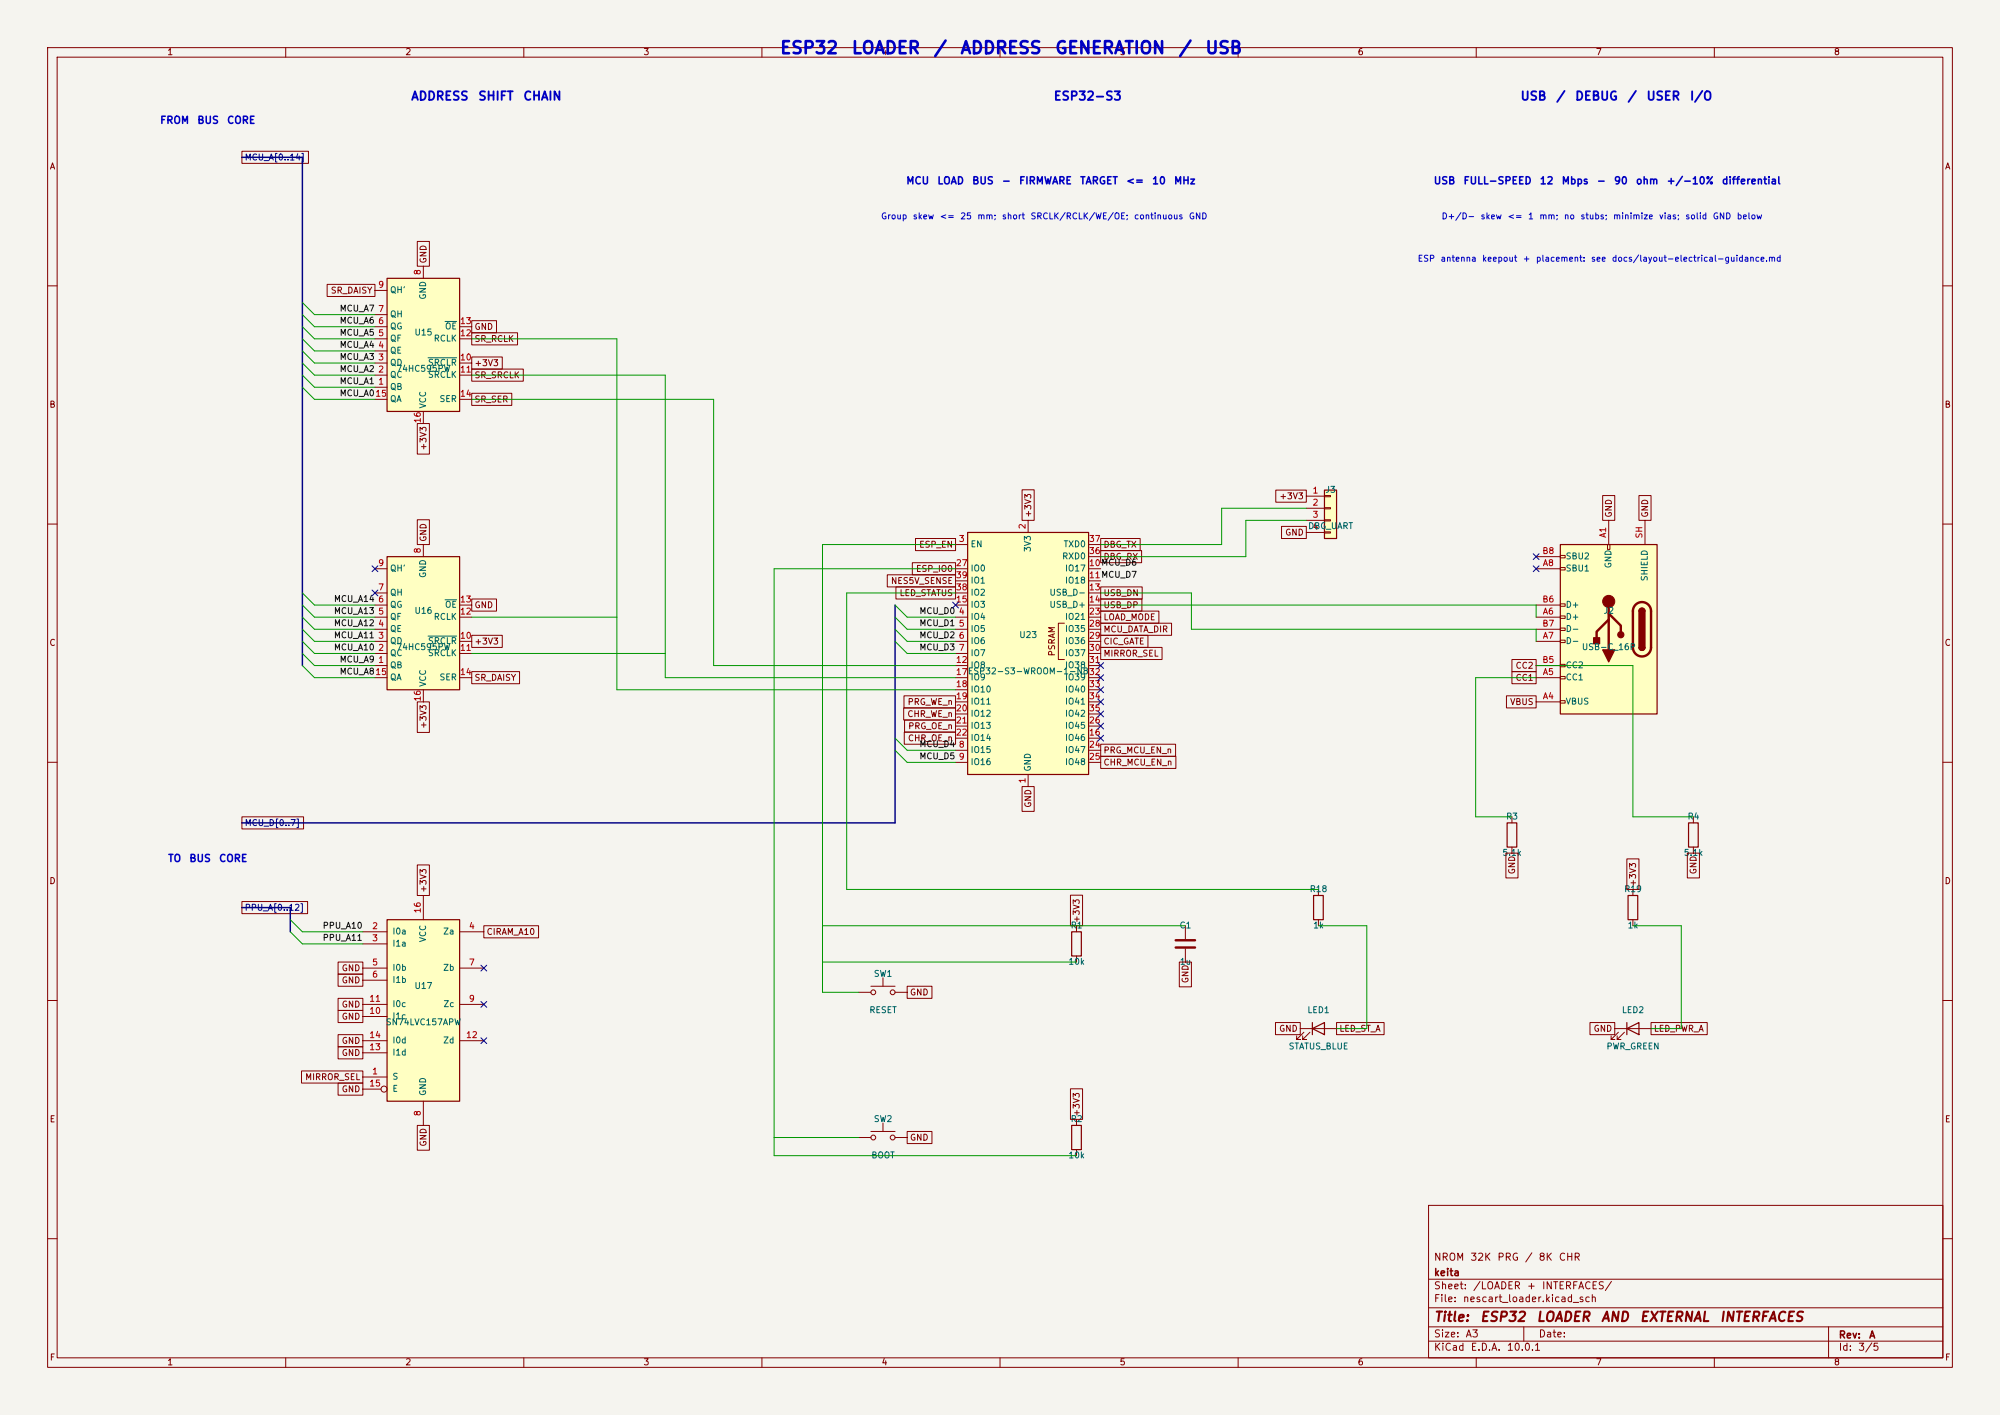
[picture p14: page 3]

ESP32 LOADER / ADDRESS GENERATION / USB

MCU LOAD BUS - FIRMWARE TARGET <= 10 MHz

D+/D- skew <= 1 mm; no stubs; minimize vias; solid GND below

ESP antenna keepout + placement: see docs/layout-electrical-guidance.md

IO9 17
IO10 18
IO11 19 IO12 20 IO13 21 IO14 22 IO15 8 IO16 9

NROM 32K PRG / 8K CHR
keita
Sheet: /LOADER + INTERFACES/
File: nescart_loader.kicad_sch
Title: ESP32 LOADER AND EXTERNAL INTERFACES

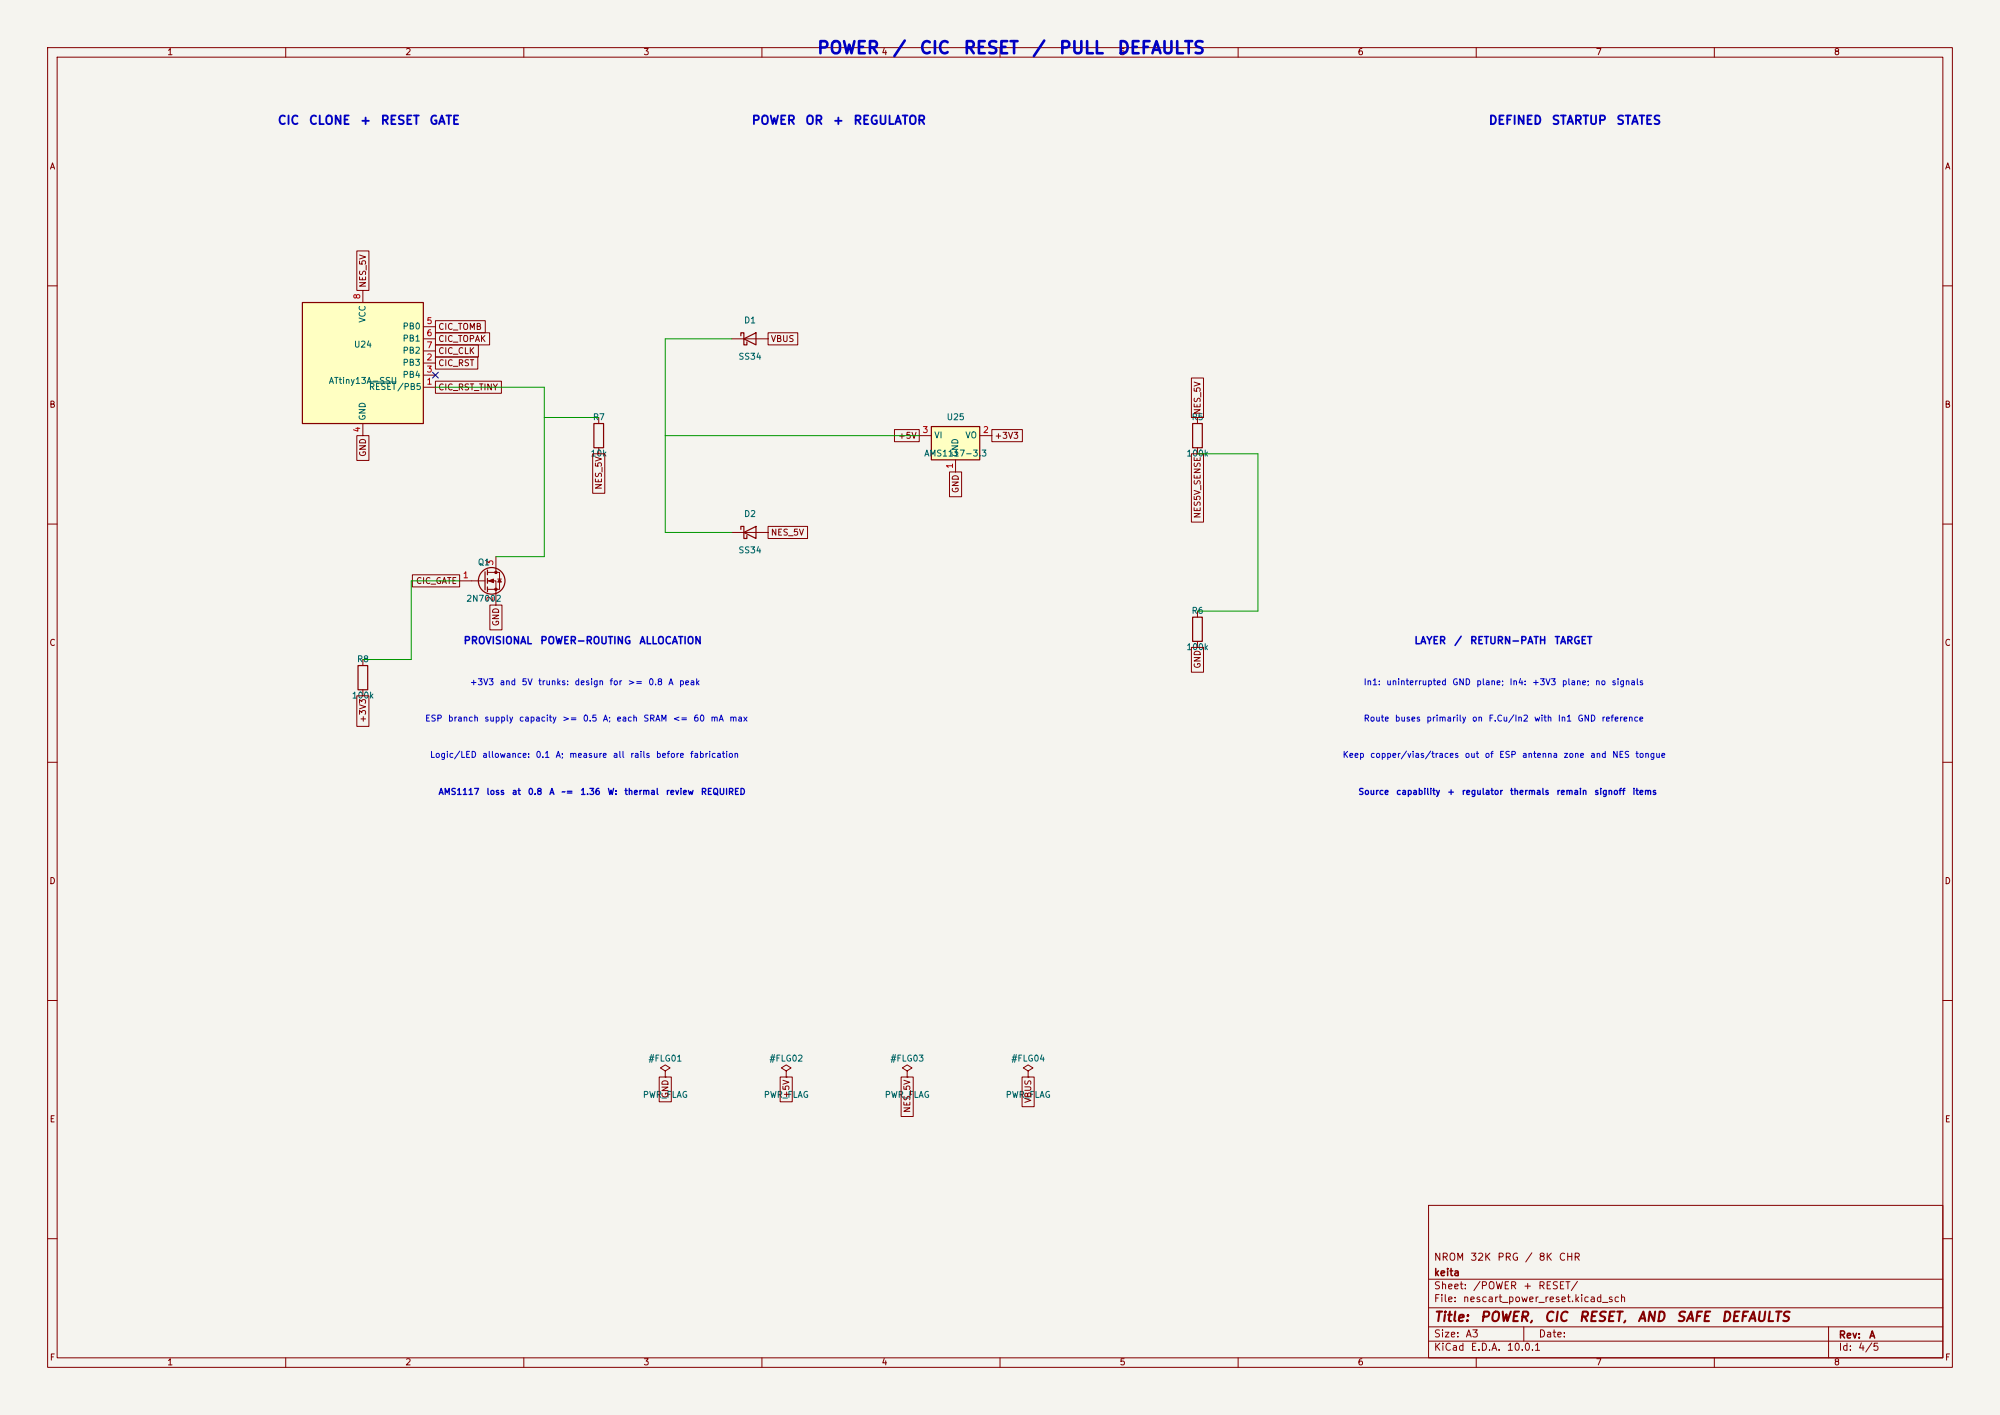
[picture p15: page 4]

POWER / CIC RESET / PULL DEFAULTS

PROVISIONAL POWER-ROUTING ALLOCATION

LAYER / RETURN-PATH TARGET

AMS1117 loss at 0.8 A ~= 1.36 W: thermal review REQUIRED +3V3 and 5V trunks: design for >= 0.8 A peak

In1: uninterrupted GND plane; In4: +3V3 plane; no signals Route buses primarily on F.Cu/In2 with In1 GND reference Keep copper/vias/traces out of ESP antenna zone and NES tongue

ESP branch supply capacity >= 0.5 A; each SRAM <= 60 mA max

Logic/LED allowance: 0.1 A; measure all rails before fabrication

Source capability + regulator thermals remain signoff items

NROM 32K PRG / 8K CHR
keita
Sheet: /POWER + RESET/
File: nescart_power_reset.kicad_sch
Title: POWER, CIC RESET, AND SAFE DEFAULTS

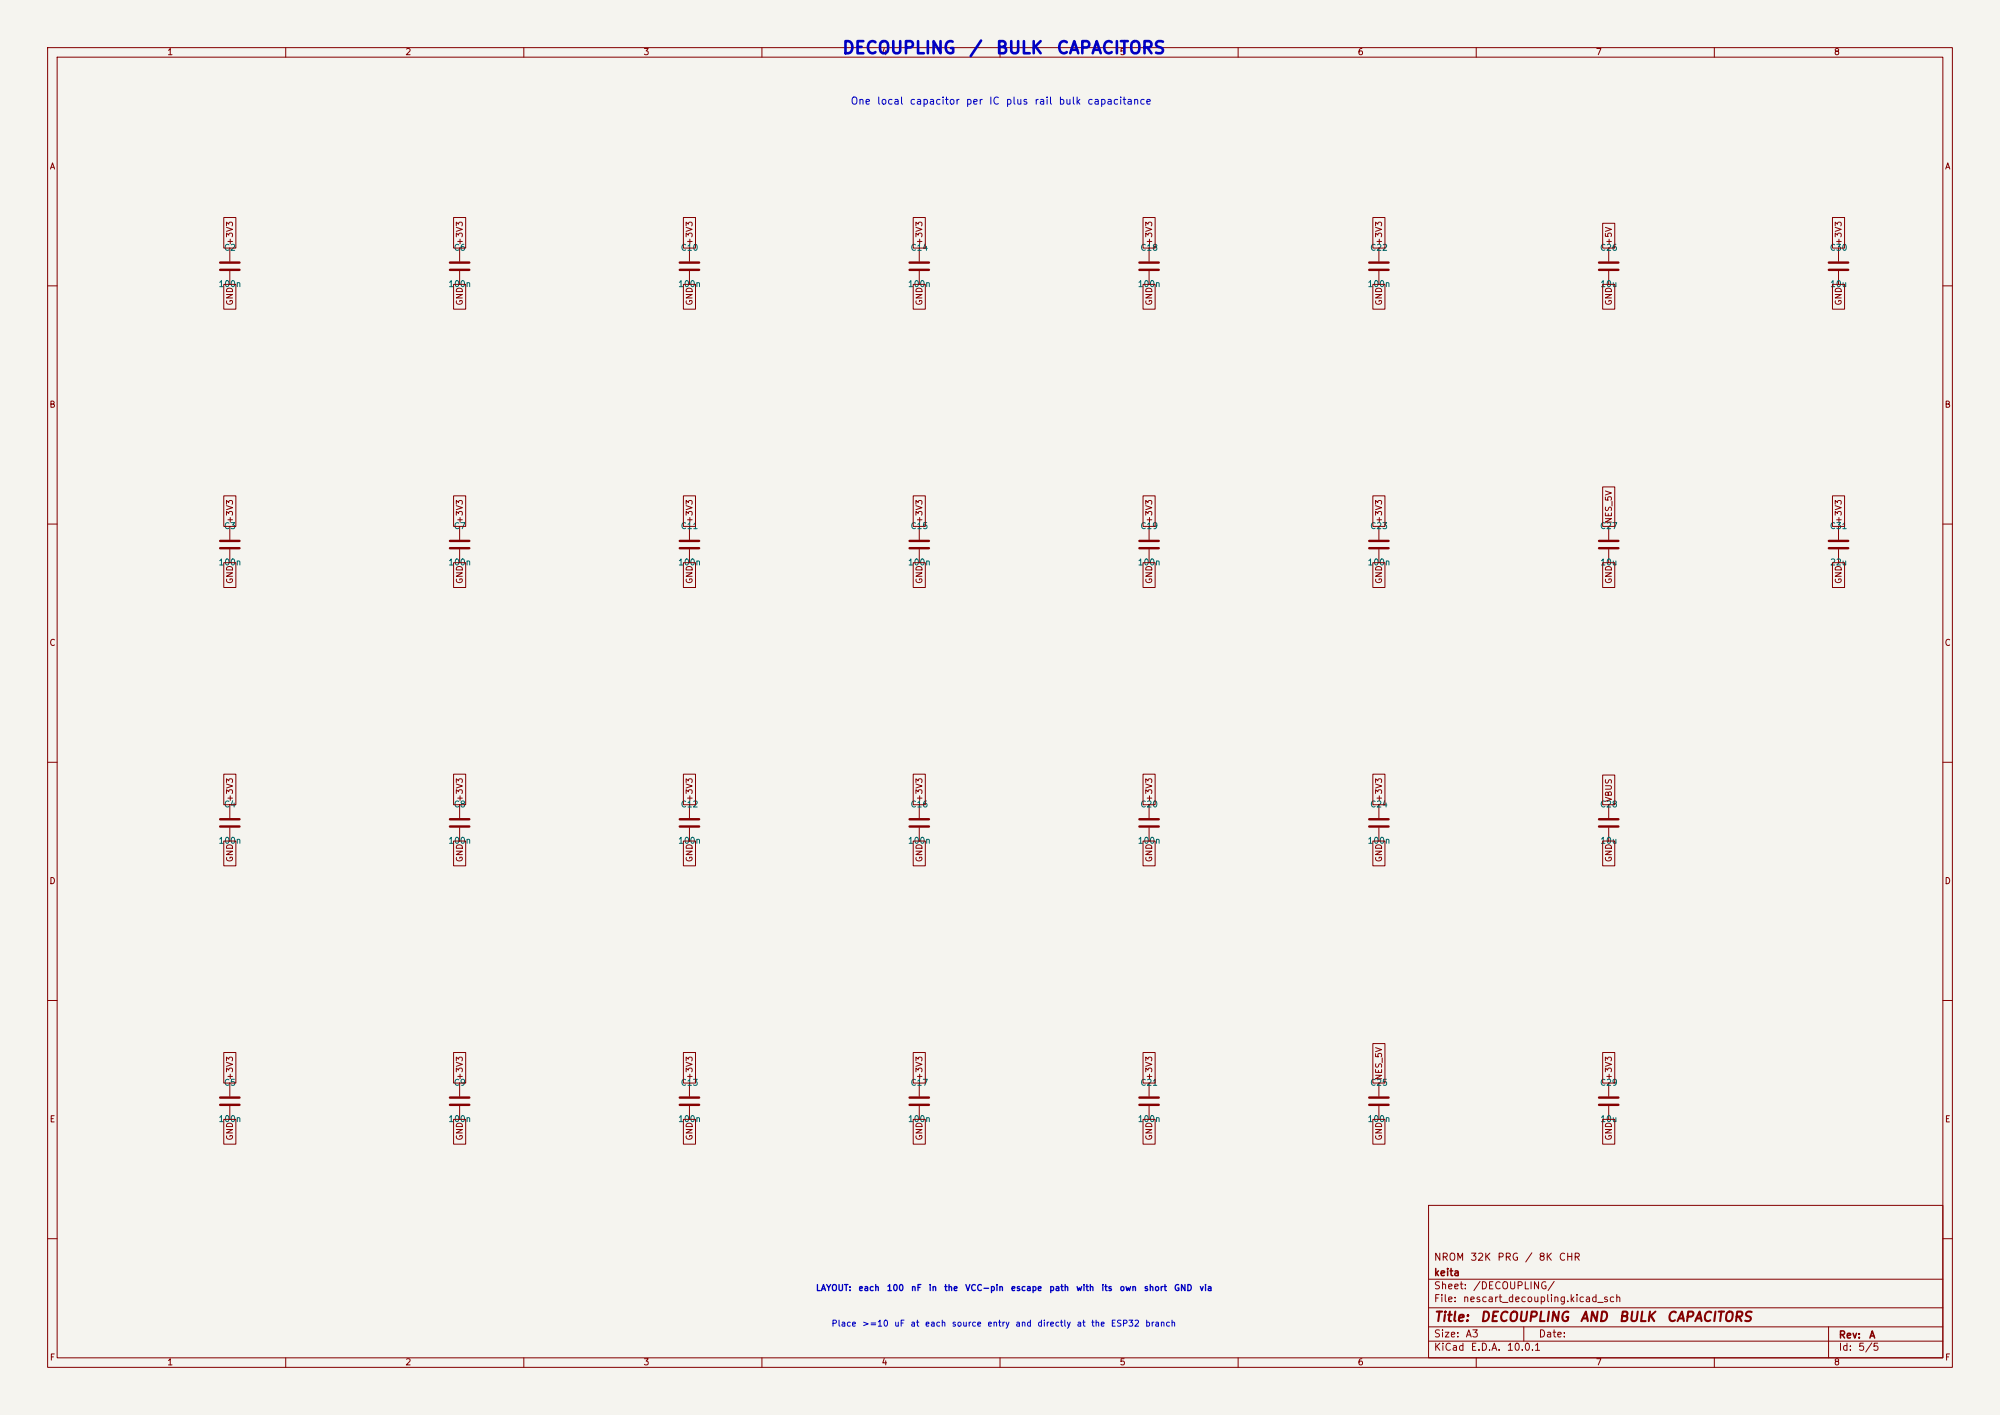
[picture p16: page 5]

One local capacitor per IC plus rail bulk capacitance

NROM 32K PRG / 8K CHR
keita
Sheet: /DECOUPLING/
File: nescart_decoupling.kicad_sch
Title: DECOUPLING AND BULK CAPACITORS

LAYOUT: each 100 nF in the VCC-pin escape path with its own short GND via

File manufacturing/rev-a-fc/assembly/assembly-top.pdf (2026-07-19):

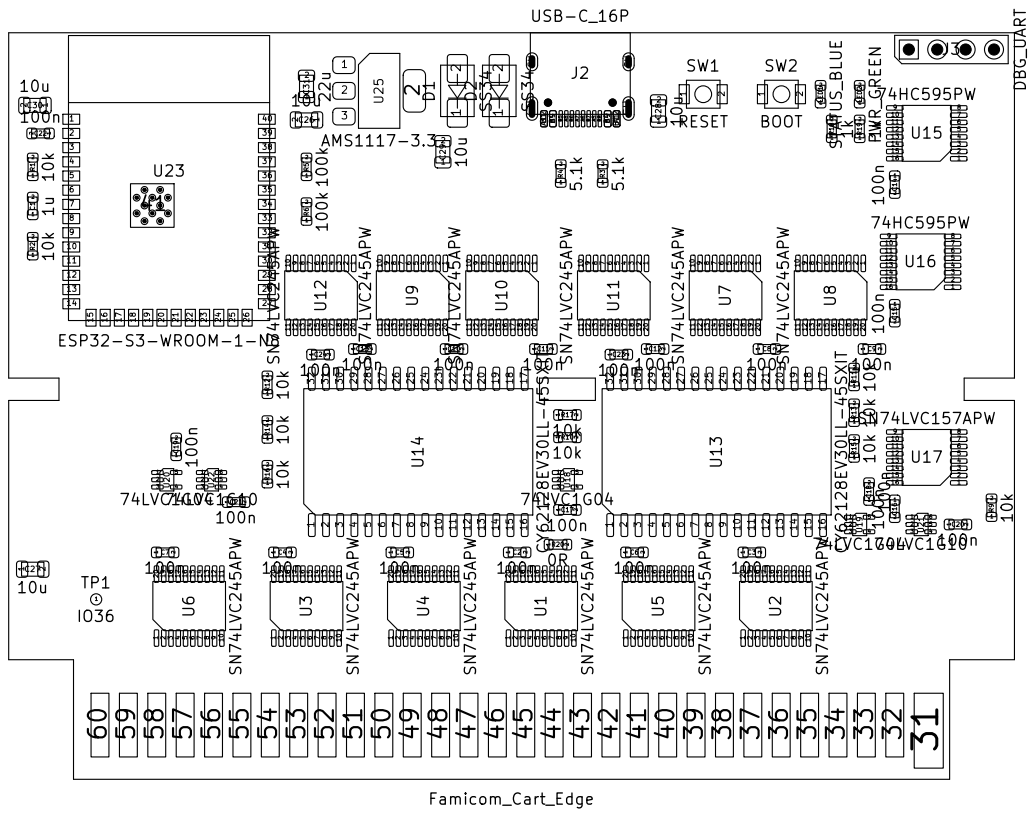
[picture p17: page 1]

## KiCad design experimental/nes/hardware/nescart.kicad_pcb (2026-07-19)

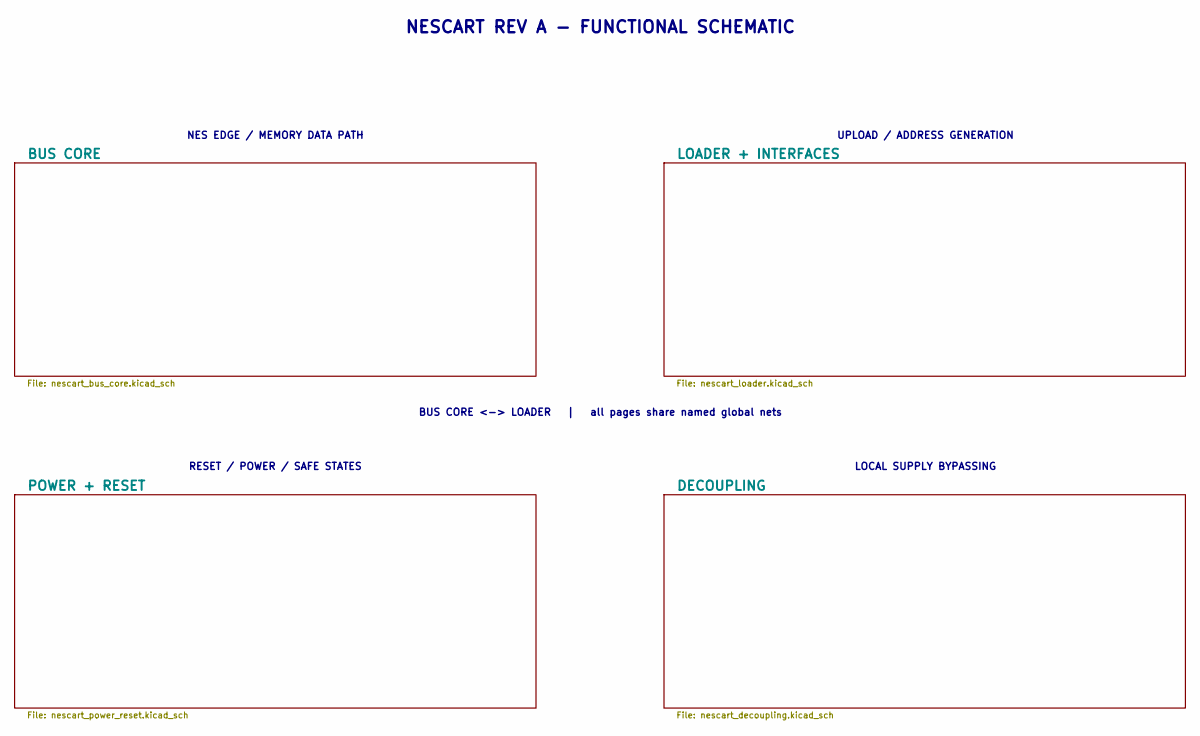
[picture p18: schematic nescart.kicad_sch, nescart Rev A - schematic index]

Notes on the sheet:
NESCART REV A - FUNCTIONAL SCHEMATIC
NES EDGE / MEMORY DATA PATH
UPLOAD / ADDRESS GENERATION
RESET / POWER / SAFE STATES
LOCAL SUPPLY BYPASSING
BUS CORE <-> LOADER | all pages share named global nets

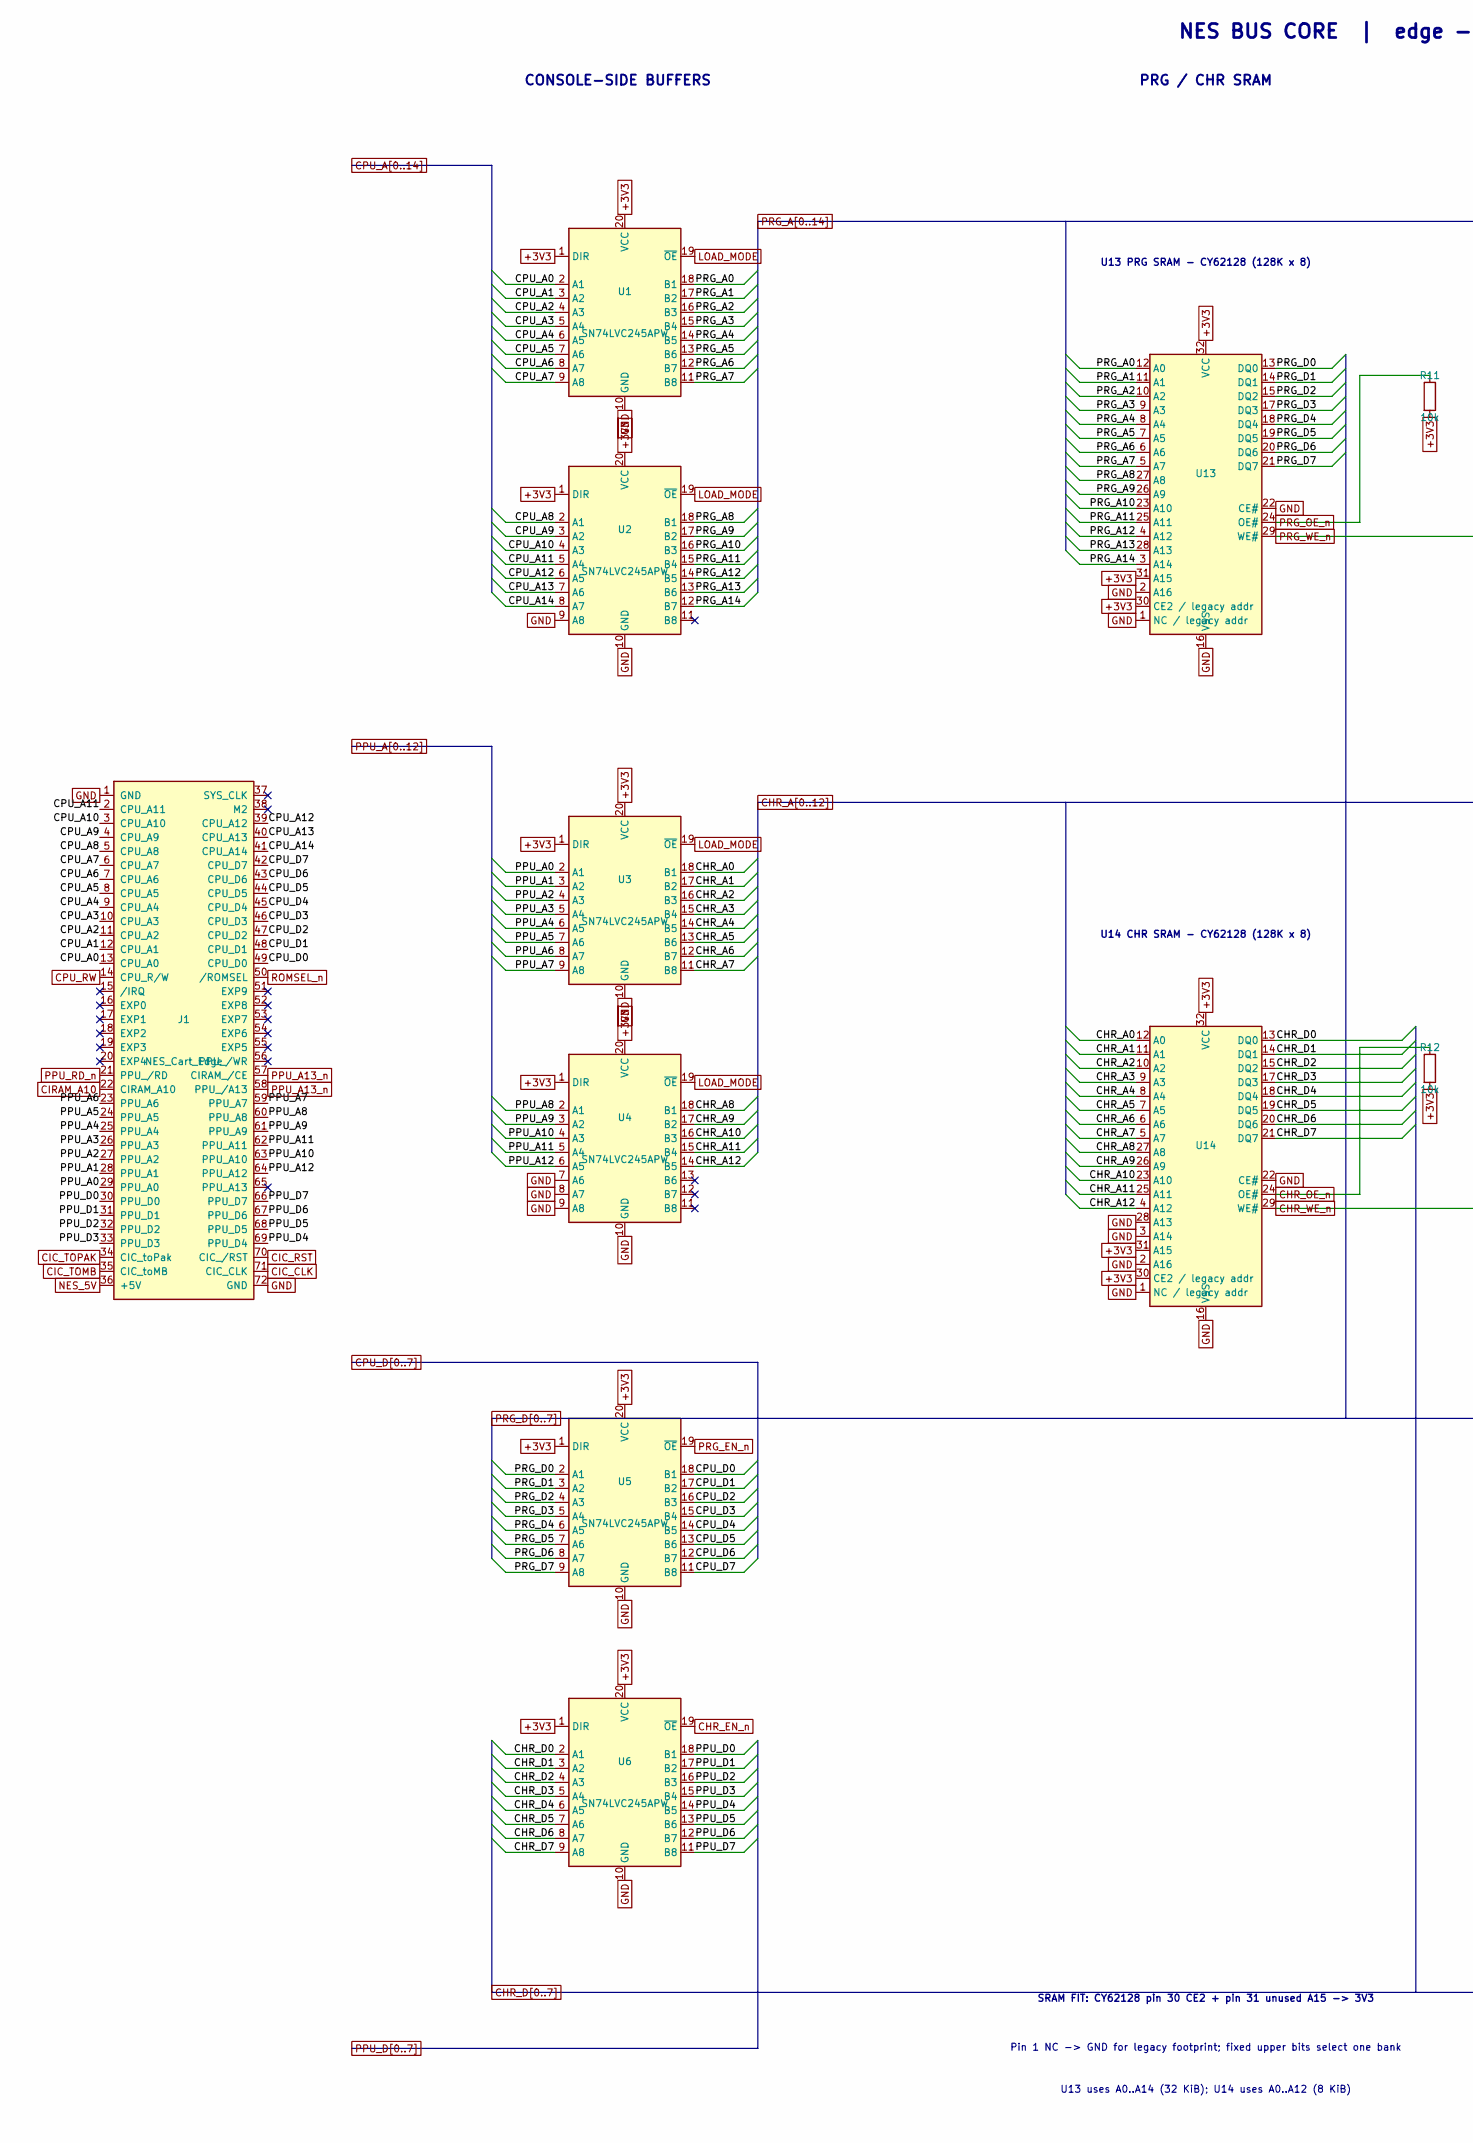
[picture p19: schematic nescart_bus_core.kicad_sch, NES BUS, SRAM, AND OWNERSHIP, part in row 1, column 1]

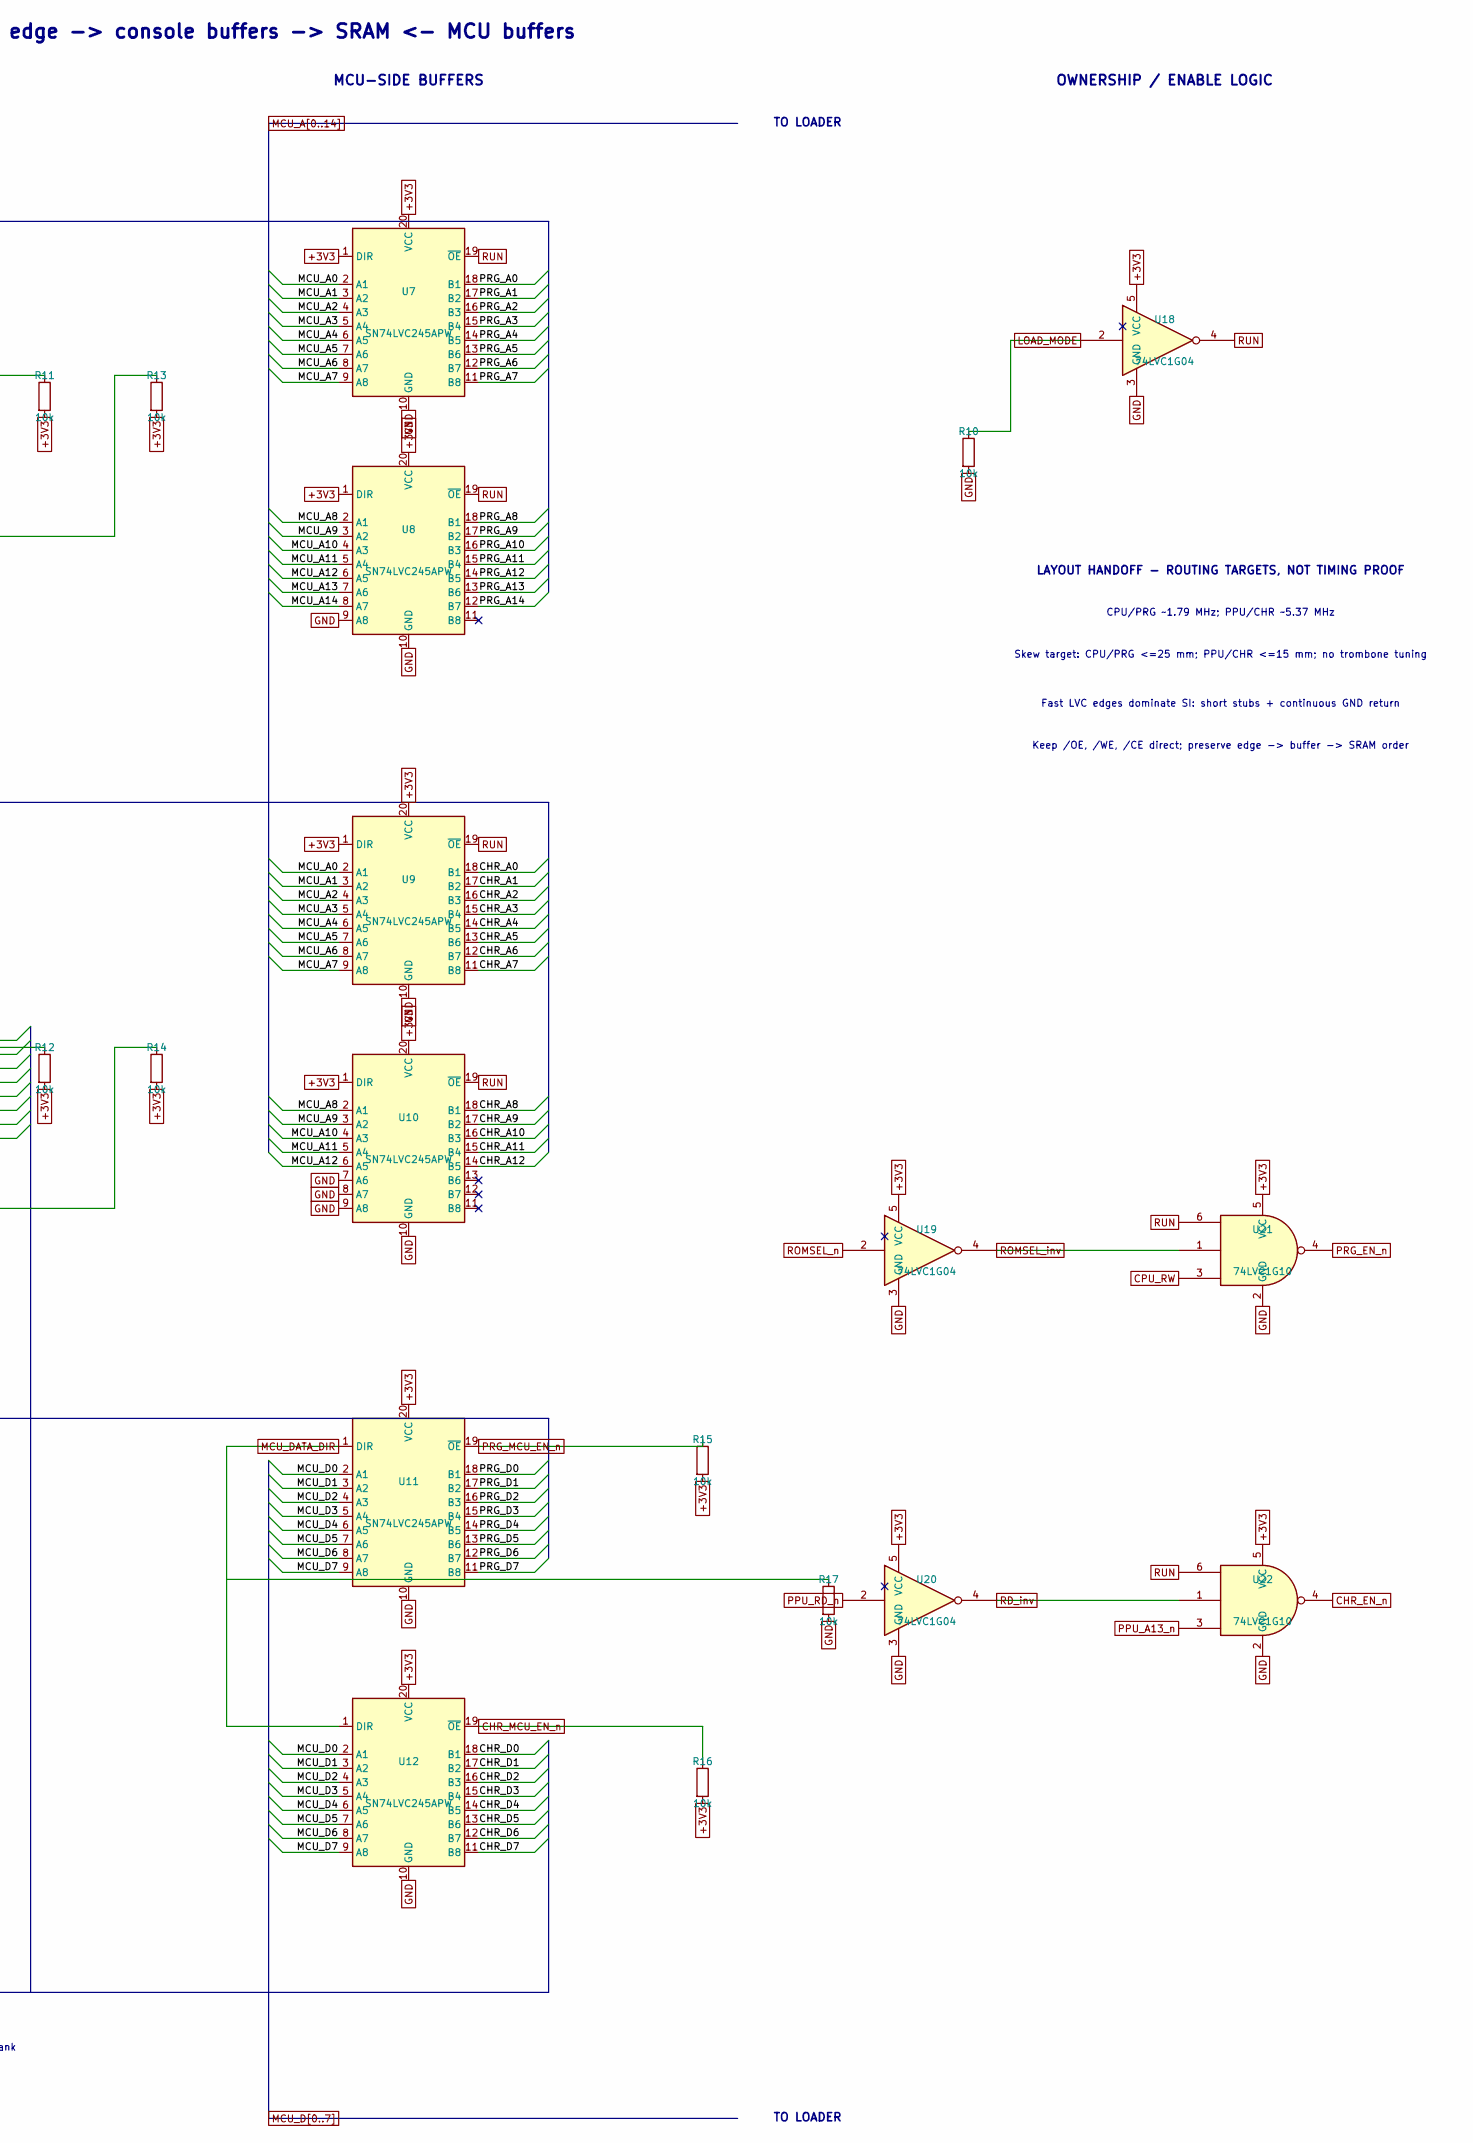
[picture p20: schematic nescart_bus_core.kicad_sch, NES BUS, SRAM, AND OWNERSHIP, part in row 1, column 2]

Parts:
J1: NES_Cart_Edge; cartridge_edge_72
R10, R11, R12, R13, R14, R15, R16, R17: 10k; R_0603_1608Metric; MPN 0603 10k 1%
U1, U2, U3, U4, U5, U6, U7, U8, U9, U10, U11, U12: SN74LVC245APW; TSSOP-20_4.4x6.5mm_P0.65mm; MPN SN74LVC245APWR
U13, U14: CY62128EV30; SOP-32_11.305x20.495mm_P1.27mm; MPN CY62128EV30LL-45SXIT; LCSC C2840304
U18, U19, U20: 74LVC1G04; SOT-353_SC-70-5; MPN SN74LVC1G04DCKR
U21, U22: 74LVC1G10; SOT-363_SC-70-6; MPN SN74LVC1G10DCKR

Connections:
CHR_A0: U3.18 (B1), U9.18 (B1), U14.12 (A0)
CHR_A1: U3.17 (B2), U9.17 (B2), U14.11 (A1)
CHR_A2: U3.16 (B3), U9.16 (B3), U14.10 (A2)
CHR_A3: U3.15 (B4), U9.15 (B4), U14.9 (A3)
CHR_A4: U3.14 (B5), U9.14 (B5), U14.8 (A4)
CHR_A5: U3.13 (B6), U9.13 (B6), U14.7 (A5)
CHR_A6: U3.12 (B7), U9.12 (B7), U14.6 (A6)
CHR_A7: U3.11 (B8), U9.11 (B8), U14.5 (A7)
CHR_A8: U4.18 (B1), U10.18 (B1), U14.27 (A8)
CHR_A9: U4.17 (B2), U10.17 (B2), U14.26 (A9)
CHR_A10: U4.16 (B3), U10.16 (B3), U14.23 (A10)
CHR_A11: U4.15 (B4), U10.15 (B4), U14.25 (A11)
CHR_A12: U4.14 (B5), U10.14 (B5), U14.4 (A12)
CHR_D0: U6.2 (A1), U12.18 (B1), U14.13 (DQ0)
CHR_D1: U6.3 (A2), U12.17 (B2), U14.14 (DQ1)
CHR_D2: U6.4 (A3), U12.16 (B3), U14.15 (DQ2)
CHR_D3: U6.5 (A4), U12.15 (B4), U14.17 (DQ3)
CHR_D4: U6.6 (A5), U12.14 (B5), U14.18 (DQ4)
CHR_D5: U6.7 (A6), U12.13 (B6), U14.19 (DQ5)
CHR_D6: U6.8 (A7), U12.12 (B7), U14.20 (DQ6)
CHR_D7: U6.9 (A8), U12.11 (B8), U14.21 (DQ7)
CHR_EN_n: U6.19 (~OE), U22.4
CHR_MCU_EN_n: R16.1, U12.19 (~OE); also elsewhere on the board
CHR_OE_n: R12.1, U14.24 (OE#); also elsewhere on the board
CHR_WE_n: R14.1, U14.29 (WE#); also elsewhere on the board
CIC_CLK: J1.71 (CIC_CLK); also elsewhere on the board
CIC_RST: J1.70 (CIC_/RST); also elsewhere on the board
CIC_TOMB: J1.35 (CIC_toMB); also elsewhere on the board
CIC_TOPAK: J1.34 (CIC_toPak); also elsewhere on the board
CIRAM_A10: J1.22 (CIRAM_A10); also elsewhere on the board
CPU_A0: J1.13 (CPU_A0), U1.2 (A1)
CPU_A1: J1.12 (CPU_A1), U1.3 (A2)
CPU_A2: J1.11 (CPU_A2), U1.4 (A3)
CPU_A3: J1.10 (CPU_A3), U1.5 (A4)
CPU_A4: J1.9 (CPU_A4), U1.6 (A5)
CPU_A5: J1.8 (CPU_A5), U1.7 (A6)
CPU_A6: J1.7 (CPU_A6), U1.8 (A7)
CPU_A7: J1.6 (CPU_A7), U1.9 (A8)
CPU_A8: J1.5 (CPU_A8), U2.2 (A1)
CPU_A9: J1.4 (CPU_A9), U2.3 (A2)
CPU_A10: J1.3 (CPU_A10), U2.4 (A3)
CPU_A11: J1.2 (CPU_A11), U2.5 (A4)
CPU_A12: J1.39 (CPU_A12), U2.6 (A5)
CPU_A13: J1.40 (CPU_A13), U2.7 (A6)
CPU_A14: J1.41 (CPU_A14), U2.8 (A7)
CPU_D0: J1.49 (CPU_D0), U5.18 (B1)
CPU_D1: J1.48 (CPU_D1), U5.17 (B2)
CPU_D2: J1.47 (CPU_D2), U5.16 (B3)
CPU_D3: J1.46 (CPU_D3), U5.15 (B4)
CPU_D4: J1.45 (CPU_D4), U5.14 (B5)
CPU_D5: J1.44 (CPU_D5), U5.13 (B6)
CPU_D6: J1.43 (CPU_D6), U5.12 (B7)
CPU_D7: J1.42 (CPU_D7), U5.11 (B8)
CPU_RW: J1.14 (CPU_R/W), U21.3
GND: J1.1 (GND), J1.72 (GND), R10.2, R17.2, U1.10 (GND), U2.9 (A8), U2.10 (GND), U3.10 (GND), U4.7 (A6), U4.8 (A7), U4.9 (A8), U4.10 (GND), U5.10 (GND), U6.10 (GND), U7.10 (GND), U8.9 (A8), U8.10 (GND), U9.10 (GND), U10.7 (A6), U10.8 (A7), U10.9 (A8), U10.10 (GND), U11.10 (GND), U12.10 (GND), U13.1 (NC / legacy addr), U13.2 (A16), U13.16 (VSS), U13.22 (CE#), U14.1 (NC / legacy addr), U14.2 (A16), U14.3 (A14), U14.16 (VSS), U14.22 (CE#), U14.28 (A13), U18.3 (GND), U19.3 (GND), U20.3 (GND), U21.2 (GND), U22.2 (GND); also elsewhere on the board
LOAD_MODE: R10.1, U1.19 (~OE), U2.19 (~OE), U3.19 (~OE), U4.19 (~OE), U18.2; also elsewhere on the board
MCU_A0: U7.2 (A1), U9.2 (A1); also elsewhere on the board
MCU_A1: U7.3 (A2), U9.3 (A2); also elsewhere on the board
MCU_A2: U7.4 (A3), U9.4 (A3); also elsewhere on the board
MCU_A3: U7.5 (A4), U9.5 (A4); also elsewhere on the board
MCU_A4: U7.6 (A5), U9.6 (A5); also elsewhere on the board
MCU_A5: U7.7 (A6), U9.7 (A6); also elsewhere on the board
MCU_A6: U7.8 (A7), U9.8 (A7); also elsewhere on the board
MCU_A7: U7.9 (A8), U9.9 (A8); also elsewhere on the board
MCU_A8: U8.2 (A1), U10.2 (A1); also elsewhere on the board
MCU_A9: U8.3 (A2), U10.3 (A2); also elsewhere on the board
MCU_A10: U8.4 (A3), U10.4 (A3); also elsewhere on the board
MCU_A11: U8.5 (A4), U10.5 (A4); also elsewhere on the board
MCU_A12: U8.6 (A5), U10.6 (A5); also elsewhere on the board
MCU_A13: U8.7 (A6); also elsewhere on the board
MCU_A14: U8.8 (A7); also elsewhere on the board
MCU_D0: U11.2 (A1), U12.2 (A1); also elsewhere on the board
MCU_D1: U11.3 (A2), U12.3 (A2); also elsewhere on the board
MCU_D2: U11.4 (A3), U12.4 (A3); also elsewhere on the board
MCU_D3: U11.5 (A4), U12.5 (A4); also elsewhere on the board
MCU_D4: U11.6 (A5), U12.6 (A5); also elsewhere on the board
MCU_D5: U11.7 (A6), U12.7 (A6); also elsewhere on the board
MCU_D6: U11.8 (A7), U12.8 (A7); also elsewhere on the board
MCU_D7: U11.9 (A8), U12.9 (A8); also elsewhere on the board
MCU_DATA_DIR: R17.1, U11.1 (DIR), U12.1 (DIR); also elsewhere on the board
NES_5V: J1.36 (+5V); also elsewhere on the board
PPU_A0: J1.29 (PPU_A0), U3.2 (A1)
PPU_A1: J1.28 (PPU_A1), U3.3 (A2)
PPU_A2: J1.27 (PPU_A2), U3.4 (A3)
PPU_A3: J1.26 (PPU_A3), U3.5 (A4)
PPU_A4: J1.25 (PPU_A4), U3.6 (A5)
PPU_A5: J1.24 (PPU_A5), U3.7 (A6)
PPU_A6: J1.23 (PPU_A6), U3.8 (A7)
PPU_A7: J1.59 (PPU_A7), U3.9 (A8)
PPU_A8: J1.60 (PPU_A8), U4.2 (A1)
PPU_A9: J1.61 (PPU_A9), U4.3 (A2)
PPU_A10: J1.63 (PPU_A10), U4.4 (A3); also elsewhere on the board
PPU_A11: J1.62 (PPU_A11), U4.5 (A4); also elsewhere on the board
PPU_A12: J1.64 (PPU_A12), U4.6 (A5)
PPU_A13_n: J1.57 (CIRAM_/CE), J1.58 (PPU_/A13), U22.3
PPU_D0: J1.30 (PPU_D0), U6.18 (B1)
PPU_D1: J1.31 (PPU_D1), U6.17 (B2)
PPU_D2: J1.32 (PPU_D2), U6.16 (B3)
PPU_D3: J1.33 (PPU_D3), U6.15 (B4)
PPU_D4: J1.69 (PPU_D4), U6.14 (B5)
PPU_D5: J1.68 (PPU_D5), U6.13 (B6)
PPU_D6: J1.67 (PPU_D6), U6.12 (B7)
PPU_D7: J1.66 (PPU_D7), U6.11 (B8)
PPU_RD_n: J1.21 (PPU_/RD), U20.2
PRG_A0: U1.18 (B1), U7.18 (B1), U13.12 (A0)
PRG_A1: U1.17 (B2), U7.17 (B2), U13.11 (A1)
PRG_A2: U1.16 (B3), U7.16 (B3), U13.10 (A2)
PRG_A3: U1.15 (B4), U7.15 (B4), U13.9 (A3)
PRG_A4: U1.14 (B5), U7.14 (B5), U13.8 (A4)
PRG_A5: U1.13 (B6), U7.13 (B6), U13.7 (A5)
PRG_A6: U1.12 (B7), U7.12 (B7), U13.6 (A6)
PRG_A7: U1.11 (B8), U7.11 (B8), U13.5 (A7)
PRG_A8: U2.18 (B1), U8.18 (B1), U13.27 (A8)
PRG_A9: U2.17 (B2), U8.17 (B2), U13.26 (A9)
PRG_A10: U2.16 (B3), U8.16 (B3), U13.23 (A10)
PRG_A11: U2.15 (B4), U8.15 (B4), U13.25 (A11)
PRG_A12: U2.14 (B5), U8.14 (B5), U13.4 (A12)
PRG_A13: U2.13 (B6), U8.13 (B6), U13.28 (A13)
PRG_A14: U2.12 (B7), U8.12 (B7), U13.3 (A14)
PRG_D0: U5.2 (A1), U11.18 (B1), U13.13 (DQ0)
PRG_D1: U5.3 (A2), U11.17 (B2), U13.14 (DQ1)
PRG_D2: U5.4 (A3), U11.16 (B3), U13.15 (DQ2)
PRG_D3: U5.5 (A4), U11.15 (B4), U13.17 (DQ3)
PRG_D4: U5.6 (A5), U11.14 (B5), U13.18 (DQ4)
PRG_D5: U5.7 (A6), U11.13 (B6), U13.19 (DQ5)
PRG_D6: U5.8 (A7), U11.12 (B7), U13.20 (DQ6)
PRG_D7: U5.9 (A8), U11.11 (B8), U13.21 (DQ7)
PRG_EN_n: U5.19 (~OE), U21.4
PRG_MCU_EN_n: R15.1, U11.19 (~OE); also elsewhere on the board
PRG_OE_n: R11.1, U13.24 (OE#); also elsewhere on the board
PRG_WE_n: R13.1, U13.29 (WE#); also elsewhere on the board
RD_inv: U20.4, U22.1
ROMSEL_inv: U19.4, U21.1
ROMSEL_n: J1.50 (/ROMSEL), U19.2
RUN: U7.19 (~OE), U8.19 (~OE), U9.19 (~OE), U10.19 (~OE), U18.4, U21.6, U22.6

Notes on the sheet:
NES BUS CORE | edge -> console buffers -> SRAM <- MCU buffers
CONSOLE-SIDE BUFFERS
PRG / CHR SRAM
U13 PRG SRAM - CY62128 (128K x 8)
U14 CHR SRAM - CY62128 (128K x 8)
MCU-SIDE BUFFERS
OWNERSHIP / ENABLE LOGIC
TO LOADER
LAYOUT HANDOFF - ROUTING TARGETS, NOT TIMING PROOF
CPU/PRG ~1.79 MHz; PPU/CHR ~5.37 MHz
Skew target: CPU/PRG <=25 mm; PPU/CHR <=15 mm; no trombone tuning
Fast LVC edges dominate SI: short stubs + continuous GND return
Keep /OE, /WE, /CE direct; preserve edge -> buffer -> SRAM order
SRAM FIT: CY62128 pin 30 CE2 + pin 31 unused A15 -> 3V3
Pin 1 NC -> GND for legacy footprint; fixed upper bits select one bank
U13 uses A0..A14 (32 KiB); U14 uses A0..A12 (8 KiB)

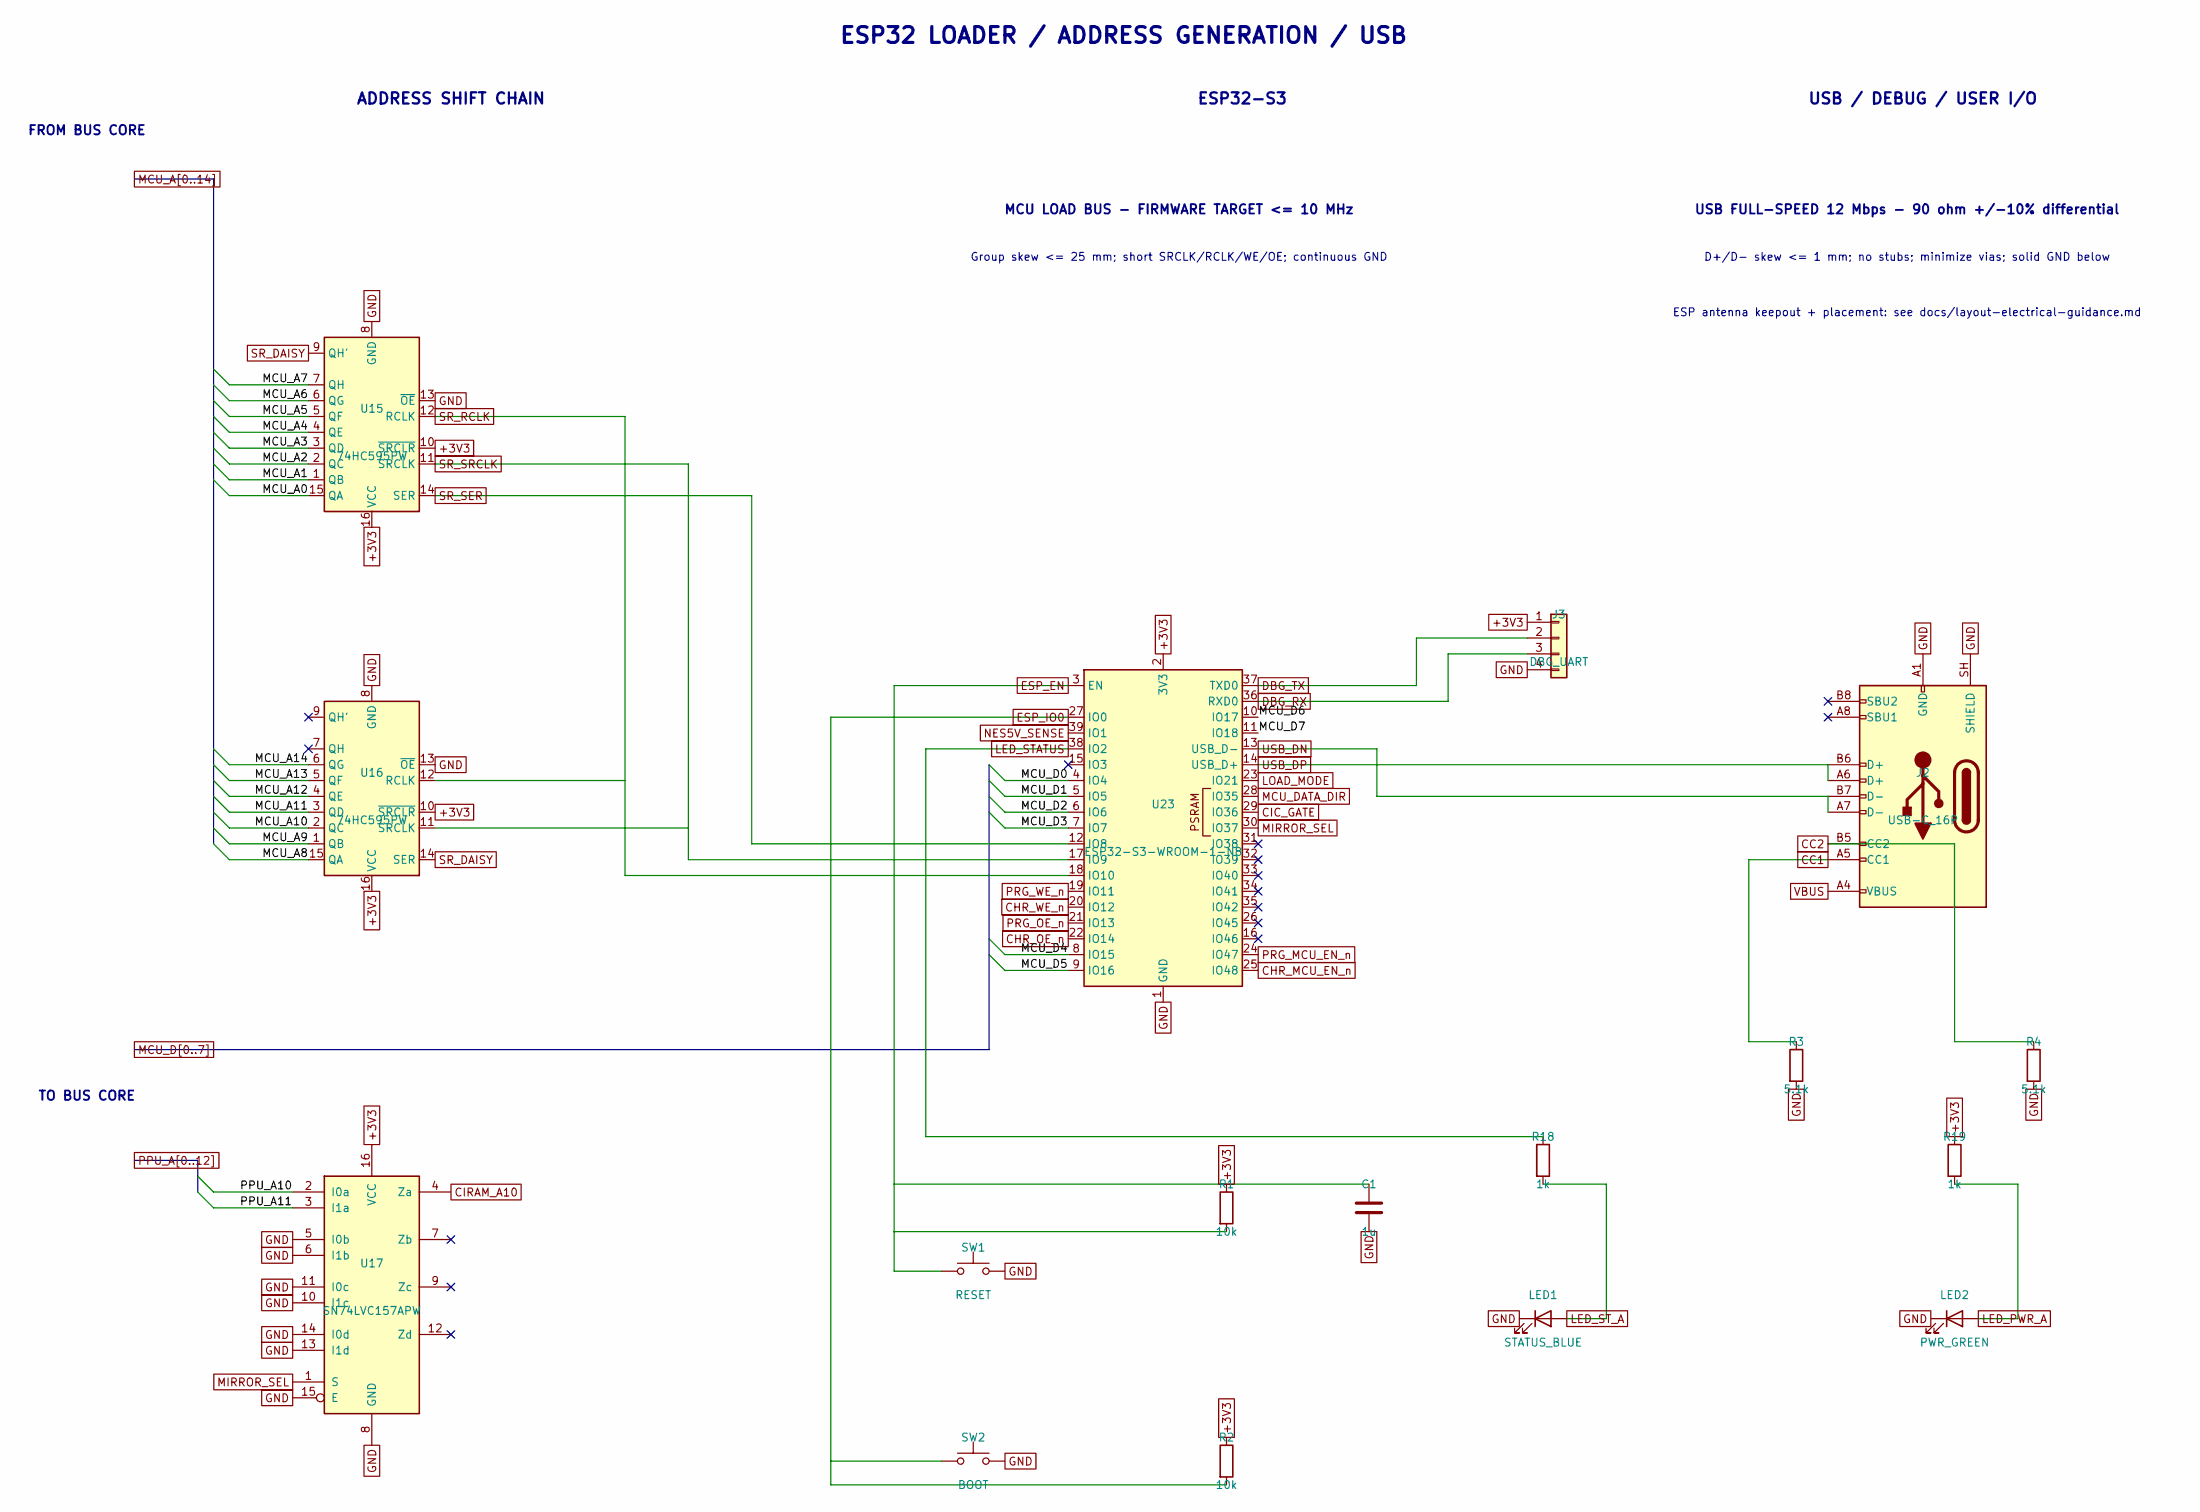
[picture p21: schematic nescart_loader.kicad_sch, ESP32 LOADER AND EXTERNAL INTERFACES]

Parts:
C1: 1u; C_0603_1608Metric; MPN 1u X7R
J2: USB-C_16P; USB_C_Receptacle_HRO_TYPE-C-31-M-12; MPN HRO TYPE-C-31-M-12
J3: DBG_UART; PinHeader_1x04_P2.54mm_Vertical; MPN PinHeader 1x4
LED1: STATUS_BLUE; LED_0603_1608Metric; MPN 0603 LED
LED2: PWR_GREEN; LED_0603_1608Metric; MPN 0603 LED
R1, R2: 10k; R_0603_1608Metric; MPN 0603 10k 1%
R3, R4: 5.1k; R_0603_1608Metric; MPN 0603 5.1k 1%
R18, R19: 1k; R_0603_1608Metric; MPN 0603 1k 1%
SW1: RESET; SW_SPST_B3U-1000P; MPN B3U-1000P
SW2: BOOT; SW_SPST_B3U-1000P; MPN B3U-1000P
U15, U16: 74HC595PW; TSSOP-16_4.4x5mm_P0.65mm; MPN SN74HC595PWR
U17: SN74LVC157APW; TSSOP-16_4.4x5mm_P0.65mm; MPN SN74LVC157APWR
U23: ESP32-S3-WROOM-1-N8; ESP32-S3-WROOM-1; MPN ESP32-S3-WROOM-1-N8

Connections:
CC1: J2.A5 (CC1), R3.1
CC2: J2.B5 (CC2), R4.1
CHR_MCU_EN_n: U23.25 (IO48); also elsewhere on the board
CHR_OE_n: U23.22 (IO14); also elsewhere on the board
CHR_WE_n: U23.20 (IO12); also elsewhere on the board
CIC_GATE: U23.29 (IO36); also elsewhere on the board
CIRAM_A10: U17.4 (Za); also elsewhere on the board
DBG_RX: J3.3, U23.36 (RXD0)
DBG_TX: J3.2, U23.37 (TXD0)
ESP_IO0: R2.2, SW2.1, U23.27 (IO0)
GND: C1.2, J2.A1 (GND), J2.A12 (GND), J2.B1 (GND), J2.B12 (GND), J2.SH (SHIELD), J3.4, LED1.1 (K), LED2.1 (K), R3.2, R4.2, SW1.2, SW2.2, U15.8 (GND), U15.13 (~OE), U16.8 (GND), U16.13 (~OE), U17.5 (I0b), U17.6 (I1b), U17.8 (GND), U17.10 (I1c), U17.11 (I0c), U17.13 (I1d), U17.14 (I0d), U17.15 (E), U23.1 (GND), U23.40 (GND), U23.41 (GND); also elsewhere on the board
LED_PWR_A: LED2.2 (A), R19.2
LED_STATUS: R18.1, U23.38 (IO2)
LED_ST_A: LED1.2 (A), R18.2
LOAD_MODE: U23.23 (IO21); also elsewhere on the board
MCU_A0: U15.15 (QA); also elsewhere on the board
MCU_A1: U15.1 (QB); also elsewhere on the board
MCU_A2: U15.2 (QC); also elsewhere on the board
MCU_A3: U15.3 (QD); also elsewhere on the board
MCU_A4: U15.4 (QE); also elsewhere on the board
MCU_A5: U15.5 (QF); also elsewhere on the board
MCU_A6: U15.6 (QG); also elsewhere on the board
MCU_A7: U15.7 (QH); also elsewhere on the board
MCU_A8: U16.15 (QA); also elsewhere on the board
MCU_A9: U16.1 (QB); also elsewhere on the board
MCU_A10: U16.2 (QC); also elsewhere on the board
MCU_A11: U16.3 (QD); also elsewhere on the board
MCU_A12: U16.4 (QE); also elsewhere on the board
MCU_A13: U16.5 (QF); also elsewhere on the board
MCU_A14: U16.6 (QG); also elsewhere on the board
MCU_D0: U23.4 (IO4); also elsewhere on the board
MCU_D1: U23.5 (IO5); also elsewhere on the board
MCU_D2: U23.6 (IO6); also elsewhere on the board
MCU_D3: U23.7 (IO7); also elsewhere on the board
MCU_D4: U23.8 (IO15); also elsewhere on the board
MCU_D5: U23.9 (IO16); also elsewhere on the board
MCU_D6: U23.10 (IO17); also elsewhere on the board
MCU_D7: U23.11 (IO18); also elsewhere on the board
MCU_DATA_DIR: U23.28 (IO35); also elsewhere on the board
MIRROR_SEL: U17.1 (S), U23.30 (IO37)
NES5V_SENSE: U23.39 (IO1); also elsewhere on the board
PPU_A10: U17.2 (I0a); also elsewhere on the board
PPU_A11: U17.3 (I1a); also elsewhere on the board
PRG_MCU_EN_n: U23.24 (IO47); also elsewhere on the board
PRG_OE_n: U23.21 (IO13); also elsewhere on the board
PRG_WE_n: U23.19 (IO11); also elsewhere on the board
SR_DAISY: U15.9 (QH'), U16.14 (SER)
SR_RCLK: U15.12 (RCLK), U16.12 (RCLK), U23.18 (IO10)
SR_SER: U15.14 (SER), U23.12 (IO8)
SR_SRCLK: U15.11 (SRCLK), U16.11 (SRCLK), U23.17 (IO9)
USB_DN: J2.A7 (D-), J2.B7 (D-), U23.13 (USB_D-)
USB_DP: J2.A6 (D+), J2.B6 (D+), U23.14 (USB_D+)
VBUS: J2.A4 (VBUS), J2.A9 (VBUS), J2.B4 (VBUS), J2.B9 (VBUS); also elsewhere on the board

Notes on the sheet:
ESP32 LOADER / ADDRESS GENERATION / USB
ADDRESS SHIFT CHAIN
ESP32-S3
USB / DEBUG / USER I/O
FROM BUS CORE
TO BUS CORE
MCU LOAD BUS - FIRMWARE TARGET <= 10 MHz
Group skew <= 25 mm; short SRCLK/RCLK/WE/OE; continuous GND
USB FULL-SPEED 12 Mbps - 90 ohm +/-10% differential
D+/D- skew <= 1 mm; no stubs; minimize vias; solid GND below
ESP antenna keepout + placement: see docs/layout-electrical-guidance.md

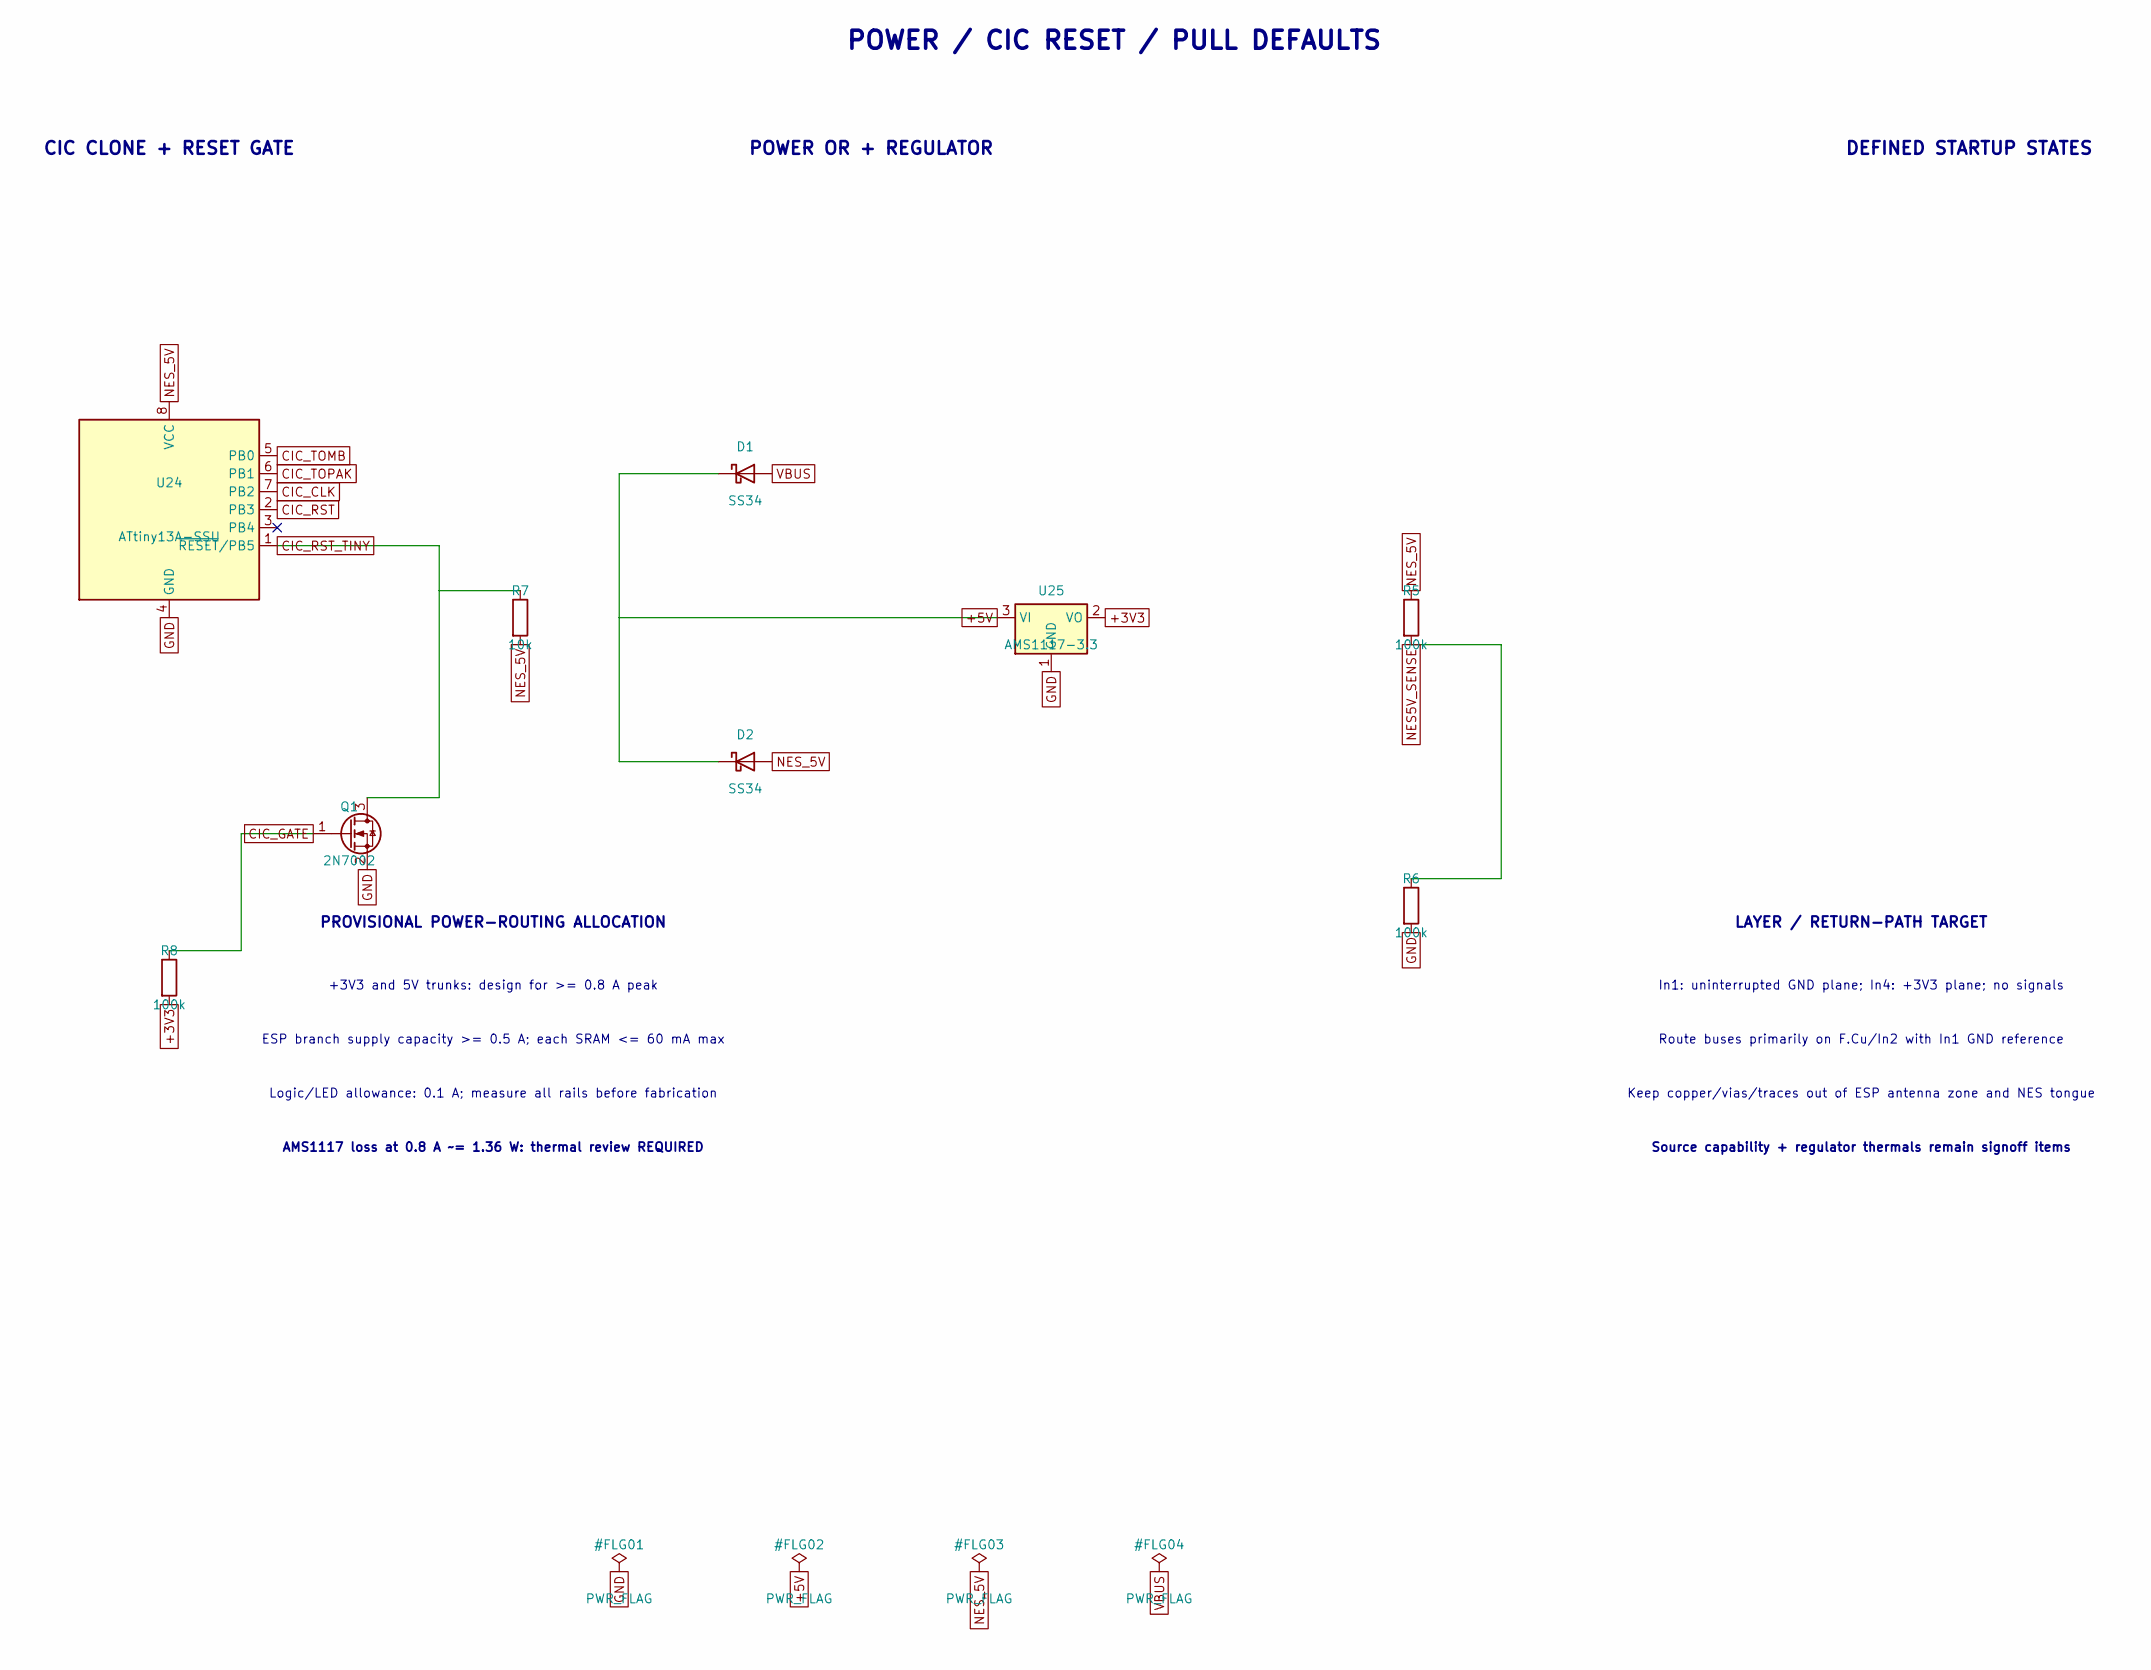
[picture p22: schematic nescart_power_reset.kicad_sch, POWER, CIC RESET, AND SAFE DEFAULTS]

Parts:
D1, D2: SS34; D_SMA; MPN SS34
Q1: 2N7002; SOT-23; MPN 2N7002
R5, R6, R8: 100k; R_0603_1608Metric; MPN 0603 100k 1%
R7: 10k; R_0603_1608Metric; MPN 0603 10k 1%
U24: ATtiny13A-SSU; SOIC-8_3.9x4.9mm_P1.27mm; MPN ATTINY13A-SSU
U25: AMS1117-3.3; SOT-223-3_TabPin2; MPN AMS1117-3.3

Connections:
+5V: D1.1 (K), D2.1 (K), U25.3 (VI); also elsewhere on the board
CIC_CLK: U24.7 (PB2); also elsewhere on the board
CIC_GATE: Q1.1 (G), R8.1; also elsewhere on the board
CIC_RST: U24.2 (PB3); also elsewhere on the board
CIC_RST_TINY: Q1.3 (D), R7.1, U24.1 (~RESET/PB5)
CIC_TOMB: U24.5 (PB0); also elsewhere on the board
CIC_TOPAK: U24.6 (PB1); also elsewhere on the board
GND: Q1.2 (S), R6.2, U24.4 (GND), U25.1 (GND); also elsewhere on the board
NES5V_SENSE: R5.2, R6.1; also elsewhere on the board
NES_5V: D2.2 (A), R5.1, R7.2, U24.8 (VCC); also elsewhere on the board
VBUS: D1.2 (A); also elsewhere on the board

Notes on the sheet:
POWER / CIC RESET / PULL DEFAULTS
CIC CLONE + RESET GATE
POWER OR + REGULATOR
DEFINED STARTUP STATES
PROVISIONAL POWER-ROUTING ALLOCATION
+3V3 and 5V trunks: design for >= 0.8 A peak
ESP branch supply capacity >= 0.5 A; each SRAM <= 60 mA max
Logic/LED allowance: 0.1 A; measure all rails before fabrication
AMS1117 loss at 0.8 A ~= 1.36 W: thermal review REQUIRED
LAYER / RETURN-PATH TARGET
In1: uninterrupted GND plane; In4: +3V3 plane; no signals
Route buses primarily on F.Cu/In2 with In1 GND reference
Keep copper/vias/traces out of ESP antenna zone and NES tongue
Source capability + regulator thermals remain signoff items

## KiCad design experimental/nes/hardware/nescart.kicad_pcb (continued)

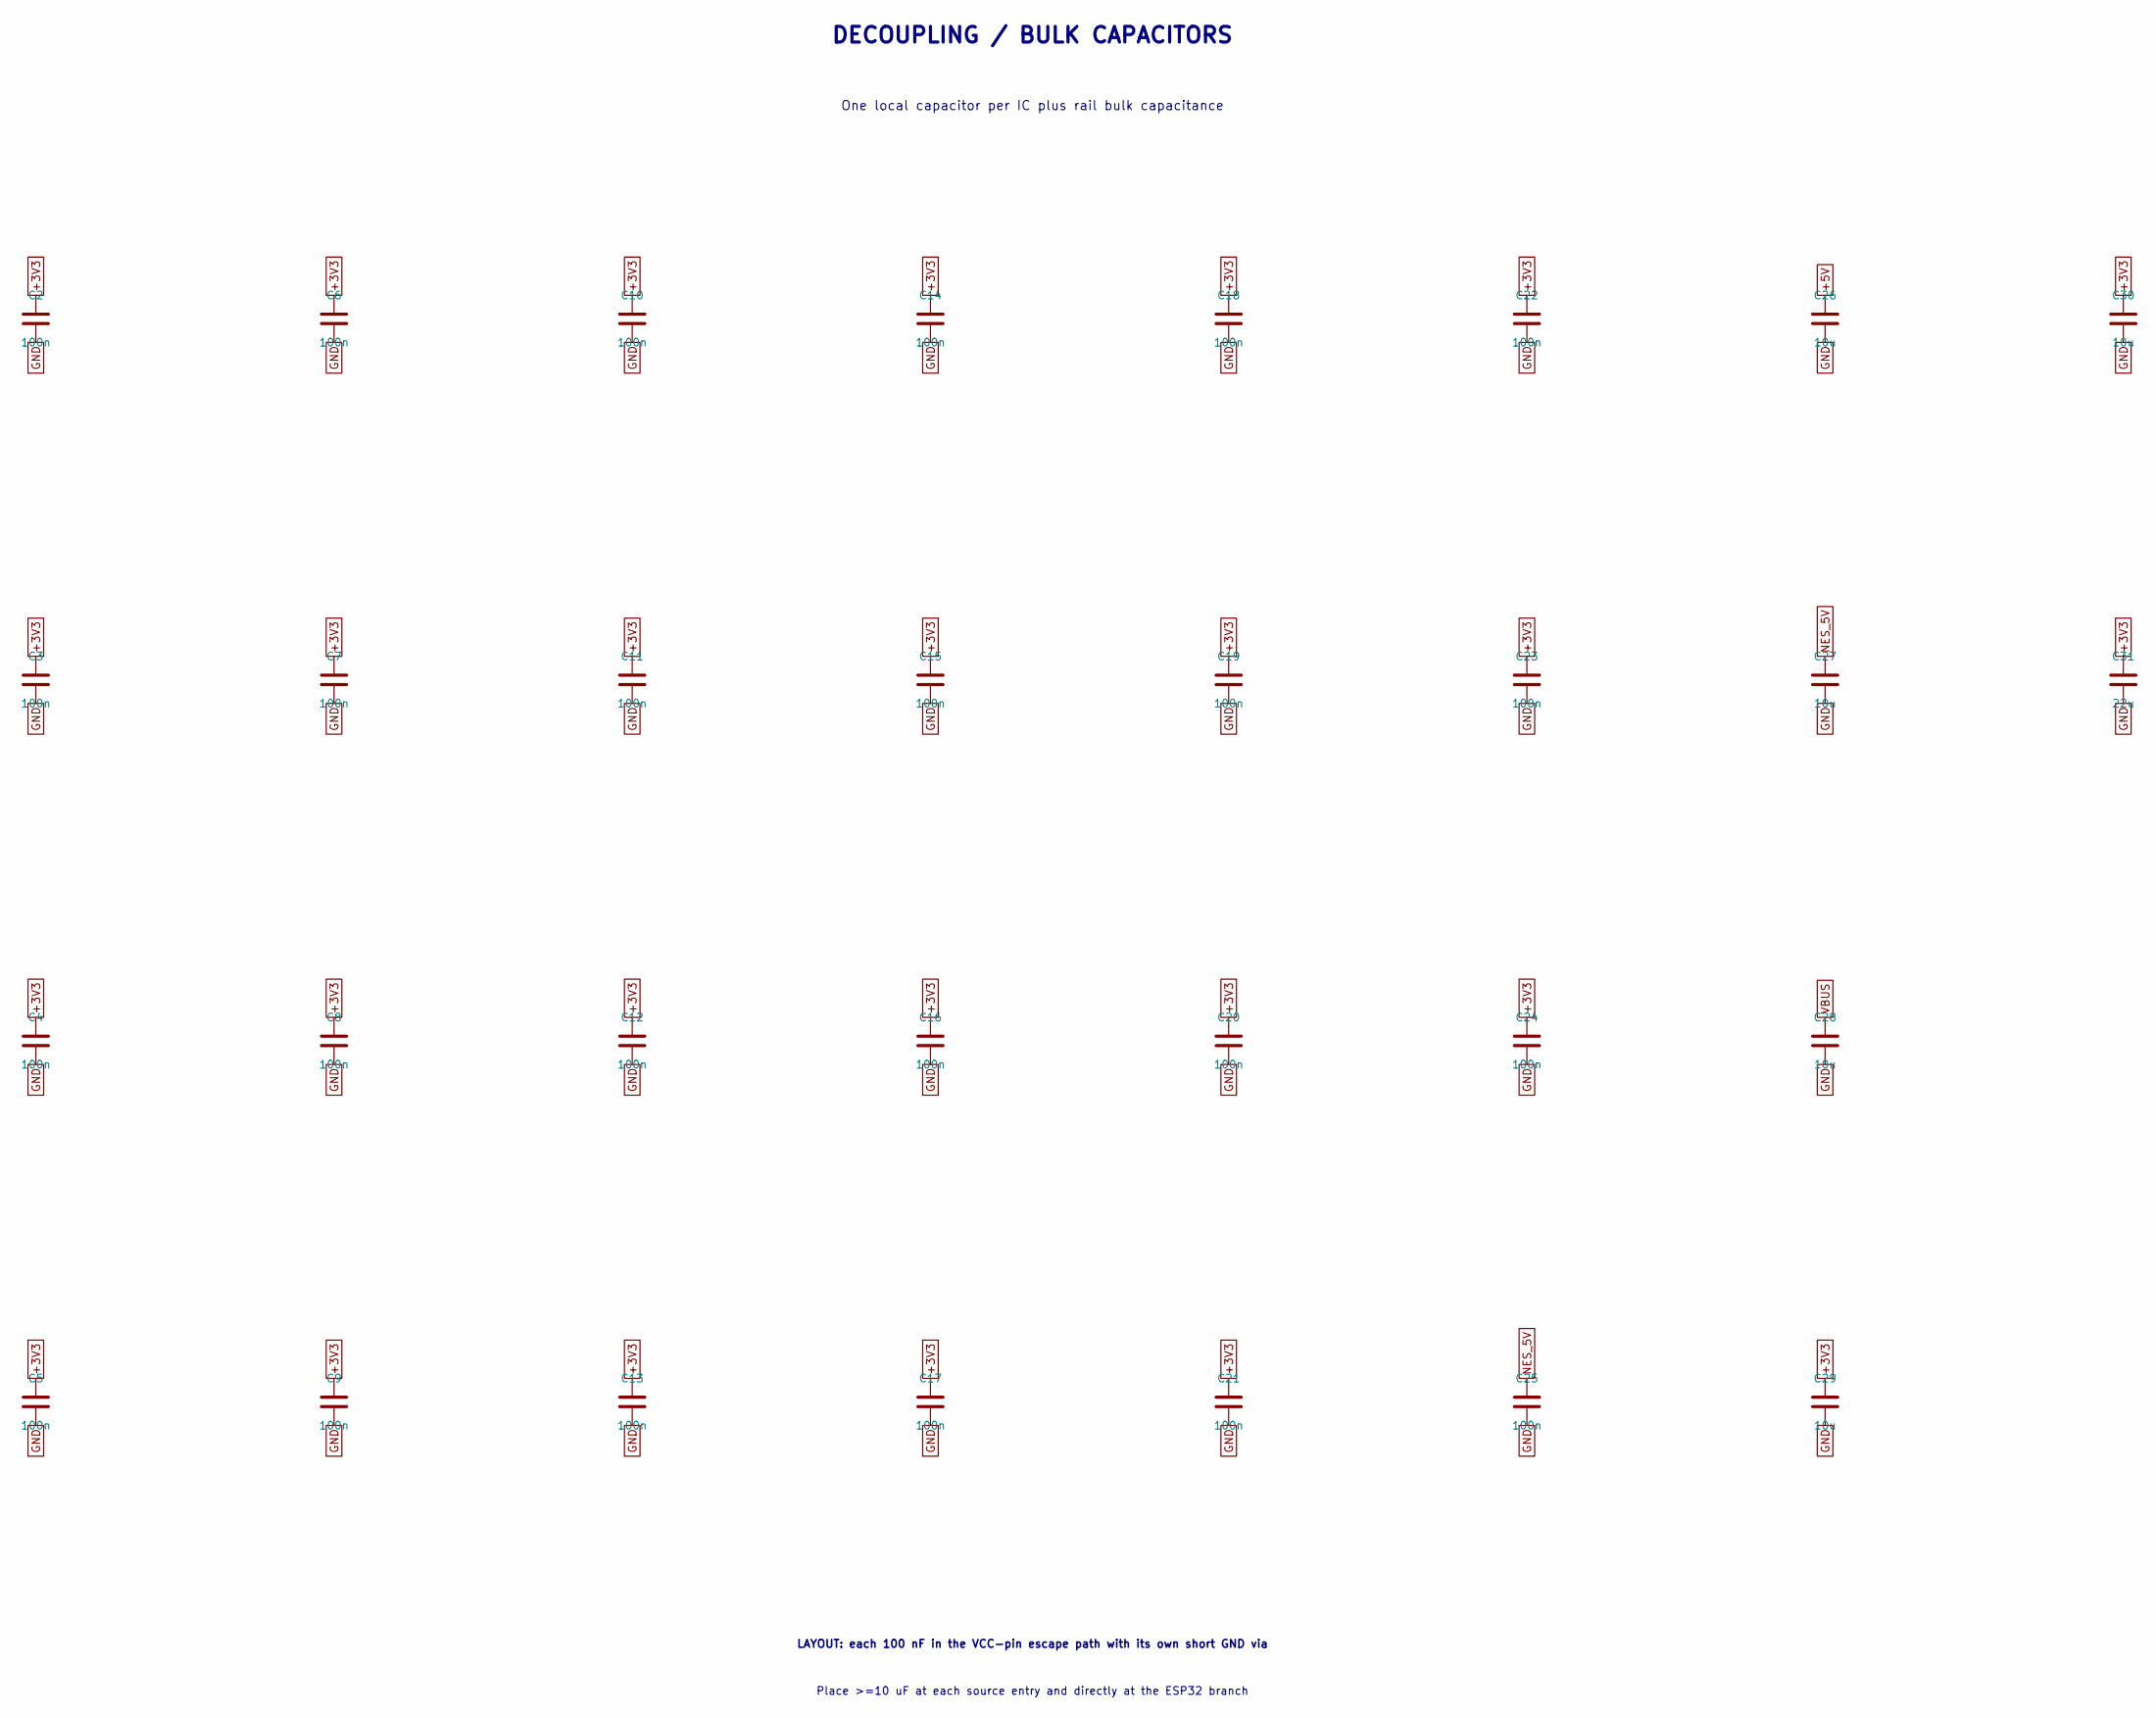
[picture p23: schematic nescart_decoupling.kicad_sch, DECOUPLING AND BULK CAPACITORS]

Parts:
C2, C3, C4, C5, C6, C7, C8, C9, C10, C11, C12, C13, C14, C15, C16, C17, C18, C19, C20, C21, C22, C23, C24, C25: 100n; C_0603_1608Metric; MPN 100n X7R
C26, C27, C28, C29, C30: 10u; C_0805_2012Metric; MPN 10u X7R
C31: 22u; C_0805_2012Metric; MPN 22u X7R

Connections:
+5V: C26.1; also elsewhere on the board
GND: C2.2, C3.2, C4.2, C5.2, C6.2, C7.2, C8.2, C9.2, C10.2, C11.2, C12.2, C13.2, C14.2, C15.2, C16.2, C17.2, C18.2, C19.2, C20.2, C21.2, C22.2, C23.2, C24.2, C25.2, C26.2, C27.2, C28.2, C29.2, C30.2, C31.2; also elsewhere on the board
NES_5V: C25.1, C27.1; also elsewhere on the board
VBUS: C28.1; also elsewhere on the board

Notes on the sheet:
DECOUPLING / BULK CAPACITORS
One local capacitor per IC plus rail bulk capacitance
LAYOUT: each 100 nF in the VCC-pin escape path with its own short GND via
Place >=10 uF at each source entry and directly at the ESP32 branch

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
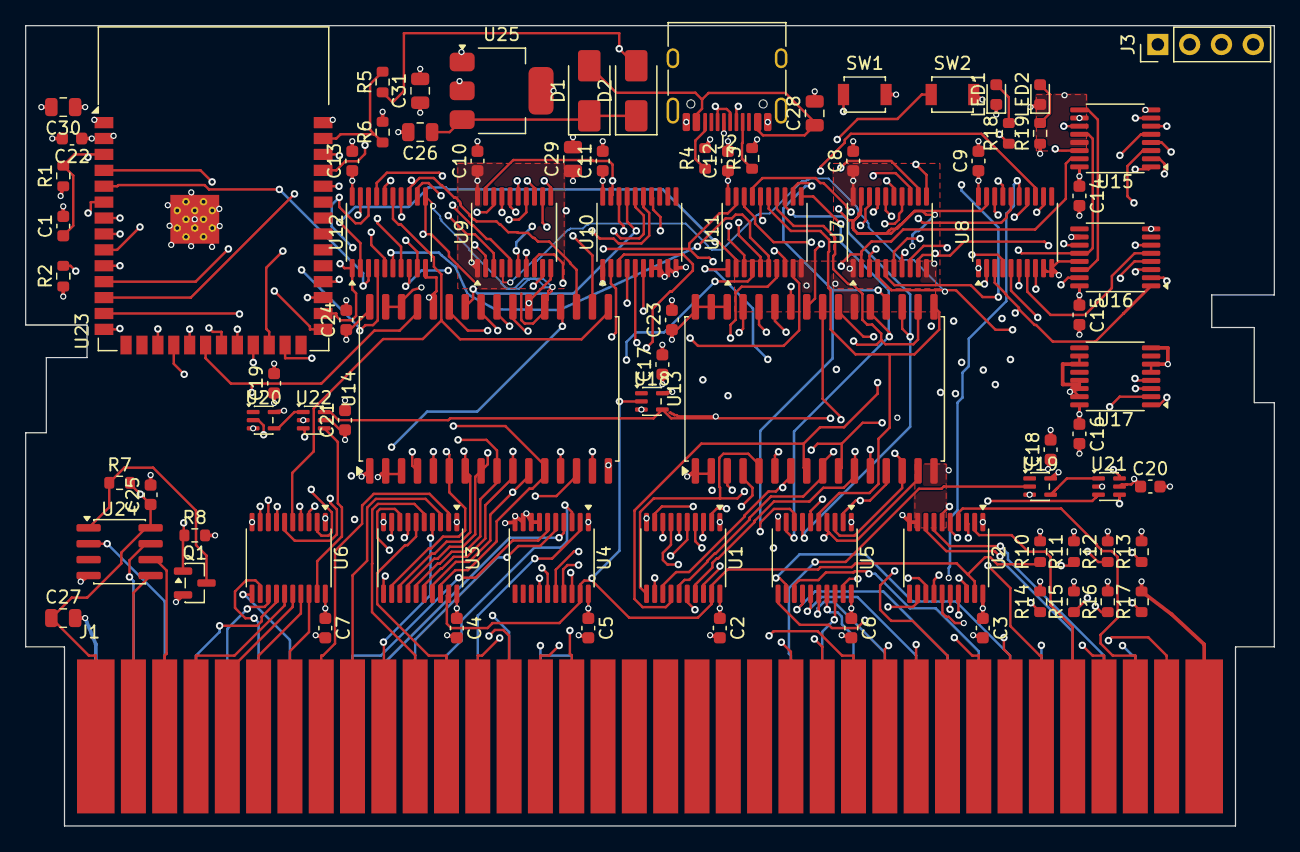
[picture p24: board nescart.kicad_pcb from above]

Board: 6 copper layers, 99.7 x 63.9 mm, 84 parts (0 on the bottom side), 157 nets.

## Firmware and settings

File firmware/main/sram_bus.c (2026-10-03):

#include "sram_bus.h"

#include <inttypes.h>

#include "board_pins.h"
#include "driver/gpio.h"
#include "esp_log.h"
#include "esp_rom_sys.h"
#include "esp_timer.h"
#include "freertos/FreeRTOS.h"
#include "freertos/task.h"

typedef enum { CHIP_PRG, CHIP_CHR } sram_chip_t;

static const char *TAG = "sram_bus";
static const gpio_num_t DATA_PINS[8] = {
    PIN_MCU_D0, PIN_MCU_D1, PIN_MCU_D2, PIN_MCU_D3,
    PIN_MCU_D4, PIN_MCU_D5, PIN_MCU_D6, PIN_MCU_D7,
};
static bool s_console_exposed;

static void set_data_input(void)
{
    for (unsigned bit = 0; bit < 8; ++bit) {
        gpio_set_direction(DATA_PINS[bit], GPIO_MODE_INPUT);
        gpio_set_pull_mode(DATA_PINS[bit], GPIO_FLOATING);
    }
}

static void set_data_output(uint8_t value)
{
    for (unsigned bit = 0; bit < 8; ++bit) {
        gpio_set_level(DATA_PINS[bit], (value >> bit) & 1u);
    }
    for (unsigned bit = 0; bit < 8; ++bit) {
        gpio_set_direction(DATA_PINS[bit], GPIO_MODE_OUTPUT);
    }
}

static uint8_t read_data(void)
{
    uint8_t value = 0;
    for (unsigned bit = 0; bit < 8; ++bit) {
        value |= (uint8_t)(gpio_get_level(DATA_PINS[bit]) << bit);
    }
    return value;
}

static void set_address(uint16_t address)
{
    /* Send A15 first so U15 ends with A0..A7 and U16 with A8..A15. */
    for (int bit = 15; bit >= 0; --bit) {
        gpio_set_level(PIN_SR_SER, (address >> bit) & 1u);
        gpio_set_level(PIN_SR_SRCLK, 1);
        esp_rom_delay_us(1);
        gpio_set_level(PIN_SR_SRCLK, 0);
    }
    gpio_set_level(PIN_SR_RCLK, 1);
    esp_rom_delay_us(1);
    gpio_set_level(PIN_SR_RCLK, 0);
}

static gpio_num_t chip_enable_pin(sram_chip_t chip)
{
    return chip == CHIP_PRG ? PIN_PRG_MCU_EN_N : PIN_CHR_MCU_EN_N;
}

static gpio_num_t chip_oe_pin(sram_chip_t chip)
{
    return chip == CHIP_PRG ? PIN_PRG_OE_N : PIN_CHR_OE_N;
}

static gpio_num_t chip_we_pin(sram_chip_t chip)
{
    return chip == CHIP_PRG ? PIN_PRG_WE_N : PIN_CHR_WE_N;
}

static void disable_mcu_data_buffers(void)
{
    gpio_set_level(PIN_PRG_MCU_EN_N, 1);
    gpio_set_level(PIN_CHR_MCU_EN_N, 1);
}

void sram_bus_hold_isolated(void)
{
    disable_mcu_data_buffers();
    gpio_set_level(PIN_PRG_WE_N, 1);
    gpio_set_level(PIN_CHR_WE_N, 1);
    gpio_set_level(PIN_PRG_OE_N, 1);
    gpio_set_level(PIN_CHR_OE_N, 1);
    set_data_input();
    gpio_set_level(PIN_MCU_DATA_DIR, 0);
    /* HIGH disables console-side buffers; inverted RUN LOW enables MCU address path. */
    gpio_set_level(PIN_LOAD_MODE, 1);
    s_console_exposed = false;
}

esp_err_t sram_bus_init_safe(void)
{
    const gpio_num_t outputs[] = {
        PIN_SR_SER, PIN_SR_SRCLK, PIN_SR_RCLK,
        PIN_PRG_WE_N, PIN_CHR_WE_N, PIN_PRG_OE_N, PIN_CHR_OE_N,
        PIN_PRG_MCU_EN_N, PIN_CHR_MCU_EN_N, PIN_MCU_DATA_DIR,
        PIN_MIRROR_SEL,
    };

    /* Preload safe values before enabling each output driver. */
    gpio_set_level(PIN_SR_SER, 0);
    gpio_set_level(PIN_SR_SRCLK, 0);
    gpio_set_level(PIN_SR_RCLK, 0);
    gpio_set_level(PIN_PRG_WE_N, 1);
    gpio_set_level(PIN_CHR_WE_N, 1);
    gpio_set_level(PIN_PRG_OE_N, 1);
    gpio_set_level(PIN_CHR_OE_N, 1);
    gpio_set_level(PIN_PRG_MCU_EN_N, 1);
    gpio_set_level(PIN_CHR_MCU_EN_N, 1);
    gpio_set_level(PIN_MCU_DATA_DIR, 0);
    gpio_set_level(PIN_MIRROR_SEL, 0);

    for (size_t i = 0; i < sizeof(outputs) / sizeof(outputs[0]); ++i) {
        ESP_ERROR_CHECK(gpio_set_direction(outputs[i], GPIO_MODE_OUTPUT));
    }
    set_data_input();

    gpio_set_level(PIN_LOAD_MODE, 1);
    ESP_ERROR_CHECK(gpio_set_direction(PIN_LOAD_MODE, GPIO_MODE_OUTPUT));
    s_console_exposed = false;
    ESP_LOGI(TAG, "safe LOAD topology asserted");
    return ESP_OK;
}

static esp_err_t write_region(sram_chip_t chip, const uint8_t *data, size_t length)
{
    const gpio_num_t enable = chip_enable_pin(chip);
    const gpio_num_t we = chip_we_pin(chip);
    gpio_set_level(chip_oe_pin(chip), 1);
    gpio_set_level(PIN_MCU_DATA_DIR, 1); /* U11/U12 A (ESP) -> B (SRAM). */
    set_data_output(0);
    gpio_set_level(enable, 0);

    for (size_t address = 0; address < length; ++address) {
        set_address((uint16_t)address);
        set_data_output(data[address]);
        gpio_set_level(we, 0);
        esp_rom_delay_us(1);
        gpio_set_level(we, 1);
        if ((address & 0x3ffu) == 0x3ffu) {
            vTaskDelay(1);
        }
    }
    gpio_set_level(enable, 1);
    set_data_input();
    gpio_set_level(PIN_MCU_DATA_DIR, 0);
    return ESP_OK;
}

static esp_err_t verify_region(sram_chip_t chip, const uint8_t *expected,
                               size_t length, uint32_t *verified_crc)
{
    const gpio_num_t enable = chip_enable_pin(chip);
    const gpio_num_t oe = chip_oe_pin(chip);
    set_data_input();
    gpio_set_level(PIN_MCU_DATA_DIR, 0); /* SRAM B -> ESP A. */
    gpio_set_level(enable, 0);
    gpio_set_level(oe, 0);

    uint32_t crc = nescart_crc32_begin();
    for (size_t address = 0; address < length; ++address) {
        set_address((uint16_t)address);
        esp_rom_delay_us(1);
        const uint8_t actual = read_data();
        crc = nescart_crc32_update(crc, &actual, 1);
        if (actual != expected[address]) {
            ESP_LOGE(TAG, "%s verify mismatch at 0x%04x: expected %02x got %02x",
                     chip == CHIP_PRG ? "PRG" : "CHR", (unsigned)address,
                     expected[address], actual);
            gpio_set_level(oe, 1);
            gpio_set_level(enable, 1);
            return ESP_ERR_INVALID_CRC;
        }
        if ((address & 0x3ffu) == 0x3ffu) {
            vTaskDelay(1);
        }
    }
    gpio_set_level(oe, 1);
    gpio_set_level(enable, 1);
    *verified_crc = nescart_crc32_finish(crc);
    return ESP_OK;
}

void sram_bus_expose_to_console(nescart_mirroring_t mirroring)
{
    disable_mcu_data_buffers();
    set_data_input();
    gpio_set_level(PIN_MCU_DATA_DIR, 0);
    gpio_set_level(PIN_PRG_WE_N, 1);
    gpio_set_level(PIN_CHR_WE_N, 1);
    gpio_set_level(PIN_MIRROR_SEL,
                   mirroring == NESCART_MIRROR_HORIZONTAL ? 1 : 0);
    gpio_set_level(PIN_PRG_OE_N, 0);
    gpio_set_level(PIN_CHR_OE_N, 0);
    esp_rom_delay_us(2);
    gpio_set_level(PIN_LOAD_MODE, 0);
    s_console_exposed = true;
}
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

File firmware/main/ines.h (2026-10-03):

#pragma once

#include <stdbool.h>
#include <stddef.h>
#include <stdint.h>

#define NESCART_PRG_SIZE (32u * 1024u)
#define NESCART_CHR_SIZE (8u * 1024u)
#define NESCART_IMAGE_SIZE (NESCART_PRG_SIZE + NESCART_CHR_SIZE)
#define NESCART_MAX_INES_SIZE (16u + 512u + NESCART_IMAGE_SIZE)

typedef enum {
    NESCART_MIRROR_VERTICAL = 0,
    NESCART_MIRROR_HORIZONTAL = 1,
} nescart_mirroring_t;

typedef struct {
    uint8_t data[NESCART_IMAGE_SIZE];
    nescart_mirroring_t mirroring;
    uint32_t crc32;
} nescart_image_t;

uint32_t nescart_crc32_begin(void);
uint32_t nescart_crc32_update(uint32_t state, const void *data, size_t length);
uint32_t nescart_crc32_finish(uint32_t state);
uint32_t nescart_crc32(const void *data, size_t length);

int ines_normalize(const uint8_t *input, size_t input_length,
                   nescart_image_t *output, char *error, size_t error_length);
/* Reader returns 0 only after filling exactly length bytes. */
typedef int (*ines_read_exact_fn)(void *context, uint8_t *output, size_t length);
int ines_normalize_stream(ines_read_exact_fn read_exact, void *context,
                          size_t input_length, nescart_image_t *output,
                          char *error, size_t error_length);
bool nescart_image_equal(const nescart_image_t *left,
                         const nescart_image_t *right);

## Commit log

2026-07-19 feat(release): publish FC ROM Vomitter (#1) (#2)
    * feat: publish FC ROM Vomitter design
    * fix: preserve release artifact hashes
    [00_nescart-fc-engineering-BOM.csv, 01_nescart-fc-positions-source.csv, 02_nescart-fc-BOM-jlcpcb.csv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]
2026-08-07 feat: publish ESP32 Mapper-3 experiment (#6)
    [partitions.csv]
2026-09-22 feat: add Cloudflare exhibition ROM queue / 展示向けROMキュー (#14)
    * feat: add Cloudflare exhibition ROM queue
    * test: verify private ROM downloads
2026-09-22 Visitor ROM gallery below upload / ROMアップロード直下に公開ギャラリー (#20)
    * Add opt-in ROM gallery below visitor upload
    * Make gallery withdrawal test identify source job
    * Require same-origin gallery queue request
    * Schedule expired ROM cleanup
2026-10-03 Document NES-SDR integration branch hardware test flow
2026-10-03 Make every NES-SDR frame refresh signature-atomic
2026-10-03 Target 5 Hz NES-SDR RF refresh
2026-10-03 Document 5 Hz NES-SDR target
2026-10-03 Serialize NES-SDR RF cycles and log frame timing
2026-10-03 Set NES-SDR live refresh target to 4 Hz
2026-10-03 Revert "Set NES-SDR live refresh target to 4 Hz"
    This reverts commit b822fee44050a2ce2a0193aeaef872c91abf3664.
2026-10-03 Add repeatable HTTP stability checks with USB diagnostics
    [web_stability.py]
2026-10-04 Trace AP receive handoff and failed heap allocations
    [serial_status.py]
2026-10-07 Bound normal AP upload stalls and browser actions

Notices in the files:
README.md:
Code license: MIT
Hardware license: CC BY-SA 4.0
